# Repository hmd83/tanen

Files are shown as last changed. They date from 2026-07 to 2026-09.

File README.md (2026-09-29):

# TanenBase — Smart Hive Monitoring





A LoRaWAN beehive monitor that runs for years on three AAA primary lithium cells.

It weighs the hive, reads its temperature — and, with optional Bluetooth sensors,
temperature and humidity inside the hive — and reports over LoRaWAN to The Things
Network — then sleeps at about **4 µA**. Configuration and calibration happen
over Bluetooth from a web page, so there is no mobile app to install and nothing
to plug in once the lid is closed.

| | |
|---|---|
| **MCU** | Seeed Studio XIAO nRF54LM20A (Standard, non-Sense) |
| **Radio** | Wio-SX1262 LoRa kit — LoRaWAN Class A, OTAA, EU868 |
| **Sensors** | NAU7802 24-bit load-cell ADC · DS18B20 temperature · nPM1300 battery gauge · optional: up to 3 SwitchBot Outdoor Meter BLE temperature/humidity sensors (Extended Mode) |
| **RTOS / SDK** | Zephyr 4.4 via nRF Connect SDK v3.4.0 |
| **Sleep current** | ~4 µA (System OFF + GRTC wake) |
| **Battery life** | ~4.6 years on 3× AAA Li/FeS₂ (1200 mAh) at 15 min / 2 h reporting — ~10 y at 60 min / 4 h. With Extended Mode BLE sensors each uplink costs 139 mC instead of 63 mC: ~3.3 y / ~7 y |
| **Uplink** | 8 bytes — weight (999 kg range), temperature, battery, flags · +5 bytes per BLE sensor heard (max 23) |

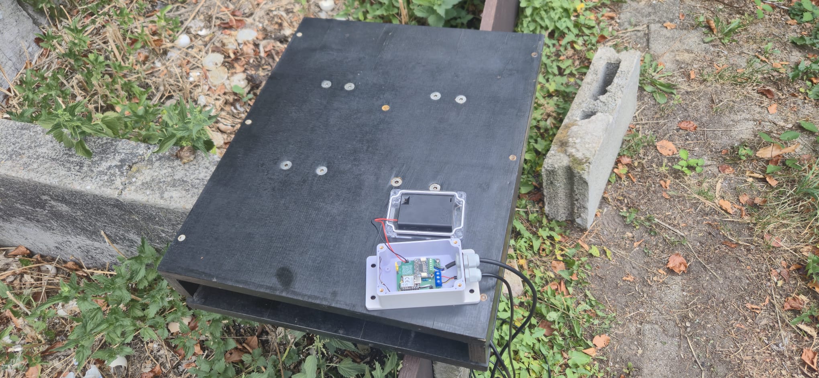
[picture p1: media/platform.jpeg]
The scale platform in the field


*A node in the field: the hive stands on the platform, the IP-rated enclosure
bolted to it holds the electronics and the battery pack, and the temperature probe
runs inside the hive.*

📺 **[Build workshop walkthrough (YouTube)](https://www.youtube.com/watch?v=t2ags30G7-o)** ·
🎬 **[Bench test clip](media/test.mp4)** (download — GitHub does not play repo-hosted video inline)

---

## In the field: apiary in Bühl (Baden)

A TanenBase runs under a hive in Bühl, Baden. It reports over LoRaWAN to a
gateway on Windeck Castle, about 4 km away, and sends one reading an hour.

| | |
|---|---|
| **Radio link** | ≈ 4 km to the gateway (3.6 km line of sight) |
| **Reporting** | once an hour |
| **Gateway** | Kerlink iStation, Windeck Castle, 378 m above sea level |
| **Live data** | 📈 **[beelogger dashboard — Bühl apiary](https://community.beelogger.de/tanen/beelogger1/beelogger_show.php)** (weight and temperature, updated hourly) |

<p>
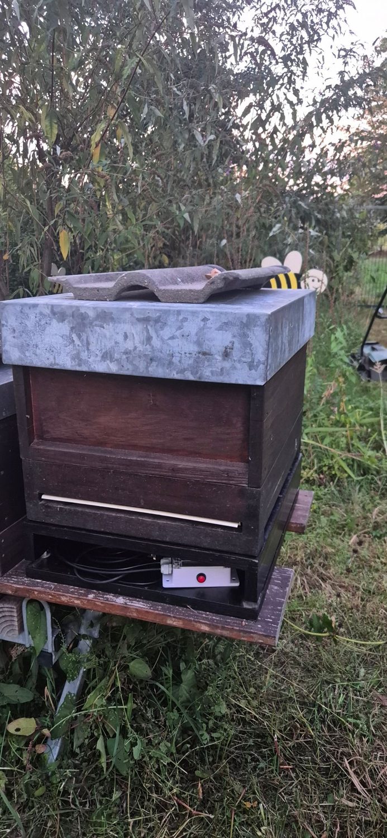
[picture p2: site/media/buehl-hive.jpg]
Beehive on the weighing platform with the station enclosure and its red button underneath
  
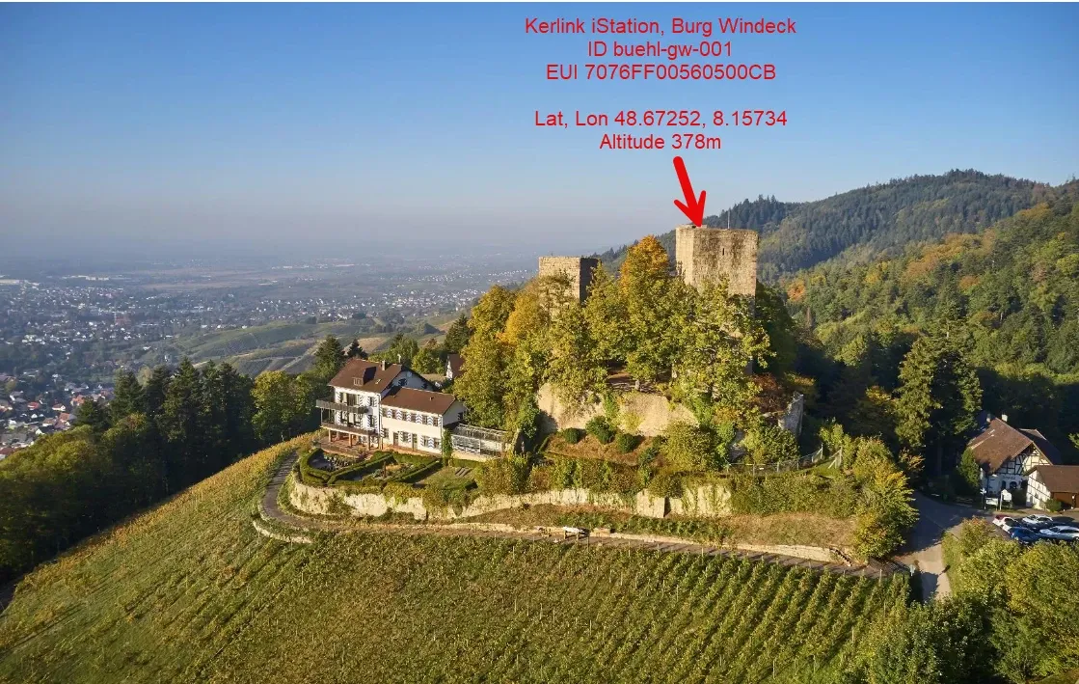
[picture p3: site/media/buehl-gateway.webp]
Windeck Castle above vineyards, arrow pointing at the tower carrying the gateway
  
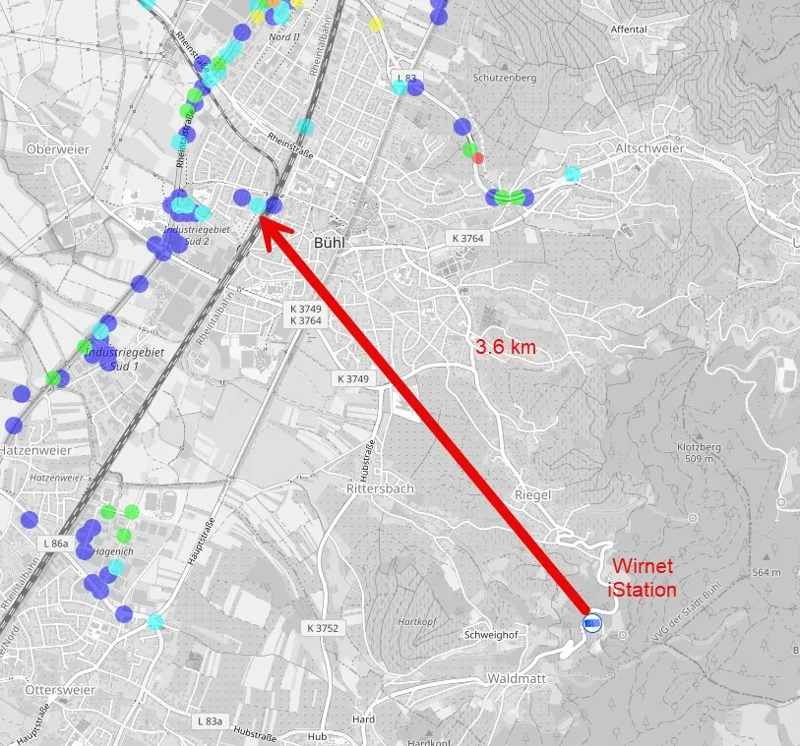
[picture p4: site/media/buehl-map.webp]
Map of Bühl with a red 3.6 km line from the gateway to the apiary
  
</p>

*Left to right: the hive on its platform, the enclosure with the red setup button
underneath; the gateway tower on Windeck Castle; the 3.6 km path from the
gateway to the apiary.*

---

## How it works

The firmware is a **single-pass state machine**, not a loop. Every wake is a cold
boot from System OFF: it checks why it woke, does one pass, and powers off again.

```
       wake reason
            │
    ┌───────▼────────┐  button / reset
    │     SETUP      │  BLE config service, sensors live, 180 s window
    └───────┬────────┘
            │
    ┌───────▼────────┐  timer
    │  MEASUREMENT   │  weight + temp + battery, anomaly check
    └───────┬────────┘
            │ delta exceeded, or heartbeat due?
    ┌───────▼────────┐  yes
    │  TRANSMISSION  │  BLE sensor scan (Extended Mode), SX1262 up, join if needed, uplink
    └───────┬────────┘
            │
    ┌───────▼────────┐
    │     SLEEP      │  System OFF, GRTC timed wake
    └────────────────┘
```

The radio is only powered when there is something to send. Between heartbeats
the node measures, compares against the last transmitted values, and goes back
to sleep without ever touching the SX1262 — which is where most of the battery
life comes from.

Full design notes: [`docs/ARCHITECTURE.md`](docs/ARCHITECTURE.md).

### Temperature compensation

A hive scale's real enemy is not resolution, it is thermal drift. Uncompensated,
the reference cell reports a **350 g peak-to-peak swing on a constant 22 kg
load** over a 17.5 K daily cycle — 16 g of phantom weight per kelvin, enough to
bury a real nectar flow.

The firmware corrects it with two parameters: one gain constant, plus a
first-order lag filter on the probe temperature that models the probe sitting a
few minutes behind the aluminium cell body. Residual scatter drops **6.5×, to
σ = 15.7 g**. The filtered temperature is carried in ZMS across System OFF, and
the tare stores the temperature it ran at as the correction's reference point.

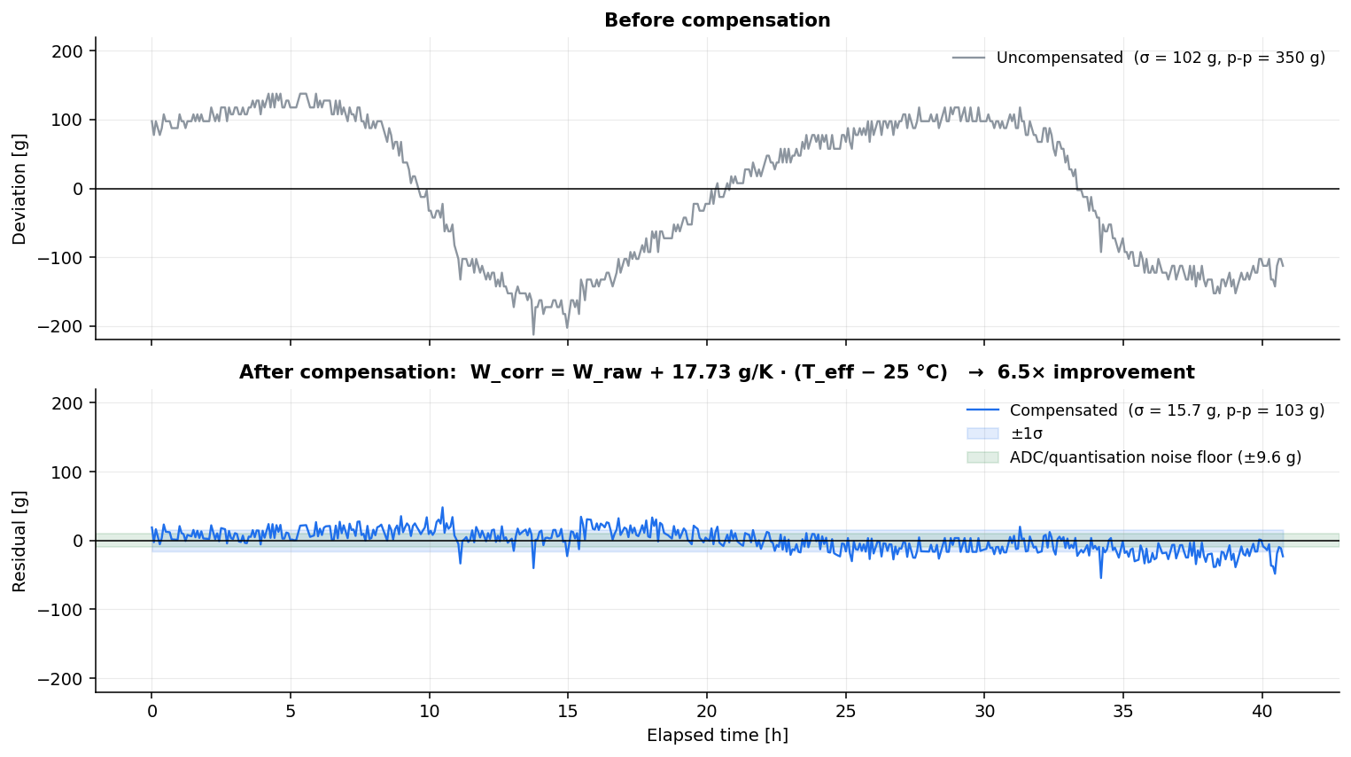
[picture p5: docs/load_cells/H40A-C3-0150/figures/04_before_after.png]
Before and after compensation


*Same 22 kg load, 40.7 h, one daily temperature cycle. σ 102.2 g → 15.7 g,
peak-to-peak 350 g → 103 g.*

**Validated in the field**, not just on the bench: six days outdoors with a
22.2 kg dead weight and the correction live left **+1.10 g/K** of temperature
sensitivity where the uncompensated cell had −16.6, and σ of 11.6 g against
63.1 g — measured on the *same samples*, by reconstructing the filter offline
and inverting the correction.

Six days in the field

*Days 4–6 are rain, not drift: +220 g arrived in two hours while the filtered
temperature moved 0.4 K, and 506 g of water was still in the wooden platform and
the concrete block at the end. Once the drying trend is modelled, the residual
thermal term across those days is +0.56 and −1.48 g/K — the correction holds
underneath the water.*

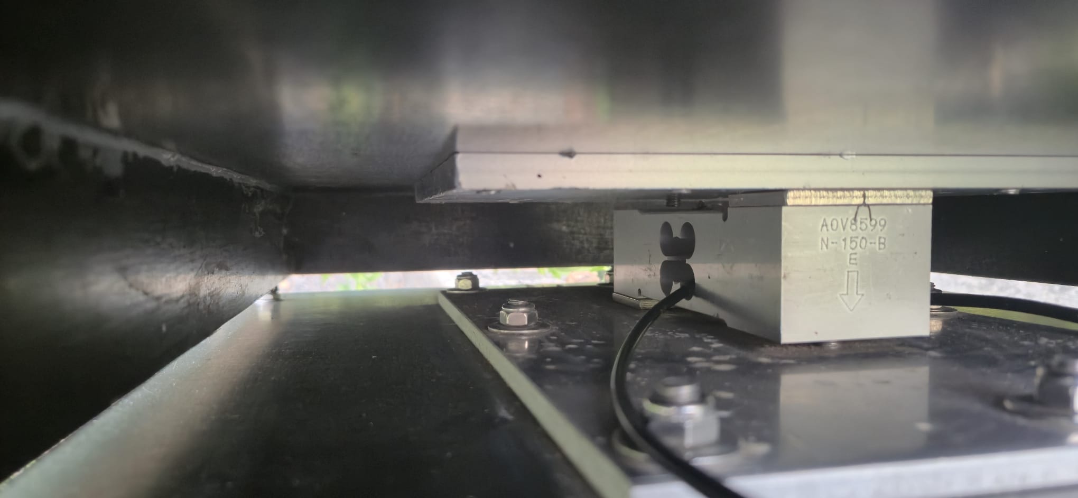
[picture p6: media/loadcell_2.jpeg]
Load cell and its mount


*The cell the shipped coefficient was fitted on — a Bosche H40A-C3-0150 single-point
cell bolted between two steel spreader plates. Worth staring at: the report
concludes the drift is **not** coming from the cell but from this mount, which
is 8× outside the OIML R60 envelope the cell is certified to.*

`k` is a property of the **cell plus its mount**, not of the cell alone —
re-characterise after any mechanical change. Which cell is fitted is therefore a
**runtime setting**, not a build flag: the setup page offers a generic cell (no
correction), the measured H40A-C3-0150, four named-but-uncharacterised cells
(Steinberg SBS-PF-150, Zemic L6E, TAL220, Flintec PC/SB — they run uncorrected
but the unit records which is fitted), or your own measured gain and lag, and
the correction picks its constants up from there.
Profile table and how to characterise a cell:
[`docs/load_cells/`](docs/load_cells/). Method, data, hold-out validation and
the (unflattering) hardware conclusions for the reference cell:
[`docs/load_cells/H40A-C3-0150/`](docs/load_cells/H40A-C3-0150/).

### Extended Mode — a look inside the hive

The scale tells you *that* a colony gained or lost weight. It cannot tell you
whether the colony is raising brood, holding its winter cluster, or sitting in
damp air. **Extended Mode** adds up to three off-the-shelf **SwitchBot Outdoor
Meter** Bluetooth sensors — at most two inside the hive and one outside — and
sends their temperature and humidity in the same uplink as the weight. No cable
through the hive wall and no extra gateway: the node's own nRF54LM20A radio
listens for them.

<p align="center">
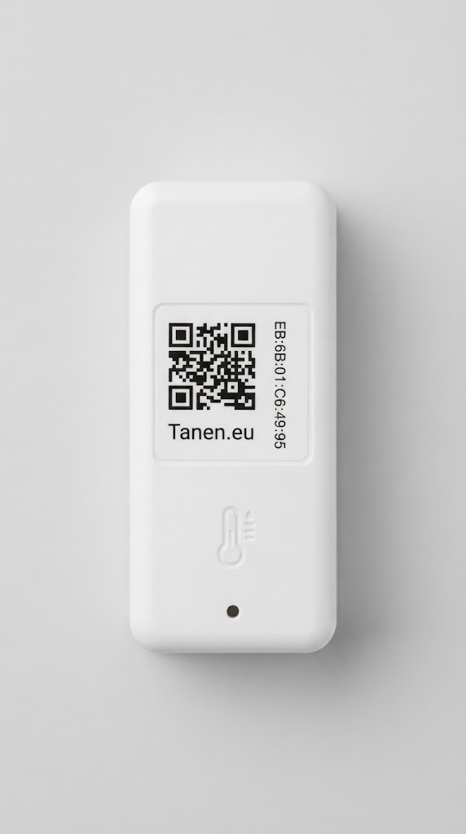
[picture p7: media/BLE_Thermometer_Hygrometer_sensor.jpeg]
SwitchBot sensor with a Tanen label showing a QR code, its Bluetooth address and Tanen.eu
  
  &nbsp;&nbsp;
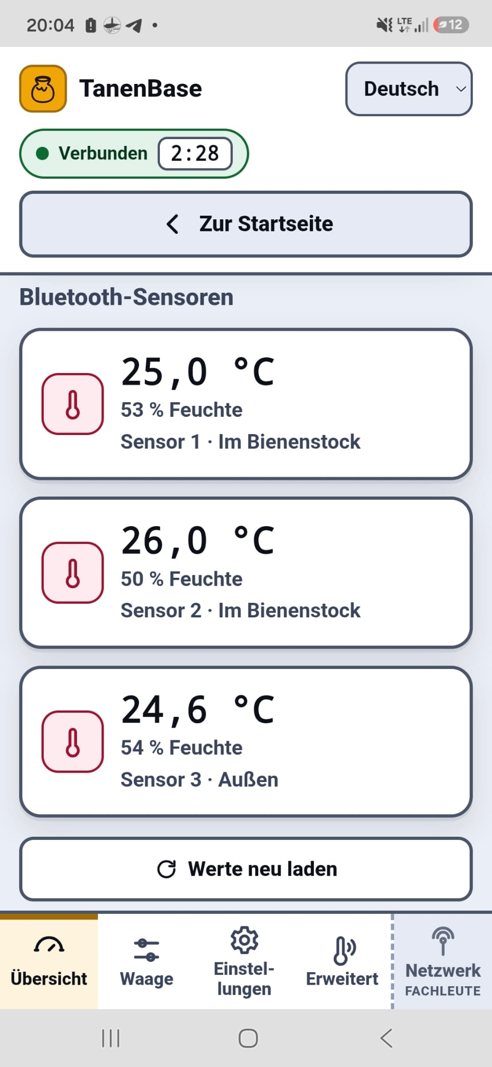
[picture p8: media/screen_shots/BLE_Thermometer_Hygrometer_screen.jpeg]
Setup page on a phone showing three Bluetooth sensors: two inside the hive, one outside
  
</p>

*Left: a sensor with its Tanen label — the Bluetooth address as text and as a QR
code. Right: sensors live on the setup page, two in the hive and one outside.*

- **Set up from the phone.** In the web page's *Erweitert* tab, scan the label's
  QR code (or type the address), choose *inside the hive* or *outside*, save.
  Readings appear within seconds, on that tab and on the overview.
- **Straight into BEEP and beelogger.** The outside sensor becomes `t` / `TempOut`
  (the DS18B20 moves to BEEP's `t_0`); the in-hive sensors map to `t_i`/`h_i`,
  `TempIn`/`FeuchteIn` and `TempIn2`/`FeuchteIn2`. Nothing to change on either
  platform.
- **Only when it counts.** The node scans for the sensors only on wakes that
  transmit and stops as soon as every sensor has been heard. Each sensor adds
  5 bytes to the uplink; one that is not heard costs no airtime and sets a flag
  instead.
- **What it costs.** A transmit wake with the scan measures **139 mC** instead of
  63 mC, so the pack lasts about **3.3 years** instead of 4.6 at 15 min / 2 h
  ([`docs/POWER_BUDGET.md`](docs/POWER_BUDGET.md)).

Wire format and GATT details:
[`docs/ARCHITECTURE.md`](docs/ARCHITECTURE.md#extended-mode-blocks).

---

## Repository layout

| Path | What it is |
|---|---|
| [`src/`](src/) | Firmware — `core/` (FSM, power, watchdog), `drivers/`, `features/`, `config/` |
| [`boards/`](boards/) | Application devicetree overlay for the target board |
| [`third_party/`](third_party/) | Vendored Seeed XIAO nRF54LM20A board definition (Apache-2.0) |
| [`Tanen_Base_pcb/`](Tanen_Base_pcb/) | KiCad carrier board — schematic, layout, gerbers |
| [`web/`](web/) | Web Bluetooth configuration page + standalone downlink encoder (no build step) |
| [`ttndecoder/`](ttndecoder/) | TTN payload formatters — one unified BEEP + beelogger decoder, plus the older per-platform ones |
| [`test_apps/measure_loop/`](test_apps/measure_loop/) | Standalone sensor bring-up app |
| [`docs/`](docs/) | Architecture, power budget, sprint log, TRD, open questions, German user manual (`BENUTZERHANDBUCH.md` + built HTML) |
| [`docs/load_cells/`](docs/load_cells/) | Load-cell characterisation — data, analysis, host replay of the compensation |
| [`media/`](media/) | Build photos and a bench-test clip |

---

## Building

**Requires** nRF Connect SDK **v3.4.0** and its bundled toolchain. The board
definition is out-of-tree and vendored, so no `west update` of extra manifests is
needed.

```powershell
git clone https://github.com/hmd83/tanen.git
cd tanen

# LoRaWAN credentials — never commit the real one
Copy-Item prj_credentials.conf.example prj_credentials.conf
#   then edit it and set your AppKey

.\build.ps1 debug        # logs on uart20 -> on-board CMSIS-DAP VCOM @115200
.\build.ps1 prod         # LOG off, size-optimized
.\flash_update.ps1       # flash, preserving stored config + calibration
```

`build.ps1` finds the SDK automatically (newest `vX.Y.Z` under `C:\ncs`). Override
with `$env:NCS_ROOT`, `$env:NCS_VERSION`, or `$env:NCS_TOOLCHAIN` if your install
lives elsewhere. On a mode change it forces `--pristine` for you, because
switching in place trips a stale-CMakeCache Kconfig failure.

Raw `west` equivalent, if you prefer:

```sh
west build -b xiao_nrf54lm20a/nrf54lm20a/cpuapp --no-sysbuild -- \
    -DBOARD_ROOT=$PWD/third_party/seeed-xiao-nrf54lm20a \
    -DOVERLAY_CONFIG="prj_credentials.conf;prj_production.conf"
```

**Gotchas worth knowing before your first build** — see
[`docs/PLAN.md`](docs/PLAN.md) Sprint 15 for the full list:

- Keep the build directory path **short** on Windows (MAX_PATH kills ninja).
- Do **not** add `-S cdc-acm-console`. It repoints the console at the nRF's own
  USBHS CDC, which never enumerates on this board — you get silence.
- pyocd cannot program the nRF54LM20A: its erase works, then its flash algorithm
  hard-faults and leaves the chip blank. Use OpenOCD (what `flash_*.ps1` do) or
  `west flash`.

---

## Provisioning a node

1. Flash, then press the user button to enter **SETUP**. The node advertises as
   `TanenBase` for 180 seconds.
2. Open [`web/index.html`](web/index.html) in Chrome or Edge (Web Bluetooth;
   Safari and Firefox do not support it) and connect.
3. Write the DevEUI, JoinEUI, and AppKey from your TTN device registration.
4. Tare the empty scale, then calibrate with a known reference weight. The tare
   also records the temperature it ran at — that becomes the reference point of
   the thermal correction, so tare at a temperature the hive actually sees.
5. Set the measurement and transmit intervals, and the anomaly thresholds.
6. Press **Done**. The node joins TTN and enters its normal cycle.

Everything above is also settable later by LoRaWAN downlink (FPort 10–13) and
persists in ZMS across reboots and firmware updates.
[`web/encoder.html`](web/encoder.html) builds those downlinks — pick the
parameter, type the value in human units, and copy the fPort plus hex/base64 for
the TTN console, or the whole `down/push` body for the TTN API. It is a separate
page with no Bluetooth at all, so it needs neither the node nor a pairing.

**Each physical unit needs its own DevEUI.** Leave `CONFIG_TANENBASE_DEV_EUI`
empty to derive a unique one from the SoC's factory hardware ID.

### The Things Network

Register the device as **LoRaWAN MAC v1.0.3**, OTAA, EU868, then install
[`ttndecoder/tanen-decoder.js`](ttndecoder/tanen-decoder.js) as the uplink
payload formatter (Payload formatters → Uplink → Custom Javascript formatter).

One formatter serves both supported platforms: it parses the frame once (8 bytes,
plus 5 per Bluetooth sensor in Extended Mode) and emits both key sets into the
same `decoded_payload`.

| Reading | BEEP key | beelogger key | Unit |
|---|---|---|---|
| Weight | `weight_kg` | `Gewicht` | kg |
| Temperature | `t` | `TempOut` | °C |
| Battery | `bv` | `VBatt` | V |
| Outside temp / humidity (BLE) | `t` / `h` | `TempOut` / `FeuchteOut` | °C / %RH |
| Inside #1 temp / humidity (BLE) | `t_i` / `h_i` | `TempIn` / `FeuchteIn` | °C / %RH |
| Inside #2 temp / humidity (BLE) | `t_1` / — | `TempIn2` / `FeuchteIn2` | °C / %RH |

**Extended Mode** adds up to three SwitchBot Outdoor Meters (at most two inside
the hive, one outside), set up in the web page's *Erweitert* tab by typing the
sensor's MAC or scanning a QR label. The node scans for them only on wakes that
transmit. An outside sensor takes over `t` / `TempOut` and the DS18B20 moves to
BEEP's `t_0`; without one, `t` / `TempOut` stay the DS18B20. Wire format in
[`docs/ARCHITECTURE.md`](docs/ARCHITECTURE.md#extended-mode-blocks).

Each platform stores the keys it knows and ignores the rest, so no per-platform
formatter juggling is needed. A failed sensor decodes to `null` on both sides,
never to a sentinel number. `flags`, `anomaly_weight`, `anomaly_temp` and
`heartbeat` ride along for TTN live-data debugging and are ignored by both
servers. The older single-platform formatters
([`beepdecoder.js`](ttndecoder/beepdecoder.js),
[`tanen-beelogger-decoder.js`](ttndecoder/tanen-beelogger-decoder.js)) are kept
for reference.

**BEEP** ([beep.nl](https://beep.nl)) — the webhook base URL **must** carry the
device key explicitly:

```
https://api.beep.nl/api/lora_sensors?key=<DevEUI>
```

Without it BEEP decodes your payload perfectly and then silently drops it,
because it falls back to a TTN Stack **V2** field (`payload_fields.hardware_serial`)
that V3 webhooks do not send. This one cost real debugging time — see
[`docs/PLAN.md`](docs/PLAN.md) Sprint 14.

**beelogger** ([beelogger.de](https://beelogger.de)) — the community server
takes the `Gewicht` / `TempOut` / `VBatt` names its own payload formatter uses,
which is exactly what the decoder emits. Webhook base URL:

```
https://community.beelogger.de/<username>/{/devID}/beelogger_log.php?Passwort=<password>&LORA=1
```

- `<username>` — your community-server account
- `{/devID}` — filled in by TTN per uplink, so name the TTN devices
  `beelogger1`, `beelogger2`, … to match the stations registered on the server
- `<password>` — the same one for every station, which is what lets a **single
  webhook serve the whole TTN application** instead of one per node
- `LORA=1` — tells the server the record arrives via LoRaWAN

Both platforms are confirmed receiving from the unified decoder.

---

## Hardware

The carrier board is a passive breakout: XIAO socket, Wio-SX1262 socket, screw
terminals for the load cell and the DS18B20, battery input, and the bulk
capacitor. KiCad sources and fabricated gerbers are in
[`Tanen_Base_pcb/`](Tanen_Base_pcb/).

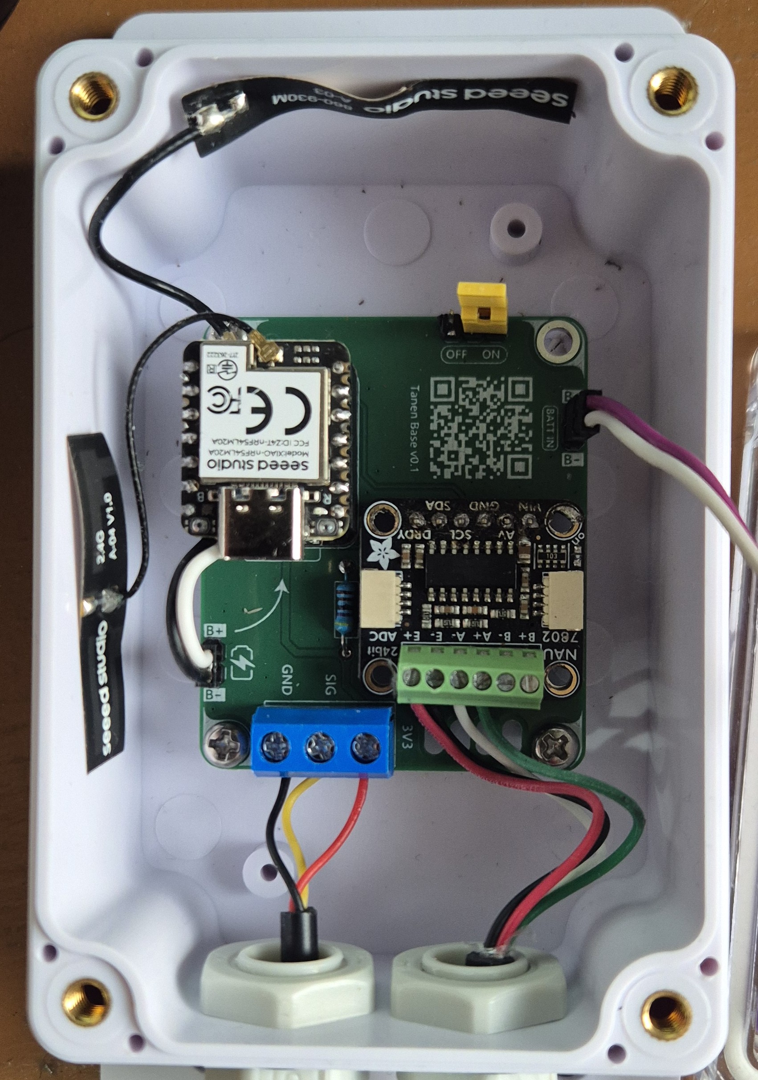
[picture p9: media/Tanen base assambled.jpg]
Assembled node


*Assembled in an IP-rated enclosure — XIAO nRF54LM20A top-left, NAU7802
load-cell amplifier on the right, external 868 MHz antenna, and cable glands for
the load cell and temperature probe.*

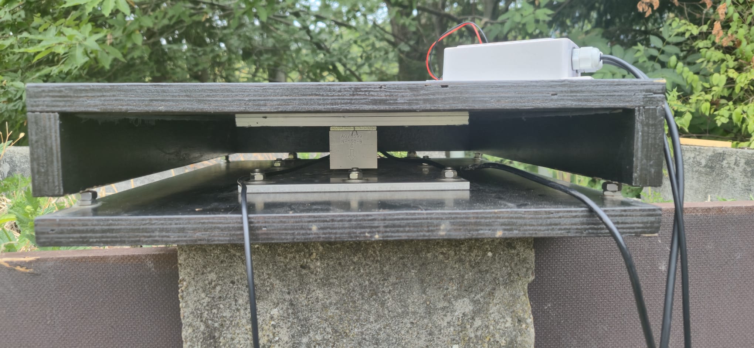
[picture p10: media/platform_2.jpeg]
Platform seen from the side


*The weighing platform end-on: a single-point cell carries the whole top frame
from the centre, so the hive can sit anywhere on it without changing the
reading. Enclosure sits on the top deck, cable runs down to the cell.*

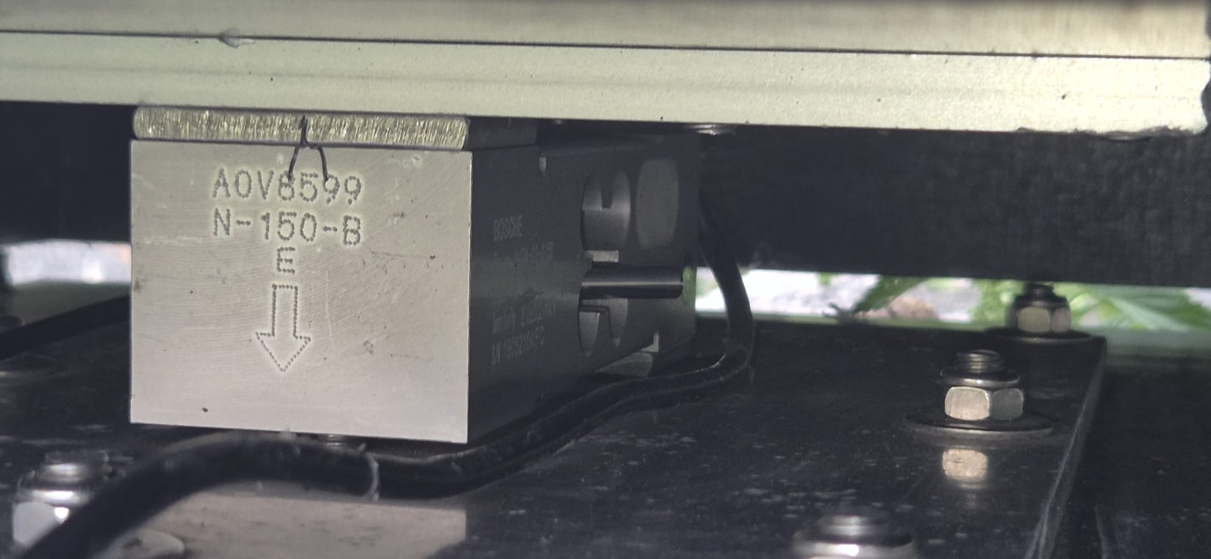
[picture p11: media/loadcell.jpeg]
Load cell mounted under the platform


*Underside — the cell between the top plate and the base, load arrow pointing
down. E<sub>max</sub> = 150 kg, which is oversized for a hive: a 100 kg cell
would give ~1.5× better signal-to-noise at the same absolute drift.*

**Optional Extended Mode sensors:** up to three SwitchBot Outdoor Meters (model
WoIOSensorTH), each on its own battery. Nothing to wire — print a label with the
sensor's Bluetooth address as plain text and as a QR code (for example
`EB:6B:01:C6:49:95`) and stick it on; the setup page reads either.

> The KiCad project files are still named **XIAO_nRF54L15 V1**, while the board
> itself is silkscreened *Tanen Base v0.1*. That is deliberate: all XIAO modules
> share one 21 × 17.5 mm footprint and pinout, so the nRF54L15 and nRF54LM20A are
> drop-in replacements on this carrier — only the GPIO number behind each header
> pin changes, and that is handled in the devicetree overlay.
> [`Tanen_Base_pcb/README.md`](Tanen_Base_pcb/README.md) has the full pin-by-pin
> mapping.

**Battery:** 3× BEVIGOR AAA 1.5 V lithium (Li/FeS₂, 1200 mAh) in series —
4.5 V nominal, **5.2 V measured fresh at room temperature** — **primary /
non-rechargeable**. The firmware
deliberately deletes `charging-enable` from the nPM1300 charger node; with it
armed, applying USB power would push charge current into non-rechargeable cells.
Do not re-enable it unless you have also changed the chemistry.

⚠️ **The pack sits above the nPM1300's recommended VBAT maximum for
essentially its whole life.** The window is 2.3–4.45 V recommended, 5.5 V
absolute. At µA drain Li/FeS₂ holds a ~1.79 V/cell plateau that is nearly
independent of depth of discharge and **rises with temperature**, so the pack
only drops back inside the recommended range as the cells die. Worst case is a
warm hive with cells at the top of the 1.79–1.83 V fresh spread: **5.49 V against
a 5.5 V absolute maximum.** This is a deliberate, documented deviation — see
[`docs/POWER_BUDGET.md`](docs/POWER_BUDGET.md) §5.2 for the chemistry data,
mitigations, the ER14505 AA Li-SOCl₂ cell this replaced, and what the swap bought
(no passivation, −40 °C rating, large pulse margin) and cost (9.3 y → 4.6 y).

Measure cells before assembly and reject any above ~1.80 V; keep the enclosure
out of direct sun.

---

## Status

Running in the field — see [the Bühl apiary](#in-the-field-apiary-in-bühl-baden). The core loop — measure, delta-detect, uplink, sleep — is
verified end to end on hardware, including ingestion by both BEEP and the
beelogger community server from the same uplink. Extended Mode is verified on
hardware too (2026-09-13): three sensors live in the setup page, their blocks in
the uplink, and the transmit wake measured on the PPK2.

Not yet done: MCUboot/OTA is wired up (`sysbuild.conf`, `pm_static.yml`) but
**unverified on this module**, and no production signing key is provisioned.
Open design questions are tracked in
[`docs/OPEN_QUESTIONS.md`](docs/OPEN_QUESTIONS.md).

---

## Contributing

See [CONTRIBUTING.md](CONTRIBUTING.md). Bug reports and hardware notes from
anyone running this on real hives are especially welcome.

---

## Credits

**Hussein Daj** — project owner, product design, hardware design (carrier PCB,
sensor selection, power architecture), firmware direction, and all hardware
bring-up, PPK2 power measurement, and field validation.

**[Claude Code](https://claude.com/claude-code)** (Anthropic) — firmware
co-development. Worked alongside the author on the state machine, drivers,
BLE GATT service, power-management path, watchdog and fault-tolerance layer, the
nRF54L15 → nRF54LM20A port, the load-cell temperature-drift analysis and the
compensation formula it produced, and this documentation. Every change was
reviewed and hardware-verified by the author before it landed.

**[Google Gemini](https://gemini.google.com)** — product design input:
requirements shaping, use-case analysis, and design-decision review during the
concept and specification phase.

### Third-party work this builds on

- [Zephyr RTOS](https://zephyrproject.org) and the
  [nRF Connect SDK](https://developer.nordicsemi.com) — Apache-2.0
- [Seeed Studio](https://github.com/Seeed-Studio/platform-seeedboards) — XIAO
  nRF54LM20A Zephyr board definition, vendored in
  [`third_party/`](third_party/) — Apache-2.0
- [loramac-node](https://github.com/Lora-net/LoRaMac-node) — LoRaWAN MAC
- [BEEP](https://beep.nl) — open beehive monitoring platform and data API
- [beelogger](https://beelogger.de) — open hive-scale project and community
  server; its field names are mirrored by the uplink decoder

---

## License

Apache-2.0 — see [LICENSE](LICENSE) and [NOTICE](NOTICE). This covers the
firmware, the hardware design files, and the documentation.

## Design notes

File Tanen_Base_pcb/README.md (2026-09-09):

# TanenBase carrier PCB

KiCad 7+ project for the TanenBase carrier board — the passive breakout that
holds the XIAO module, the Wio-SX1262 LoRa kit, the load-cell terminal block,
the DS18B20 terminal block, and the battery connections.

| File | Contents |
|---|---|
| `XIAO_nRF54L15 V1.kicad_sch` | Schematic |
| `XIAO_nRF54L15 V1.kicad_pcb` | Board layout |
| `XIAO_nRF54L15_V1_Gerber/` | Gerbers + drill files (as fabricated) |
| `XIAO_nRF54L15_V1_Gerber.zip` | Same, zipped for the fab house |
| `simulation_image_top.png` / `_bottom.png` | 3D renders |

---

## Why is this named "nRF54L15" when the firmware targets the nRF54LM20A?

**Because the board does not care, and renaming it would invalidate a PCB that
has already been fabricated and verified.**

The Seeed Studio XIAO family is a fixed mechanical and electrical standard: all
XIAO modules share the same **21 × 17.5 mm** outline, the same two 7-pin 2.54 mm
headers, and the same pin *roles* in the same physical positions:

```
        ┌──────────────┐
   5V ──┤              ├── D0
  GND ──┤              ├── D1
  3V3 ──┤     XIAO     ├── D2
  D10 ──┤   21×17.5mm  ├── D3
   D9 ──┤              ├── D4
   D8 ──┤              ├── D5
   D7 ──┤              ├── D6
        └──────────────┘
```

The **XIAO nRF54L15** and the **XIAO nRF54LM20A** are drop-in mechanical
replacements for each other on this carrier. The footprint, the outline, the
castellated pads, the header pitch, and the power pin positions are identical.
Only the GPIO number sitting behind each header pin differs, and that is a
firmware concern, resolved entirely in the devicetree overlay
[`boards/xiao_nrf54lm20a_nrf54lm20a_cpuapp.overlay`](../boards/xiao_nrf54lm20a_nrf54lm20a_cpuapp.overlay).

So the KiCad project *filename* is historical — it records the module that was in
the socket when the board was laid out. The board itself is silkscreened
**"Tanen Base v0.1"**, not with any module name. The gerbers in this directory
are the ones that were actually fabricated; renaming the project would mean
regenerating them for zero electrical benefit.

### Header role mapping across both modules

Firmware keeps the header **roles** fixed, so the carrier's netlist is valid for
either module:

| XIAO Pin | Carrier net | nRF54L15 GPIO | nRF54LM20A GPIO |
|---|---|---|---|
| D0 | DS18B20 data (1-Wire) — mandatory K1 cut, see below | P1.04 | P1.00 |
| D1 | SX1262 DIO1 | P1.05 | P1.31 |
| D2 | SX1262 RST + external TanenButton | P1.06 | P1.30 |
| D3 | SX1262 BUSY | P1.07 | P1.29 |
| D4 | SX1262 NSS | P1.10 | P1.03 |
| D5 | LORA_RF_SW1 (Wio-SX1262 ant. switch) | P1.11 | P1.07 |
| D6 | NAU7802 SCL | P2.08 | P1.08 |
| D7 | NAU7802 SDA | P2.07 | P1.09 |
| D8 | SPI SCK | P2.01 | P1.04 |
| D9 | SPI MISO | P2.04 | P1.05 |
| D10 | SPI MOSI | P2.02 | P1.06 |

### Mandatory rework: cut the Wio-SX1262 K1 button off D0

The Wio-SX1262 for XIAO ships a user button **K1 (TS-1188E)** and a **10 kΩ
pull-up R2 to +3V3** on **D0** — the net this carrier uses for the DS18B20
1-Wire data line.

**This is not optional and not a corner case: with K1/R2 fitted, 1-Wire does not
read at all.** Observed on hardware. R2 lands in parallel with the carrier
1-Wire pull-up (~3.2 kΩ effective) on top of the switch stub loading; the exact
failure mechanism was not chased down because the cut fixes it outright.

**The cut:** the single trace from the K1/R2 node to the D0 castellated pad on
the Wio board. One cut lifts *both* K1 and R2 off D0 and leaves the D0
pass-through (XIAO → carrier → DS18B20 terminal) intact. Verify by continuity:
XIAO D0 still reaches the DS18B20 terminal, K1 node now isolated from D0.
**Done on the units built so far** — repeat it on every new Wio-SX1262 before
assembly, or temperature reads will fail on that unit.

**Optional afterwards:** the cut leaves K1 + R2 as a self-contained
button-with-pull-up, currently isolated and unused. Wiring that node to **P0.09**
on the XIAO — in parallel with the module own user button — makes K1 a second
TanenButton with **no firmware change**: P0.09 is already the armed System OFF
wake source (`gpio_disconnect_all()` in [`src/core/power.c`](../src/core/power.c))
and R2 reinforces the internal pull-up. P0.09 is not on any header, so that wire
has to land on the XIAO on-board switch pad.

### External button: D2 (P1.30) — shares the SX1262 NRESET net

> **Field-verified 2026-09-09** — bare switch to GND on D2, wake from System OFF
> into SETUP, no issues observed.

The second TanenButton lands on **D2 = P1.30**, the same net as the SX1262
**NRESET**. D2 is on a 7-pin header, so **carrier v0.1 already routes it** — no
flying wire, and v0.2 needs no new net. (It was on D19 = P0.00, a bottom pad,
until 2026-09-07; **D19 is now free**.)

Wiring: a plain momentary switch from D2 to GND. Nothing else — no pull-up, no
cap. The SoC's internal pull-up (R_PU = 12 / 14 / 16 kΩ min/typ/max) holds the
line high while the pin is sense-armed in System OFF, and that is also what
keeps the SX1262 out of reset.

**Why sharing a reset line is acceptable here.** SETUP is a once-a-year
calibration action and the station is asleep 99.8 % of the time (185 s awake per
day at T_meas = 900 s / T_tx = 14400 s, from `docs/POWER_BUDGET.md` §1):

- **Asleep (99.8 %)** — press pulls NRESET low: the SoC wakes *and* the SX1262
  resets. The radio reset is free, because every wake is a full SoC reset and
  the sx126x driver drives NRESET low at device init anyway.
- **Awake (0.2 %)** — the pin is a driver-owned output, so the press is not
  latched and is simply lost. Shorting a standard-drive pad to GND is harmless:
  I_OH,SD is 1 / 3 / 4 mA against a 15 mA recommended all-GPIO budget. The SETUP
  LED is the user's feedback — no LED, press again.
- **Switch fails closed** — NRESET held low: wake loop draining the cell *and* a
  radio stuck in reset. Missing uplinks make it visible server-side within one
  heartbeat interval.

Add **100 nF to GND** at the switch only if the button wire leaves the
enclosure. On D19 a coupled glitch cost a spurious boot; on D2 it also resets
the radio, possibly mid-TX. 100 nF against the ~14 kΩ pull-up is ~1.4 ms —
harmless next to the driver's 20 ms reset pulse.

Port note: any wake-capable port works. The nRF54LM20A datasheet *Port
capabilities* table lists P0, P1 and P3 as wakeup sources with pin sense/detect
and GPIOTE; **P2 has none of the three** and cannot wake the system at all.
Avoid D22/D23 (P0.03/P0.04 carry GRTC PWM / CLKOUT32K).

Firmware already supports it: `button_arm_sense()` in
[`src/core/power.c`](../src/core/power.c) arms P0.09 and P1.30 identically, and
either press wakes into SETUP.

### Differences that *are* worth knowing

These do not affect the carrier board, but they change firmware behaviour:

- **Battery sensing.** The nRF54L15 module has no PMIC — the L15 firmware read
  VBAT through a divider on an ADC pin. The **nRF54LM20A carries an on-board
  Nordic nPM1300**, and the firmware reads its factory-trimmed VBAT ADC instead.
  Nothing on the carrier changed; the divider was on the module side.
- **Antenna switch.** The L15 build had to sequence an RF switch on P2.03/P2.05.
  On the LM20A those pins belong to the on-board NOR flash. The Wio-SX1262 kit
  brings its own switch control out to header pin **D5 = P1.07 (LORA_RF_SW1)**;
  the firmware never drives it, because the radio is configured
  `dio2-tx-enable` and the SX1262 switches the path from DIO2. D5 is therefore
  **committed to an RF control net and is not a spare GPIO** — do not put a
  button, pull-up, or anything else on it.
- **On-board NOR flash.** The LM20A has a py25q64 on P2.00–P2.05. Firmware must
  put it into deep power-down before System OFF or it costs ~14 µA. Again,
  module-side only.

---

## Fabrication notes

- 2-layer board, standard 1.6 mm FR4, HASL or ENIG both fine.
- No components on the bottom layer other than the silkscreen.
- The 470 µF low-ESR bulk capacitor on the battery rail is **mandatory**, not
  optional — the LoRa TX burst peaks around 92 mA and the chosen ER14505 AA
  Li-SOCl₂ cell is rated 100 mA continuous. See
  [`docs/POWER_BUDGET.md`](../docs/POWER_BUDGET.md) §6.
- The battery input is wired straight to the XIAO **BAT** pin, i.e. the nPM1300
  VBAT input: **2.3 V min, 4.45 V max recommended, 5.5 V absolute**. Anything
  connected there must stay inside that window at fresh open-circuit *and* at
  end of life. See `docs/POWER_BUDGET.md` §8.

> **Safety:** the firmware deletes `charging-enable` from the nPM1300 charger
> node on purpose. This design runs a **primary, non-rechargeable** Li-SOCl₂
> cell. Do not fit a rechargeable cell and do not re-enable charging without
> changing both together.

---

## License

The hardware design files in this directory are released under the same
[Apache-2.0](../LICENSE) license as the rest of the project.

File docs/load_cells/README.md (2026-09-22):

# Load cells

TanenBase is not tied to one load cell. Which cell is under the hive is a
**runtime setting**, picked on the setup page (Scale → Load cell) and stored in
ZMS, so one firmware image serves every build of the frame.

The setting selects the two constants of the temperature correction
([`../../src/features/measurement/tempcomp.c`](../../src/features/measurement/tempcomp.c)):
a gain `k_c` in mg/K and a thermal lag `τ` in seconds. It does **not** touch the
zero offset or the scale factor — those come from the tare and calibrate steps
and are per unit regardless of the profile.

## Profiles

| id | Profile | `k_c` | `τ` | Status |
|---:|---|---:|---:|---|
| 0 | Generic / unknown | 0 mg/K | 1500 s | No correction. The weight follows the daily temperature — ≈350 g p-p on the reference frame. |
| 1 | Bosche **H40A-C3-0150** | 17734 mg/K | 1500 s | **Measured**, 40 h sweep + 144 h field validation → [`H40A-C3-0150/`](H40A-C3-0150/) |
| 2 | Steinberg **SBS-PF-150** | 0 mg/K | 1500 s | **Not characterised** — field run planned. |
| 3 | Custom | from the stored record | from the stored record | Your own measured gain and lag, entered on the setup page. |
| 4 | **Zemic L6E / L6E3** | 0 mg/K | 1500 s | **Not characterised.** |
| 5 | **TAL220 / TAL220B** | 0 mg/K | 1500 s | **Not characterised.** |
| 6 | **Flintec PC / SB** | 0 mg/K | 1500 s | **Not characterised.** |

One entry per model, not per capacity: `k_c` is an absolute mg/K dominated by
the mount, so a 150 kg and a 200 kg version of the same cell in the same frame
land close enough that the variant is not worth a row.

A named-but-uncharacterised profile behaves **exactly** like generic — gain 0,
no correction. The label still earns its place: the unit records which cell is
bolted under the hive, and a later firmware can fill the constants in without
the beekeeper touching anything, because `config_get_lc()` resolves non-custom
profiles from this table on **every read** rather than from the stored copy.

The ids are the GATT contract (`LC_PROFILE_*` in
[`../../src/config/config.h`](../../src/config/config.h)) — **append, never
reorder.** That is why `LC_PROFILE_CUSTOM` sits at 3, in the middle: it was
there before the named cells were added. The setup page lists it last anyway;
the dropdown order and the id order are independent.
`CONFIG_TANENBASE_LC_DEFAULT_PROFILE` picks what a freshly flashed unit runs
until the setup page stores something.

## Why an uncharacterised cell ships with gain 0

`k_c` is a property of the **cell plus its mount**, not of the cell model. The
H40A's datasheet temperature effect on zero (±0.014 %FS/10 K → 2.1 g/K) is
**8× smaller** than the 17.7 g/K the assembled frame actually shows: most of the
drift is the mount, not the element.

So a plausible-looking number copied from a datasheet — or from a different
cell of the same class — is not a conservative default. If it has the wrong
sign or magnitude the correction *adds* error, silently, and it looks like the
cell is bad. Uncorrected is the honest starting point; anything else has to be
measured.

## Characterising a cell from a production week

The reference sweep was a bench run with a separate logger. You do not need one:
a station already reports raw weight and probe temperature, which is the whole
input to the fit. This is the route planned for the SBS-PF-150.

1. **Put the cell on a profile with gain 0** — its own named profile, or
   generic. This matters: the fit needs the **uncorrected** weight. A run
   logged with a correction already active has to be inverted first
   ([`H40A-C3-0150/analysis/field_validation.py`](H40A-C3-0150/analysis/field_validation.py)
   does that, but it is avoidable work).
2. **Put a dead weight on it and leave it alone.** 20–25 kg of something that
   does not evaporate, gain moisture or get walked on. No colony: a hive's real
   mass change is exactly the signal you are trying to separate the drift from.
   Outdoors, in the frame it will actually live in — the mount is most of what
   you are measuring.
3. **Shorten the uplink interval for the week.** At the 4 h heartbeat default a
   week gives ~42 points, and the daily cycle is what carries the information.
   Set *Senden alle* to 15–30 minutes on the setup page (*Einstellungen*) for
   the duration; 300–650 samples is the range the reference fit worked in.
   Put it back afterwards — that cadence costs battery (see
   [`../POWER_BUDGET.md`](../POWER_BUDGET.md)).
4. **Collect a full week including one clear hot day and one cold night.** The
   fit is driven by the temperature *span*: the reference run got 17.5 K.
   Rain is not fatal but it is a confounder — wood and concrete absorb
   hundreds of grams and give it back over days (H40A report §9).
5. **Export the uplinks.** Any sink works (TTN Storage Integration, BEEP, your
   own MQTT log). The decoder in [`../../ttndecoder/`](../../ttndecoder/) gives
   `weight_kg` / `Gewicht` in kg and `t` / `TempOut` in °C. Reshape to the
   semicolon CSV the analysis script expects:

   ```
   time;T_C;W_raw_kg
   2026-08-10T00:03:17Z;23.0;22.11
   ```

6. **Fit it.** Point
   [`H40A-C3-0150/analysis/tempcomp_analysis.py`](H40A-C3-0150/analysis/tempcomp_analysis.py)
   at the CSV. It reports `k`, sweeps `τ`, and prints the residual σ with and
   without the correction. Uneven sampling is fine — the filter uses the real
   `Δt` between rows — but a long gap re-seeds nothing, so check for holes.
7. **Sanity-check before shipping it.** `k_c = -k`. If σ does not improve by a
   clear multiple, or the sign differs from the reference cell's, something
   else moved during the week — do not enter that number. Hold-out validation
   (§3 of the H40A report) is the cheap way to tell a fit from a coincidence.
8. **Enter it as “own measured values”** (g/K and minutes), re-tare, and watch
   the dead weight for a few more days before trusting it.

## Adding a profile

1. **Measure.** Constant known load, 40 h minimum, one full daily temperature
   cycle, logging raw weight + probe temperature — on the bench, or from a
   production week as above. Method, pitfalls and the pass criteria are in
   [`H40A-C3-0150/README.md`](H40A-C3-0150/README.md) §9.
2. **Fit.** `python H40A-C3-0150/analysis/tempcomp_analysis.py` against your CSV
   gives `k`, `τ` and the residual σ. Sanity-check it on a hold-out window (§3)
   — a fit that only works on its own data is not a profile.
3. **Replay it on the firmware arithmetic** before believing it:
   `gcc -O2 -std=c99 -o host_test H40A-C3-0150/firmware/host_test.c H40A-C3-0150/firmware/tanen_tempcomp.c -lm`.
   The integer implementation has to land on the Python model's numbers.
4. **Enter it as “own measured values”** on the setup page (gain in g/K, lag in
   minutes) and let it run on a dead weight for a few days before trusting it.
5. Only then add it to `lc_profiles[]` in
   [`../../src/config/config.c`](../../src/config/config.c), with a directory
   here holding the data and the report.

One caveat that saves a re-measurement: `τ` describes the lag between the
temperature probe and the cell body, so it belongs to the **frame and the probe
placement**, not to the cell. Every characterised profile so far carries the
same 1500 s, and the optimum is broad — 15–40 min all land within 1 g. It is
`k_c` that needs the work.

## Changing the profile does not invalidate the tare

The correction is `k_c · (T_eff − T_ref)`, which is zero at `T_ref` for **any**
gain. `T_ref` is the temperature captured at the last tare, so switching
profiles leaves the zero where it was — no re-tare needed, only a re-tare after
mechanical changes.

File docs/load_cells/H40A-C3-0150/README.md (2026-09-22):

# Temperature Drift Characterisation — Bosche H40A-C3-0150

**Project:** TANEN BASE · open-source hive monitoring
**Device under test:** Bosche `H40A-C3-0150` single-point aluminium load cell (OIML R60 class C3, E<sub>max</sub> = 150 kg)
**Measurement period:** 2026-08-10 00:03 UTC → 2026-08-11 16:48 UTC (40.7 h)
**Samples:** 572 @ 4.27 min
**Load:** ~22.0 kg, static
**Raw data:** [`data/Loadcell_B.csv`](data/Loadcell_B.csv)
**Reproduce:** `python analysis/tempcomp_analysis.py`
**Field validation:** 2026-08-16 → 08-21, 144 h on a dead weight — **passed**, see §9

---

## TL;DR

Uncompensated, the cell reports a **350 g peak-to-peak swing on a constant 22 kg load** over a 17.5 K daily temperature cycle. That is 16 g of phantom weight per kelvin.

A two-parameter correction — one gain constant plus a first-order thermal lag filter — reduces the error to **σ = 15.7 g**, a 6.5× improvement, landing within ~1.6× of the digitisation noise floor.

```
W_corr = W_raw + 17.73 g/K · (T_eff − 25 °C)
T_eff[n] = T_eff[n−1] + α · (T[n] − T_eff[n−1]),   τ = 25 min
```

This runs on-device: [`src/features/measurement/tempcomp.c`](../../../src/features/measurement/tempcomp.c), `CONFIG_TANENBASE_TEMPCOMP=y` by default — see §6. Six days in the field on a dead reference weight then confirmed it: **+1.10 g/K residual, σ 11.6 g** (§9).

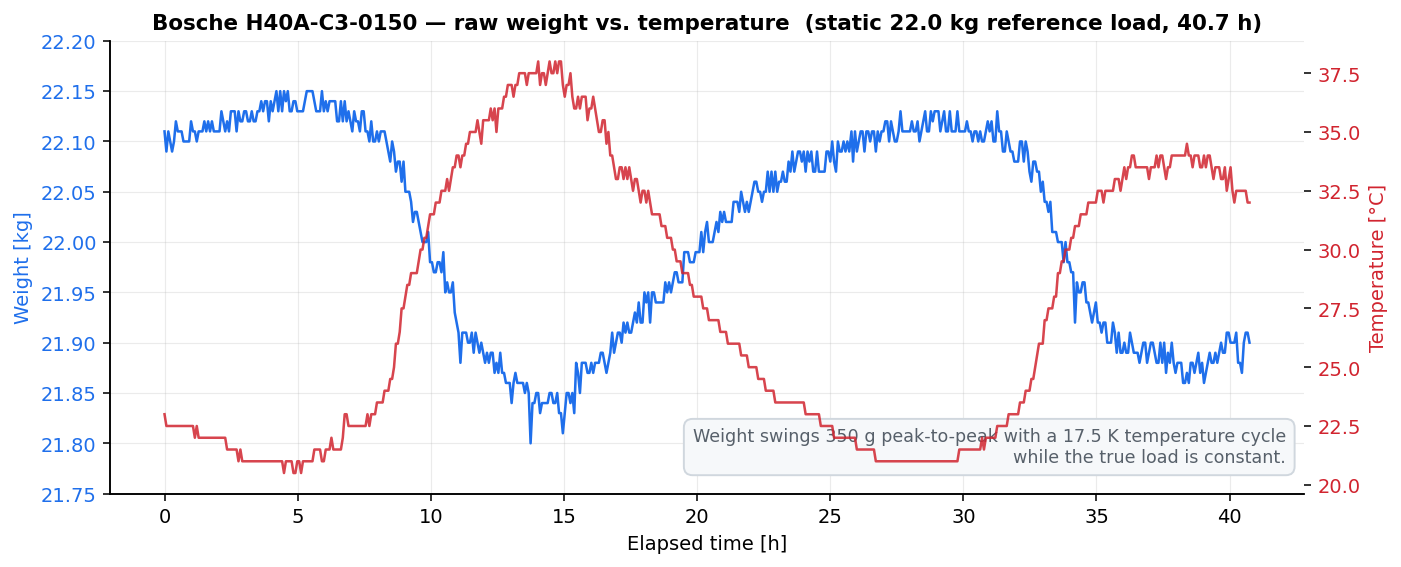
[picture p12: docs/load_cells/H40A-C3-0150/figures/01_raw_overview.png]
Raw overview


---

## 1. Results

| Metric | Uncompensated | Compensated | Improvement |
|---|---:|---:|---:|
| Std deviation σ | 102.2 g | **15.7 g** | 6.5× |
| Peak-to-peak | 350 g | **103 g** | 3.4× |
| P95 absolute error | 168 g | **29.9 g** | 5.6× |
| Relative to 150 kg FS | 0.233 % | **0.010 %** | — |

**Fitted model coefficients**

| Parameter | Value | Note |
|---|---|---|
| `k` (temperature coefficient) | **−17.734 g/K** | 95 % CI ± 0.226 g/K |
| `τ` (thermal time constant) | **25 min** | optimised, see Fig. 3 |
| `T_ref` | 25 °C | arbitrary; choose your tare temperature |
| `r²` | 0.9765 | T<sub>eff</sub> vs. W |
| Noise floor | 9.6 g | sample-to-sample, includes 10 g quantisation |

Before and after

---

## 2. The apparent hysteresis is transport lag, not mechanical hysteresis

Plotting weight directly against the instantaneous sensor temperature opens a visible loop (~26 g gap between rising and falling branches). This is not creep and not spring-element hysteresis — it is the temperature sensor and the cell body being at different temperatures during a ramp.

Passing the temperature through a single-pole low-pass filter with τ = 25 min collapses the loop to **1.2 g** and lifts r² from 0.964 to 0.977. No hysteresis term is needed in the model.

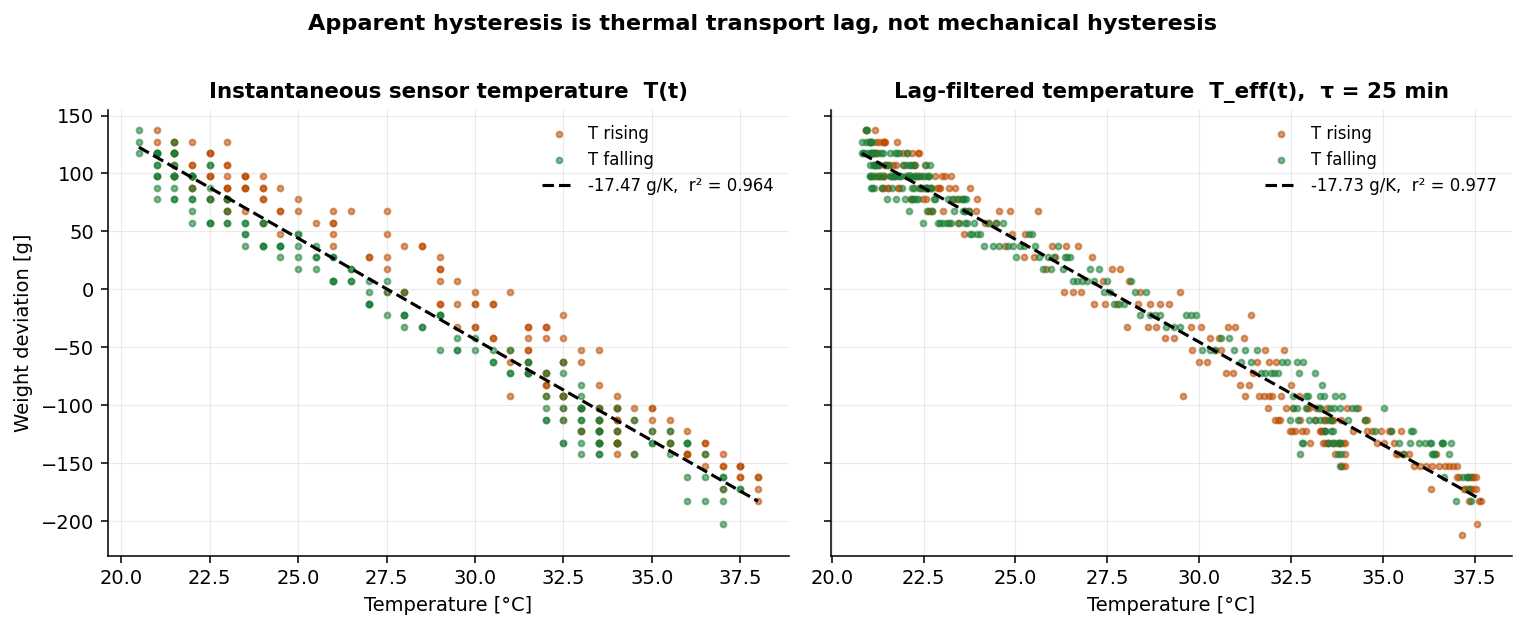
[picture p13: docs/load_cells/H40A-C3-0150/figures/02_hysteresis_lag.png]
Hysteresis


The 25 min constant was found by sweeping τ and minimising the residual. The minimum is broad and shallow — anything from 15 to 40 min performs within 1 g, so the value does not need to be tuned per unit.

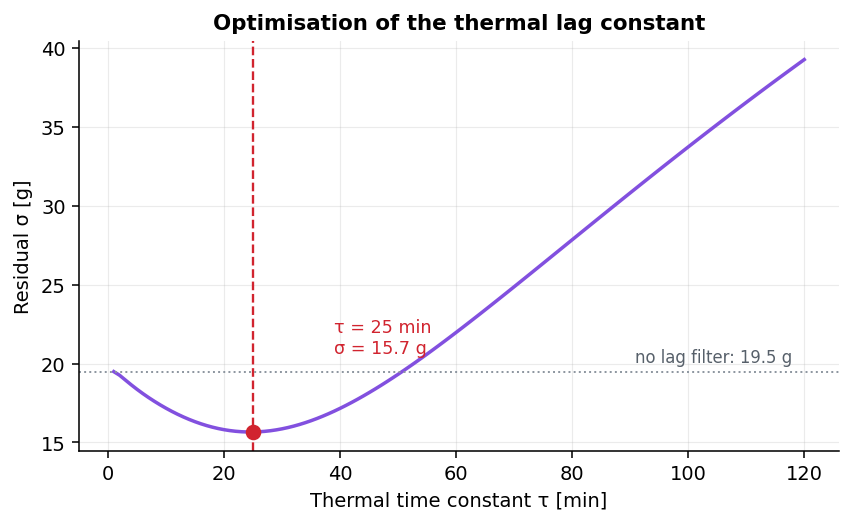
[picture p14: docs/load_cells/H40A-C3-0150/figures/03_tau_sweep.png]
Tau sweep


---

## 3. Hold-out validation

The coefficient was fitted on the first 20 h only and applied blind to the remaining 20.7 h.

- `k` fitted on training window: **−17.777 g/K** vs. −17.734 g/K on the full set → the coefficient is stable, not overfitted.
- Hold-out scatter: **σ = 11.9 g**
- Hold-out bias: **−21.5 g**, growing linearly

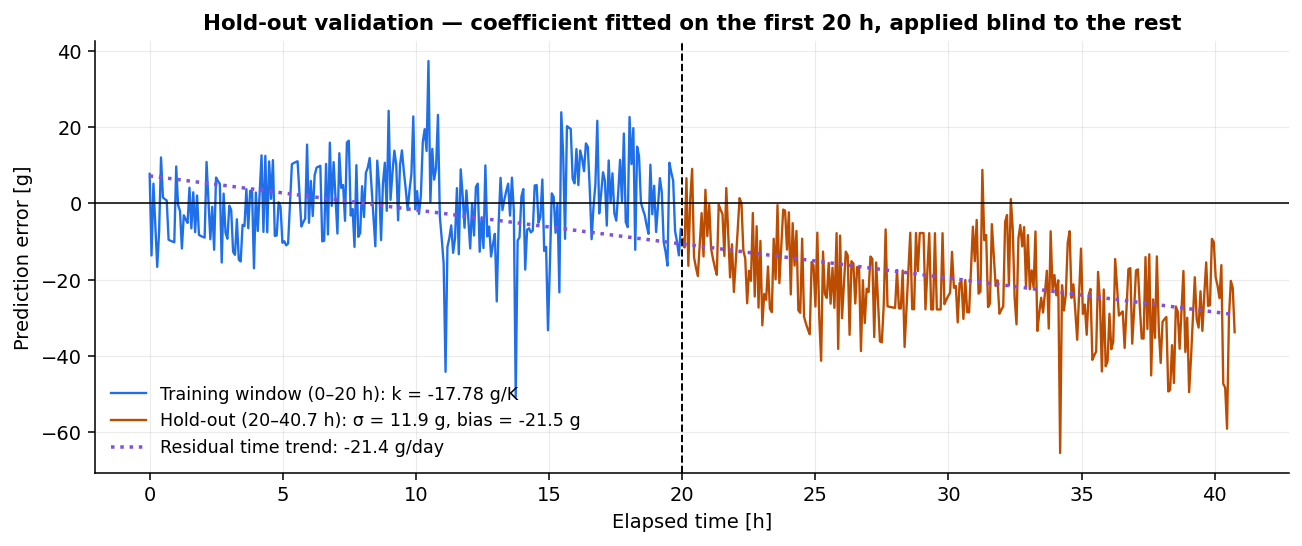
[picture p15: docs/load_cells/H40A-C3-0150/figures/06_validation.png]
Validation


The residual bias is a **−22.6 g/day linear trend** that survives temperature compensation. This is the single most important open item in this report — see §5.

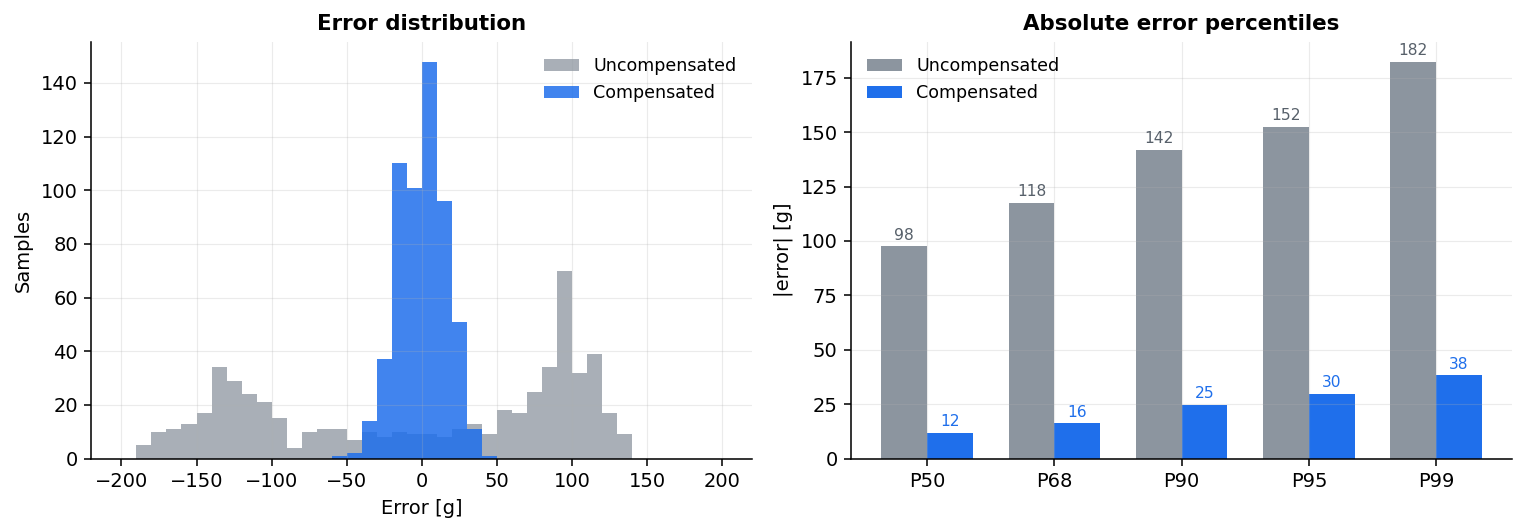
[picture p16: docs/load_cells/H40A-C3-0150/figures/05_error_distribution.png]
Error distribution


---

## 4. The drift does not come from the load cell

This is the finding that matters for the hardware design, and it contradicts the intuitive reading.

**Check against the OIML R60 class C3 envelope.** For E<sub>max</sub> = 150 kg at n<sub>LC</sub> = 4000 (Y = 10 000), v<sub>min</sub> = 15 g. The R60 limit for temperature effect on minimum dead-load output is 0.7 · v<sub>min</sub> per 5 K ≈ **2.1 g/K**. The measured 17.7 g/K is **8.4× outside** that envelope. A cell shipping with a C3 test certificate does not miss its own spec by 8×.

**Check against span drift.** At 22 kg the load is 14.7 % of full scale. A typical C3 sensitivity TC of 0.010 %/10 K of applied load would produce **0.22 g/K** — two orders of magnitude short of what was measured.

**Check the ADC.** Referred to the bridge input at C<sub>n</sub> = 2.0 mV/V and 5 V excitation, the cell delivers 66.7 nV/g. 17.73 g/K therefore corresponds to **≈ 1.18 µV/K at the ADC input**. HX711 and NAU7802 both specify offset drift on the order of 5–10 nV/K. The measured drift is **~200× the converter's own offset TC**, and a ratiometric bridge configuration cancels reference drift entirely.

**Conclusion:** neither the spring element, nor the bridge compensation, nor the converter can account for 17.7 g/K. The drift originates **outside the sensing chain**. In order of likelihood:

1. **Mechanical parasitic load path.** Differential thermal expansion between the aluminium spring element (α ≈ 23 µm/m·K) and a steel frame or hive stand injects a side load into the cell. This is by far the most common cause on hive scales and scales exactly like what was measured.
2. **Real mass change correlated with temperature** — evaporation, or forager traffic if the load is a live colony rather than a dead reference weight.
3. Moisture ingress into the potting, or thermal EMF at cable junctions and terminal blocks.

---

## 5. Open items — read before trusting these numbers

**This report characterises a system, not a load cell.** Do not quote −17.73 g/K as an H40A property. It is the temperature response of *this* cell in *this* mount with *this* frame, and it will change if you change the mounting.

| # | Issue | Impact | Action |
|---|---|---|---|
| 1 | Is the 22 kg load a dead reference weight or a live hive? | Determines whether the −22.6 g/day trend is sensor drift or real mass loss. Not resolvable from this dataset. | Repeat with a certified dead weight. |
| 2 | Only 40.7 h, one temperature cycle (20.5–38.0 °C) | Model is unvalidated below 20 °C. A hive scale sees −10 °C. | Extend to a full seasonal range or use a climate chamber. |
| 3 | Weight resolution is 10 g (1 LSB) | Residual σ of 15.7 g is only 1.6 LSB. Cannot resolve model error below the noise floor. | Log raw 24-bit ADC counts, not rounded kilograms. |
| 4 | Temperature resolution 0.5 K, sensor not on the cell body | The 25 min lag is direct evidence of poor thermal coupling. Costs ~2 g of residual. | Bond an NTC or DS18B20 to the aluminium body of the cell. |
| 5 | Single load point (22 kg only) | Cannot separate zero drift (load-independent) from span drift (load-proportional). The correction may not hold at 60 kg. | Repeat at 0 kg, 20 kg, 50 kg, 100 kg. |
| 6 | Single unit, n = 1 | No unit-to-unit spread. The firmware ships this `k` as the **default**, fitted on one cell in one mount. | Characterise at least 3 cells before treating it as a constant. Per-unit override: `CONFIG_TANENBASE_TEMPCOMP_GAIN_MG_PER_K`, or `0` to disable. |

---

## 6. Correction equation

### Deployed form

```
T_eff[n] = T_eff[n−1] + α · (T[n] − T_eff[n−1])
α        = 1 − exp(−Δt / τ),      τ = 25 min

W_corr[n] = W_raw[n] + k_c · (T_eff[n] − T_ref)

k_c   = +0.017734 kg/K   (= −k, the compensation gain)
T_ref = tare temperature [°C]
```

Initialise `T_eff[0] = T[0]` so the filter does not ramp from zero on cold boot.

### Do NOT put the time-drift term in firmware

The fit is materially better with a −22.6 g/day term (σ drops 15.7 → 11.3 g). **Leave it out.** On a hive scale, day-over-day mass change *is the measurement*. Subtracting a fitted daily slope would erase a real nectar flow of exactly that magnitude. Track the trend as a diagnostic; never as a correction.

### Firmware

Shipped implementation: [`src/features/measurement/tempcomp.c`](../../../src/features/measurement/tempcomp.c), enabled by `CONFIG_TANENBASE_TEMPCOMP` and applied in `measure.c` between the scale-factor conversion and the 999 kg clamp. Integer-only, no floating point, no dynamic allocation.

The two constants are **not** compiled in: they come from the load-cell profile the user picks on the setup page, and the numbers below are what profile `1` (`LC_PROFILE_H40A`) carries. One image therefore serves a generic cell, this one, and a re-characterised frame — see [`../README.md`](../README.md).

Three things the node has to get right that a desk implementation does not:

- **`T_eff` has to outlive the sleep.** RAM is wiped on every System OFF, so the filter state is persisted in ZMS and reloaded on each wake. Without that it would re-seed every cycle and the 25 min lag term would never do anything.
- **Δt is per call.** The first sample of a wake assumes the node slept for the configured measurement interval — there is no wall clock across System OFF — while later samples in the same wake (the 2 s BLE live view) use measured uptime. A wake that is *not* the measurement timer (button, reset, brownout) has an unknown gap, so the filter drops the stored `T_eff` and re-seeds instead of applying a correction from a stale one.
- **`T_ref` is the tare temperature — specifically `T_eff` at the tare.** The zero offset and `T_ref` are two halves of one zero and are captured in the same command; anchoring `T_ref` to the instantaneous probe reading instead would bake the probe-to-body lag straight into the zero. Until the first tare, `CONFIG_TANENBASE_TEMPCOMP_T_REF_MDEG` (25 °C) stands in — on a cell tared at 30 °C that stale default is a standing **+89 g**, which is what a "tare doesn't zero" symptom looks like.

| Kconfig | Default | |
|---|---|---|
| `CONFIG_TANENBASE_TEMPCOMP` | `y` | compile the correction in |
| `CONFIG_TANENBASE_LC_DEFAULT_PROFILE` | `1` | profile a unit runs until the setup page stores one — `1` is this cell |
| `CONFIG_TANENBASE_TEMPCOMP_GAIN_MG_PER_K` | `17734` | k<sub>c</sub> of the **custom** profile, per cell **and mount** — `0` keeps the filter running but applies no correction |
| `CONFIG_TANENBASE_TEMPCOMP_TAU_S` | `1500` | τ of the custom profile, 25 min |
| `CONFIG_TANENBASE_TEMPCOMP_T_REF_MDEG` | `25000` | fallback T<sub>ref</sub> before the first tare (all profiles) |

If the temperature probe fails, the weight is reported **uncorrected** rather than corrected against a stale `T_eff` — and the uplink still carries the temp-invalid sentinel, so the two are distinguishable downstream.

[`firmware/`](firmware/) keeps the same arithmetic standalone so the dataset can be replayed on a host. It lands on the same numbers as the Python model:

```console
$ gcc -O2 -std=c99 -o host_test firmware/host_test.c firmware/tanen_tempcomp.c -lm
$ ./host_test data/Loadcell_B.csv
n=572
raw : mean=22.0124 kg sigma=102.2 g p2p=350 g
comp: mean=22.0554 kg sigma=15.7 g p2p=103 g
```

---

## 7. Recommended hardware changes

1. **Fix the mount before tuning the software.** Software compensation of a mechanical fault is a workaround with a limited validity window. Mount the cell on a kinematic or slotted mount so the frame cannot transfer thermal expansion into it. Steel bolts through an aluminium body are a classic offender.
2. **Bond the temperature sensor to the cell.** A DS18B20 in thermal paste against the aluminium body eliminates the 25 min lag and the residual it costs.
3. **Log raw ADC counts.** Rounding to 10 g throws away roughly 4 bits before the compensation ever runs.
4. **150 kg is oversized.** A Dadant or Langstroth hive rarely exceeds 90 kg gross. A 100 kg cell would give a 1.5× better signal-to-noise at the same absolute drift.

---

## 8. Files

```
docs/load_cells/H40A-C3-0150/
├── README.md
├── data/
│   ├── Loadcell_B.csv                  bench run, raw (time;T_C;W_raw_kg)
│   ├── Loadcell_B_compensated.csv      bench run + T_eff + W_corr + residual
│   └── Loadcell_B_test2.csv            field validation, as reported by the node
├── analysis/
│   ├── tempcomp_analysis.py            bench pipeline, regenerates figures 1-6
│   ├── field_validation.py             field pipeline, stdlib only
│   └── make_field_figure.py            renders figure 7 as SVG
├── firmware/
│   ├── tanen_tempcomp.c                standalone copy of the shipped maths
│   ├── tanen_tempcomp.h
│   └── host_test.c                     replays the CSV through the firmware
└── figures/
    ├── 01_raw_overview.png
    ├── 02_hysteresis_lag.png
    ├── 03_tau_sweep.png
    ├── 04_before_after.png
    ├── 05_error_distribution.png
    ├── 06_validation.png
    └── 07_field_validation.svg
```

---

## 9. Field validation — PASSED

**Run:** 2026-08-16 → 08-21, 144 h, 1649 samples at 5.2 min. 22.2 kg dead weight (a concrete block) on the assembled platform, outdoors, correction active. Raw data: [`data/Loadcell_B_test2.csv`](data/Loadcell_B_test2.csv).

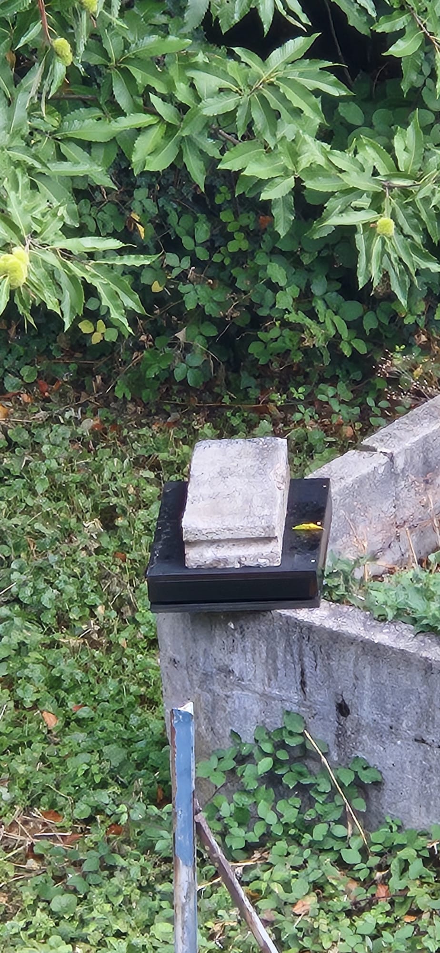
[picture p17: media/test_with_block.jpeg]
Test setup


*The setup. A dead weight rather than a colony is what makes the run decisive — with a live hive, real mass change and thermal drift are not separable (§5 item 1). The porous block and the wooden platform are also why days 4–6 gained half a kilo of rain.*

Because every measurement was transmitted, `T_eff` is reproducible offline and the **uncompensated series can be recovered by inverting the correction** — so both curves below come from the same physical samples, not from two different runs.

Field validation

### Result — dry window, 08-16 00:01 → 08-18 16:54 (64.9 h, 19.5–34.0 °C)

| Metric | Uncompensated (reconstructed) | Compensated | |
|---|---:|---:|---|
| Weight vs T<sub>eff</sub> slope | −16.64 g/K | **+1.10 g/K** | pass, criterion was ±3 |
| σ | 63.1 g | **11.6 g** | 5.5× |
| Peak-to-peak | 270 g | **100 g** | 2.7× |
| r² vs T<sub>eff</sub> | 0.971 | **0.126** | temperature no longer explains the signal |

σ = 11.6 g beats the 15.7 g predicted on the bench, and 1 sample in 746 was an outlier (−45 g), so the cluster filter in `weight.c` is doing its job.

### The steps after 08-18 are rain, not drift

Four events, each a rapid sustained gain that no thermal mechanism can produce. The last column is the coefficient the correction would need for the jump to be thermal, against the −17.7 g/K model:

| Event | ΔW | ΔT<sub>eff</sub> | implied |
|---|---:|---:|---:|
| 08-18 16:12 → 20:03 | +160 g | −5.21 K | −30.7 g/K |
| 08-20 04:54 → 10:50 | +310 g | −2.96 K | −104.8 g/K |
| 08-21 09:33 → 11:39 | +220 g | −0.38 K | **−582 g/K** |
| 08-21 15:46 → 19:15 | +100 g | −1.21 K | −83.0 g/K |

The third one settles it: 220 g arriving in two hours while the filtered temperature moved 0.4 K. That is mass, not drift — rain into a porous concrete block on a wooden platform. Peak +581 g over the dry baseline, +506 g still retained at the end of the series.

**The correction keeps working underneath the water.** Fitting `weight ~ drying_trend + T_eff` across the two rain-free dry-downs separates the two effects:

| Window | Drying | Thermal, compensated | Thermal, raw |
|---|---:|---:|---:|
| 08-19 00:04 → 08-20 04:28 (19.0–33.5 °C) | −4.7 g/h | **−1.48 g/K** | −19.21 g/K |
| 08-20 13:02 → 08-21 09:28 (15.5–21.0 °C) | −7.8 g/h | **+0.56 g/K** | −17.18 g/K |

So the compensation holds across the whole run, including down to **15.5 °C** — below the 20 °C floor §5 item 2 flagged as unvalidated.

### Do not re-fit the gain on this

This run measures k = −16.64 g/K where the bench fit gave −17.73, i.e. the shipped gain over-corrects by 6.6%. **Leave it.** The two dry-down windows disagree in *sign* about the residual (−1.48 and +0.56 g/K), so the true value sits inside roughly ±1.5 g/K of what is shipped and re-fitting on one more unit would be chasing noise. Everything is comfortably inside the ±3 g/K bar either way.

### Still open

- **Below 13 °C is untested.** The run bottomed out at 13 °C, and only the 15.5 °C dry-down was clean. A hive scale sees −10 °C; §5 item 2 stands until a winter window.
- **Water mass is real mass.** Nothing in firmware can or should remove it — a wet hive genuinely is heavier. But +500 g of rain looks exactly like a nectar flow to a delta-threshold alarm, which is worth knowing before tuning `anomaly_weight_threshold`.

### Method — the test cannot be run naively

The uplink carries the *corrected* weight only. `T_eff` is driven by every measurement (5 min), while uplinks fire on delta or the 4 h heartbeat — so the temperature history needed to reconstruct the correction offline never leaves the node, and raw weight is unrecoverable from the received series.

**Configure around it:** for the test window set `ms_interval == tx_interval` (the run above used 5.2 min, over BLE or downlink FPort 10/11). Every measurement is then transmitted, the filter can be re-run offline over the uplinked temperature series, and `W_raw = W_corr − k_c · (T_eff − T_ref)` recovers the raw reading. No firmware change, and it reverts to normal cadence afterwards.

Two things that break the reconstruction, so avoid both during the window: re-taring (moves `T_ref`), and any non-timer wake (button/reset re-seeds the filter — a gap in the series).

### Method — run parameters

| | |
|---|---|
| Load | **Dead reference weight**, not a colony — §5 item 1. On a live hive, real mass change and thermal drift are not separable, and the test proves nothing either way. |
| Duration | ≥ 3 full day/night cycles. The fit itself came from 1.7; the validation run got 2.7 dry plus 3.3 wet. |
| Cadence | `ms_interval = tx_interval`, ≤ 15 min |
| Record | Uplinked weight + temperature, plus ambient if available |

### Pass criteria, and what the run returned

| # | Criterion | Result | |
|---|---|---|---|
| 1 | Compensated slope inside ±3 g/K (raw ≈ −17.7) | +1.10 g/K | ✅ |
| 2 | σ materially below raw on the same data; >3× is good outdoors | 5.5× (63.1 → 11.6 g) | ✅ |
| 3 | No sign flip or growth at the cold end | holds to 15.5 °C; below 13 °C untested | ⚠️ partial |

A fail would have been informative, not fatal: `CONFIG_TANENBASE_TEMPCOMP_GAIN_MG_PER_K` takes a re-fitted value, or `0` to ship the correction inert.

**Reproduce:** `python analysis/field_validation.py data/Loadcell_B_test2.csv`

---

## Licence

Data and analysis released under CC BY 4.0. Code under MIT, consistent with the rest of TANEN.

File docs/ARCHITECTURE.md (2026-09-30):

# TanenBase Architecture

Smart beehive monitoring system on XIAO nRF54LM20A (Standard, non-Sense) + Wio-SX1262, built with nRF Connect SDK v3.4.0 (Zephyr RTOS). Board def is out-of-tree in `third_party/seeed-xiao-nrf54lm20a` (passed via `-DBOARD_ROOT`).

---

## Hardware Platform

| Component | Part | Interface |
|---|---|---|
| MCU | Seeed Studio XIAO nRF54LM20A (Standard, non-Sense) | — |
| Radio | Wio-SX1262 | SPI (spi23) |
| Load Cell ADC | NAU7802 | software I2C (GPIO bit-bang) |
| Temperature | DS18B20 | 1-Wire |
| Battery / PMIC | Nordic nPM1300 (on-board) | software I2C |

---

## Pin Map

XIAO header roles are kept 1:1 with the original nRF54L15 build, so the same
carrier PCB fits both modules — only the underlying GPIO numbers differ. See
[`Tanen_Base_pcb/README.md`](../Tanen_Base_pcb/README.md).

| XIAO Pin | nRF54LM20A GPIO | Function |
|---|---|---|
| D0 | P1.00 | DS18B20 data (1-Wire). **Wio-SX1262 rework required:** its K1 button + 10K pull-up ship on D0 and stop 1-Wire working entirely — trace must be cut, see Tanen_Base_pcb/README.md |
| D1 | P1.31 | SX1262 DIO1 |
| D2 | P1.30 | SX1262 RST **+ external TanenButton** (bare switch to GND). Armed as a System OFF wake source in `power.c`; the internal pull-up holds NRESET high while asleep, so the radio keeps sleeping |
| D3 | P1.29 | SX1262 BUSY |
| D4 | P1.03 | SX1262 NSS (SPI CS) |
| D5 | P1.07 | **LORA_RF_SW1** — Wio-SX1262 antenna-switch control. NOT a spare GPIO: driven RF control line, do not repurpose (a pull-up here parks the switch and bills the System OFF budget) |
| D6/TX | P1.08 | SW I2C SCL (NAU7802) |
| D7/RX | P1.09 | SW I2C SDA (NAU7802) |
| D8/SCK | P1.04 | SPI SCK (spi23) |
| D9/MISO | P1.05 | SPI MISO (spi23) |
| D10/MOSI | P1.06 | SPI MOSI (spi23) |
| D19 | P0.00 | *(free)* — held the external TanenButton until 2026-09-07, when it moved to D2. Bottom pad, never routed on carrier v0.1 |
| — | P0.09 | On-board TanenButton (wake from System OFF) |
| — | P1.22–P1.24 | RGB LEDs (active HIGH) |
| — | P1.17 / P1.18 | nPM1300 PMIC I2C — SCL / SDA |
| — | P2.00–P2.05 | on-board py25q64 NOR (spi00) — **never drive** |

**Board-DTS correction:** the vendored board `.dtsi` declares `pmic_i2c` on
P1.15/P1.16. The real wiring is SDA P1.18 / SCL P1.17 (matching Seeed's own
`zephyr-battery` example); the app overlay re-points it. `power_en` (P1.12) is
not connected on this module and is disabled in the overlay.

---

## Layer Diagram

```
┌─────────────────────────────────────────────────────────┐
│                        main.c                           │
│                (entry point, delegates to FSM)          │
└───────────────────────┬─────────────────────────────────┘
                        │
┌───────────────────────▼─────────────────────────────────┐
│                    core/fsm.c                           │
│         (4-state FSM, drives all transitions)           │
│                                                         │
│   ┌──────────┐  ┌──────────────┐  ┌─────────────────┐  │
│   │ power.c  │  │  config.c    │  │   (fsm state)   │  │
│   │ (sleep,  │  │  (NVS load/  │  │  SETUP →        │  │
│   │  wakeup) │  │   save)      │  │  MEASUREMENT →  │  │
│   └──────────┘  └──────────────┘  │  TRANSMISSION → │  │
│                                   │  ACTIVE_SLEEP   │  │
│                                   └─────────────────┘  │
└───────────────────────┬─────────────────────────────────┘
                        │
┌───────────────────────▼─────────────────────────────────┐
│                      features/                          │
│  ┌─────────────┐  ┌─────────────┐  ┌─────────────────┐ │
│  │ measurement │  │transmission │  │   ble_config    │ │
│  │ measure.c/h │  │transmit.c/h │  │  ble_svc.c/h   │ │
│  └──────┬──────┘  └──────┬──────┘  └────────┬────────┘ │
│         │                │                   │          │
│  ┌──────▼──────────────────────────────────────────┐   │
│  │                  anomaly/anomaly.c/h             │   │
│  │            (weight delta threshold checks)       │   │
│  └──────────────────────────────────────────────────┘   │
└───────────────────────┬─────────────────────────────────┘
                        │
┌───────────────────────▼─────────────────────────────────┐
│                      drivers/                           │
│  ┌──────────┐  ┌──────────┐  ┌──────────┐  ┌────────┐  │
│  │ weight.c │  │  temp.c  │  │  lora.c  │  │battery │  │
│  │ NAU7802  │  │ DS18B20  │  │ SX1262/  │  │  ADC   │  │
│  │ wrapper  │  │ wrapper  │  │ LoRaWAN  │  │        │  │
│  └────┬─────┘  └────┬─────┘  └────┬─────┘  └───┬────┘  │
└───────┼─────────────┼─────────────┼─────────────┼───────┘
        │             │             │             │
┌───────▼─────────────▼─────────────▼─────────────▼───────┐
│                       Hardware                          │
│     NAU7802 (I2C)   DS18B20 (1-Wire)   SX1262 (SPI)     │
│                    nPM1300 PMIC (I2C)                   │
└─────────────────────────────────────────────────────────┘
```

---

## Project Structure

```
TanenBase/
├── src/
│   ├── main.c                  # Entry point — arms watchdog, delegates to FSM
│   ├── core/
│   │   ├── fsm.c/h             # 4-state FSM engine
│   │   ├── power.c/h           # System OFF, GRTC wake, peripheral shutdown
│   │   └── watchdog.c/h        # task_wdt (60s) + WDT31 hw fallback
│   ├── config/
│   │   └── config.c/h          # ZMS load/save, defaults — sole ZMS owner
│   ├── drivers/
│   │   ├── weight.c/h          # NAU7802 over software I2C
│   │   ├── temp.c/h            # DS18B20 (sensor API, 1-Wire)
│   │   ├── lora.c/h            # SX1262 / LoRaWAN wrapper
│   │   └── battery.c/h         # Battery voltage via nPM1300 VBAT ADC
│   └── features/
│       ├── measurement/measure.c/h   # Weight + temp + battery orchestration
│       ├── measurement/tempcomp.c/h  # Load-cell thermal drift correction
│       ├── transmission/transmit.c/h # Payload build (big-endian) + uplink
│       ├── ble_config/ble_svc.c/h    # BLE GATT service (Web Bluetooth config)
│       └── anomaly/anomaly.c/h       # Weight/temp delta anomaly detection
├── boards/                     # App devicetree overlay for the target board
├── third_party/                # Vendored Seeed XIAO nRF54LM20A board def
├── test_apps/measure_loop/     # Standalone sensor bring-up app
├── web/                        # Web Bluetooth config page + downlink encoder
├── ttndecoder/                 # TTN payload formatters (unified BEEP + beelogger)
├── Tanen_Base_pcb/             # KiCad carrier board (schematic, PCB, gerbers)
├── scripts/                    # Toolchain discovery helper
└── *.conf, Kconfig, CMakeLists.txt, pm_static.yml, sysbuild.conf
```

---

## FSM States

Single-pass design — `fsm_run()` checks wake reason, executes one pass, ends in System OFF.

```
  power_get_wake_reason()
         │
    ┌────▼────┐ Button/Reset
    │  SETUP  │──────────────────────────────┐
    │ BLE+sensors ON, blocks up to timeout   │
    └────┬────┘                              │
         │ Done / timeout                    │
         ▼                                   │
  ┌──────────────┐ Timer wake ───────────────┘
  │ MEASUREMENT  │
  │ measure_init + measure_run               │
  │ meas_count++ → ZMS                       │
  │ anomaly_check()                          │
  └──────┬───────┘                           │
         │                                   │
    should_tx?                               │
    ┌────┴────┐                              │
    │ YES     │ NO ──────────────────────┐   │
    ▼         │                          │   │
  ┌──────────────┐                       │   │
  │ TRANSMISSION │                       │   │
  │ lora_init (only when needed)         │   │
  │ transmit_run(data, ext, flags)       │   │
  │ update last_tx_weight/temp           │   │
  │ lora_session_save + lora_sleep       │   │
  └──────┬───────┘                       │   │
         │                               │   │
         └───────────────┬───────────────┘   │
                         ▼
                   ┌───────────┐
                   │   SLEEP   │
                   │ power_off(ms_interval)  │
                   │ System OFF + GRTC wake  │
                   └───────────┘
```

| State | BLE | LoRa | Sensors | Next |
|---|-----|---|---|---|
| SETUP | ON | OFF | ON (live) | MEASUREMENT |
| MEASUREMENT | OFF | OFF | ON | TRANSMISSION or SLEEP |
| TRANSMISSION | OFF | ON | OFF | SLEEP |
| SLEEP | OFF | OFF | OFF | MEASUREMENT (timer) or SETUP (button/reset) |

**Delta reporting:** measure every `ms_interval`, TX only on weight/temp delta exceeding threshold or heartbeat (`tx_interval / ms_interval` cycles). LoRa radio only powered on when TX needed — saves ~1mA on measure-only wakes. With Extended Mode on, a TX wake first runs one BLE scan for the SwitchBot sensors (`ext_scan_once()`: bt_enable → active scan → bt_disable, ≤`CONFIG_TANENBASE_EXT_SCAN_TIMEOUT_MS`, ends as soon as every enabled sensor has sent T/H + battery) and only then calls `lora_init()`, so the scan can't straddle a join/RX window. Measure-only wakes never start BT, and BLE readings don't feed the anomaly check.

---

## Key Design Decisions

### LoRaWAN
- Class A, OTAA, EU868, TTN
- Join ladder DR3→DR0 + SF12 backoff, ADR, confirmed probes, link-health ladder, MAC answers kept across System OFF — all scenarios in [LORAWAN.md](LORAWAN.md)
- Big-endian payload encoding
- Downlink handled in TRANSMISSION state — FPort selects config field, one field per downlink:
  - **10** tx_interval (uint32 BE sec) · **11** ms_interval (uint32 BE sec, ≥60)
  - **12** anomaly_weight_threshold (uint16 BE) · **13** anomaly_temp_threshold (uint16 BE)

### BLE
- Just-Works pairing only, max 1 connection
- Custom GATT service: 16 characteristics (creds, calibration, timing, thresholds, commands, live sensors, Extended Mode config + live BLE sensors, load-cell profile)
- UUID base: `544E4253-xxxx-4269-8000-544E42415345`
- Web Bluetooth API consumed by `web/index.html` — no mobile app required. `web/encoder.html` is a sibling page that builds FPort 10–13 downlinks offline (no Bluetooth, no node)
- Active only in SETUP state (button/reset wake)
- No RF-switch handling needed on LM20A — the module drives its own antenna path (the L15 build had to sequence `rfsw_pwr`/`rfsw_ctl` on P2.03/P2.05; on LM20A those pins belong to the on-board NOR flash)
- Live sensor notify: 2s interval, deferred to CCC subscribe (no reads until client subscribes)
- Extended Mode (`features/ext_sensors/`): **ExtConfig** `0x000E` (R/W, 26 B = `ext_config_t`, ZMS id 20 — version, master switch, 3 × {MAC MSB-first, role, enable}) and **ExtLive** `0x000F` (notify, 18 B = 3 × {status, temp_cc, hum, batt %, rssi}, same 2 s timer, cached values only — never a sensor read). The role limits (≤2 in-hive, ≤1 outside, unique non-zero MACs) are enforced in firmware too: a violating write gets ATT `0x13`. The 26-byte write needs an ATT MTU above 23 — `BT_SMP`'s default ACL RX size of 69 gives 65, and Web Bluetooth hosts negotiate up. During SETUP a continuous active scan (window = interval = 60 ms) runs next to the web-app link — **never give it a shorter window**: the SDC raises a window < interval scanner that misses full windows to 2nd scheduling priority, above the peripheral link (3rd); window == interval runs at 4th priority and is interleaved around the link (enforced by a `BUILD_ASSERT` in `ext_sensors.c`). The scan runs independent of the master switch, so a sensor shows values before it is switched on; the device scans for the **saved** MACs only
- Load-cell profile: **LcProfile** `0x0010` (R/W, 10 B = `lc_config_t`, ZMS id 21 — version, profile id, gain mg/K, τ s). Picks which cell the temperature correction runs with (generic, H40A-C3-0150, SBS-PF-150, Zemic L6E, TAL220, Flintec PC/SB, or own measured values), so one image serves every frame. Only the H40A is characterised; the other named cells carry gain 0 and behave like generic until measured, but the unit records which one is fitted and a later firmware fills the constants in — non-custom profiles are resolved from the table on every read, not from the stored copy. A **read returns the effective constants**, resolved from the profile table, which is why the web page needs no copy of it; a write honours gain/τ only for `LC_PROFILE_CUSTOM` and is range-checked (ATT `0x13` otherwise). The write calls `tempcomp_reload()` so the 2 s live view already shows the new correction. The tare survives a profile change — the correction is zero at `T_ref` for any gain. Profile ids are the wire contract: append, never reorder (`docs/load_cells/README.md`)
- LoRa test runs on dedicated thread (lorawan_send deadlocks system work queue)
- Shutdown: stop adv → disconnect → 500ms wait → 100ms settle → bt_disable → RF switch off
- `ble_config_run()` blocks caller until CMD_DONE or timeout

### Power Management
- **Sleep target:** ≤20µA — achieved **~4µA** via System OFF + GRTC wake
- **Active target:** <15mC per measurement cycle — achieved 12mC
- SX1262 put into warm-start sleep before System OFF; CS (P1.03) and RST (P1.30) held HIGH (a floating CS glitches the radio back into ~1.5mA standby)
- On-board py25q64 NOR driven into **deep power-down** before sleep — skipping this alone costs ~14µA
- nPM1300 auto-ADC (`IBAT_EN` + `TASK_AUTO`) cleared before sleep — the PMIC sits on VBAT and keeps converting straight through the SoC's System OFF
- Battery voltage read on demand from the nPM1300's factory-trimmed VBAT ADC — no divider, no external enable GPIO
- All peripherals shut down before `sys_poweroff()`

- Battery pack: **3× BEVIGOR AAA 1.5 V Li/FeS₂ in series**, 1200 mAh, 4.5 V nominal, 5.2 V measured fresh (21 °C) — primary, non-rechargeable. ~4.6 y at 15 min / 2 h (~3.3 y with Extended Mode BLE sensors — the scan raises a TX wake from 63 to 139 mC). At µA drain the chemistry holds ~1.79 V/cell, so the pack runs **above the nPM1300's 4.45 V recommended VBAT maximum for essentially its whole life** and a worst-case fresh pack reaches 5.49 V against the 5.5 V absolute maximum: accepted deviation, [POWER_BUDGET.md](POWER_BUDGET.md) §5.2

See [POWER_BUDGET.md](POWER_BUDGET.md) for the full PPK2 baseline, daily-charge
formula, and battery ETA tables.

**Active power optimizations:**
- Boot delay (5s) skipped on timer/button wakes — only on hard reset (flash safety)
- Wake reason cached in `power.c` (hwinfo latch consumed on first read)
- NAU7802 PUR polling (vs blind 600ms sleep) — ~300ms faster power-up
- NAU7802 CR bit polling (PU_CTRL bit 5) — reads ADC only when conversion ready, no blind sleeps
- DS18B20 at 9-bit resolution (94ms vs 750ms at 12-bit; the 5°C anomaly threshold leaves plenty of margin)
- LoRaWAN DR3/SF9 (vs default DR0/SF12) — ~8x shorter TX airtime
- 5 discard samples after NAU7802 power-up for gain-128 PGA chopper settling

**Power budget (PPK2 measured @ 3.6V, production build, 2026-07-25):**

| Phase | Duration | Charge | Avg Current | Peak |
|---|---|---|---|---|
| Sleep (System OFF) | continuous | 0.27 mC/min | 4.5 µA | — |
| Measurement | 1.5 s | 12 mC | 8.0 mA | 57.6 mA |
| TX (SF9, unconfirmed) | 6.8 s | 63 mC | 9.3 mA | 91.7 mA |
| TX + Extended Mode (BLE scan + uplink, 2026-09-13) | 11.1 s | 139 mC | 12.5 mA | 77.8 mA |

**Platform limitations (nRF54L series + Zephyr 4.4):**
- No PM idle — the SoC lacks `HAS_PM` and `cpu-power-states` DTS. `CONFIG_PM=y` is not even settable; do not re-add it
- CPU cannot gate HFCLK during `k_sleep()` windows — active current stays high for the whole measurement
- SX1262 TCXO warmup spike (~80mA/50ms) unavoidable on every cold boot from System OFF
- No DRDY pin — NAU7802 conversion synchronization via CR bit over SW I2C only

### Fault Tolerance & Watchdog

- **Watchdog:** `task_wdt` software channel, 60s timeout (TRD 13.1/AC-10), backed by hardware `wdt31` fallback (catches kernel/timer death itself). Armed first in `main()`, fed at every FSM state boundary. Long waits (SETUP's 180s BLE window, LoRa-test thread join, debug/fallback sleeps) are sliced ≤30s with feeds in between — an unsliced `k_sleep()` would trip the WDT.
- **Fatal errors:** `CONFIG_RESET_ON_FATAL_ERROR=y` routes HardFault/BusFault/oops through NCS's `nrf/lib/fatal_error` handler — logs then cold-reboots instead of parking the CPU. `CONFIG_HW_STACK_PROTECTION=y` traps stack overflow via Cortex-M33 PSPLIM before it corrupts a neighboring thread's stack. `power_get_wake_reason()` decodes and logs `RESET_WATCHDOG` / `RESET_CPU_LOCKUP` / `RESET_SOFTWARE` on boot for field diagnostics.
- **I2C bus recovery:** every NAU7802 transfer gets one `i2c_recover_bus()` (9 SCL clocks + STOP) + retry on error — recovers a bus wedged by a brownout/ESD glitch mid-transaction without a full reset. `weight.c` CR-bit polling uses `k_msleep(2)`, not `k_busy_wait`, so the CPU can idle during the ~100ms/sample conversion train.
- **TX retry (tx_pending):** a failed uplink (join failure, radio init error) sets `tx_pending` in ZMS so the *next* wake retries immediately instead of waiting a full `tx_interval` in silence. Cleared on successful TX.
- **DevNonce hard-fail:** `lora_init()` aborts the join if the DevNonce can't be persisted to ZMS — burning nonce 0 repeatedly gets every join replay-rejected by TTN, draining the battery in a retry storm. Join is skipped and retried via `tx_pending` next wake.
- **Downlink cross-validation:** both `tx_interval` and `ms_interval` downlinks (FPort 10/11) and the BLE `MsInterval`/`TxInterval` writes enforce `T_TX ≥ T_MEAS` (TRD 7.1) against the *other* live value, not just a static floor.
- **BLE concurrency:** `active_conn` is mutex-guarded (`conn_acquire()` ref-snapshot pattern) — previously racy across BT RX / sysWQ / main thread (use-after-free / double-unref risk on shutdown). `pending_cmd` uses an atomic CAS gate so a second BLE command can't silently overwrite one still in flight. Sensor I/O triggered over BLE (live readings, tare, calibrate) runs on a dedicated **preemptible** work queue (`sensor_wq`, `K_PRIO_PREEMPT(10)`), never the cooperative sysWQ: gpio-I2C bit-banging busy-spins (`i2c_bitbang.c` `i2c_delay()` is a spin loop), and with the NAU7802 absent every SCL edge spins out the 100 ms clock-stretch timeout — ~3.5 s per `measure_run()`, re-queued every 2 s. On the sysWQ that starved the BT RX thread and `main`: the web app dropped after ~5 s and the watchdog reset the node 60 s later, which then skipped SETUP on the reset wake (2026-09-13, bare board without load cell). A live read is skipped while the previous one is still pending and while `lora_test_running` (the test thread measures itself); the queue is drained before SETUP returns so it can't race the MEASUREMENT cycle. AppKey/DevEUI/JoinEUI GATT writes are **plain** read/write (TRD 12.1's "encrypted pairing required" was tried and reverted 2026-07-07 — Web Bluetooth has no `pair()` API and can't reliably complete an OS-triggered SMP pairing mid-write; it hung the link until supervision timeout (disconnect reason 8) and left `bt_le_adv_start` failing with `-ENOMEM` afterward). See OPEN_QUESTIONS.md item 10.
- **Sensor validity:** `measurement_data_t.valid` bitmask (`MEAS_VALID_WEIGHT/TEMP/BATTERY`) — a failed sensor is never sent as a real `0` (which would falsely trigger a confirmed weight-anomaly uplink). Invalid fields are sent as sentinels (weight `0xFFFFFF`, battery `0xFFFF`, temp `0x7FFF`) in the payload and excluded from anomaly delta checks and the last-tx baseline.

### ZMS Storage (RRAM)
- All config persisted via ZMS (Zephyr Memory Storage) on nRF54L RRAM
- `config.c` owns all ZMS access — write-through cache pattern
- No other module reads flash directly

| ZMS ID | Field | Type | Default |
|---|---|---|---|
| 3 | dev_eui | 8B | Kconfig |
| 4 | join_eui | 8B | Kconfig |
| 5 | app_key | 16B | Kconfig |
| 6 | zero_offset | int32 | 0 |
| 7 | scale_factor | int32 | 1000 |
| 8 | tx_interval | uint32 | 14400 (4h) |
| 9 | ms_interval | uint32 | 300 (5min) |
| 10 | weight_threshold | uint16 | 2000g |
| 11 | temp_threshold | uint16 | 500 (5.00°C) |
| 12 | last_tx_weight | uint16 | 0 |
| 13 | last_tx_temp | int16 | 0 |
| 14 | measurement_count | uint32 | 0 |
| 15 | ocal1 | int32 | — (NAU7802 offset cal) |
| 16 | link_state | struct | uplink_count=0, forced_dr=-1 |
| 17 | tx_pending | uint8 | 0 |
| 18 | tempcomp_state | struct | t_eff_mdeg=0, primed=0 |
| 19 | tare_temp | int32 | 25000 (m°C) |

### Calibration
- Zero offset: tare reading captured via BLE command in SETUP state
- Scale factor: known reference weight set via BLE, computed and stored
- Both applied in `measure.c`: `grams = (raw - zero_offset) * 1000 / scale_factor`

### Temperature compensation
- `tempcomp.c` — `W_corr = W_raw + k_c · (T_eff − T_ref)`, with `T_eff` a
  one-pole lag filter (τ = 25 min) on the DS18B20 reading. Fixed-point Q16,
  no float. Measured effect on the reference cell: σ 102.2 g → 15.7 g
- Applied in `measure.c` after the scale-factor conversion, before the 999 kg
  clamp. Skipped (weight reported raw) when the temp read fails
- `T_eff` is persisted in ZMS because System OFF wipes RAM — a filter that
  re-seeds every cycle has no memory to lag with. `fsm.c` saves it once per
  cycle, not per `measure_run()`, so the 2 s BLE live view can't hammer ZMS
- Δt: configured `ms_interval` for the first sample of a wake (no wall clock
  across System OFF), measured uptime for later ones. A non-timer wake means
  the gap is unknown → drop `T_eff` and re-seed
- `T_ref` = `T_eff` at the BLE tare (ZMS 19), written through `tempcomp_tare()`
  so the in-RAM copy updates too — the live view would otherwise keep applying
  the pre-tare reference for the rest of the setup window. Tare returns status
  `4` if the offset stored but `T_ref` did not
- `k_c` is a property of the cell **and its mount** — see
  [`docs/load_cells/H40A-C3-0150/`](load_cells/H40A-C3-0150/)

### Logging
- `LOG_*` macros exclusively (no `printk`)
- `CONFIG_LOG=n` in `prj_production.conf` — zero logging overhead in production
- `debug.conf` enables `CONFIG_LOG=y` + `CONFIG_LOG_DEFAULT_LEVEL=4`

---

## Interface Contracts

### Drivers

All driver functions follow this contract:

```c
/* Init: returns 0 on success, negative errno on failure */
int weight_init(void);
int temp_init(void);
int lora_init(void);
int battery_init(void);

/* Read: takes output pointer, returns 0 or negative errno */
int weight_read(struct sensor_value *val);
int temp_read(struct sensor_value *val);
int battery_read_mv(int32_t *mv);
```

### Features

- Features communicate via **events/callbacks** — never direct function calls between feature modules
- FSM passes a context struct to each feature; features report results via return codes
- `measure.c` calls drivers, packages results, returns to FSM
- `transmit.c` receives measurement data from FSM context, builds payload, returns TX result
- `anomaly.c` is called post-measurement with latest weight; fires callback if threshold exceeded

### FSM

```c
/* Single entry point from main.c */
void fsm_run(void);

/* State transition driven by return codes */
typedef enum {
    FSM_STATE_SETUP,
    FSM_STATE_MEASUREMENT,
    FSM_STATE_TRANSMISSION,
    FSM_STATE_ACTIVE_SLEEP,
} fsm_state_t;
```

---

## Kconfig Flags

Defined in [`Kconfig`](../Kconfig). Feature toggles:

| Flag | Default | Purpose |
|---|---|---|
| `CONFIG_TANENBASE_BLE_CONFIG` | `y` | BLE GATT configuration service (SETUP state) |
| `CONFIG_TANENBASE_ANOMALY` | `y` | Delta/anomaly detection module |
| `CONFIG_TANENBASE_EXT_SENSORS` | `y` | Extended Mode: SwitchBot BLE T/H sensors (selects `BT_OBSERVER`) |
| `CONFIG_TANENBASE_EXT_SCAN_TIMEOUT_MS` | 8000 | Upper bound of the BLE scan on a TX wake |

Runtime defaults (all also settable at runtime over BLE or LoRaWAN downlink,
and persisted in ZMS — Kconfig only seeds first boot):

| Flag | Default | Purpose |
|---|---|---|
| `CONFIG_TANENBASE_DEV_EUI` | `""` | Fixed DevEUI; empty = derive per-device from SoC hardware ID |
| `CONFIG_TANENBASE_JOIN_EUI` | all-zero | LoRaWAN JoinEUI |
| `CONFIG_TANENBASE_APP_KEY` | all-zero | LoRaWAN AppKey — **set in `prj_credentials.conf`, never commit** |
| `CONFIG_TANENBASE_DEFAULT_TX_INTERVAL` | 14400 (4h) | Heartbeat uplink interval |
| `CONFIG_TANENBASE_DEFAULT_MS_INTERVAL` | 300 (5min) | Measurement interval (min 60s) |
| `CONFIG_TANENBASE_DEFAULT_WEIGHT_THRESHOLD` | 2000 g | Weight anomaly threshold |
| `CONFIG_TANENBASE_DEFAULT_TEMP_THRESHOLD` | 500 (5.00°C) | Temperature anomaly threshold |
| `CONFIG_TANENBASE_TEMPCOMP` | `y` | Load-cell thermal drift correction |
| `CONFIG_TANENBASE_TEMPCOMP_GAIN_MG_PER_K` | 17734 | k_c — per cell **and mount**; 0 = no correction |
| `CONFIG_TANENBASE_TEMPCOMP_TAU_S` | 1500 (25min) | Thermal lag time constant |
| `CONFIG_TANENBASE_TEMPCOMP_T_REF_MDEG` | 25000 (25°C) | Fallback T_ref before the first tare |
| `CONFIG_TANENBASE_SETUP_TIMEOUT` | 180 s | SETUP-state / BLE advertising window |
| `CONFIG_TANENBASE_DEBUG_LOOP_INTERVAL` | 180 s | Cycle delay when System OFF is skipped (`ms_interval=0`) |

---

## LoRaWAN Payload Format

Big-endian encoding. All fields fixed-width for deterministic decoder on TTN.

| Byte(s) | Field | Type | Unit |
|---|---|---|---|
| 0–2 | Weight | uint24 | grams, 0-999000 (999 kg design ceiling) |
| 3–4 | Temperature | int16 | 0.01 °C, signed both ways |
| 5–6 | Battery | uint16 | mV |
| 7 | Flags | uint8 | anomaly bits |

Total: 8 bytes per uplink (widened from 7 bytes on 2026-07-07 — uint16 grams topped out at 65.535 kg). Failed-sensor sentinels: weight `0xFFFFFF`, battery `0xFFFF`, temp `0x7FFF` — TTN decoder must map these to null, not a literal value. The weight sentinel sits far above the 999 kg clamp so a maxed-out real reading can't be mistaken for a dead sensor.

### Extended Mode blocks

With Extended Mode on, one 5-byte block follows byte 7 for each enabled SwitchBot sensor **heard** in this wake's scan, in slot order — frames are 8, 13, 18 or 23 bytes (EU868 DR0 allows 51). The base 8 bytes are unchanged, so decoders that only read bytes 0–7 keep working.

| Byte | Field | Type | Unit |
|---|---|---|---|
| 0 | Descriptor | uint8 | bits 7–4 type (`1` = SwitchBot T/H) · bit 2 role (`1` = outside) · bits 1–0 slot |
| 1–2 | Temperature | int16 | 0.01 °C (sensor resolution 0.1 °C) |
| 3 | Humidity | uint8 | %RH |
| 4 | Battery | uint8 | %, `0xFF` = not received |

An enabled sensor that was not heard costs no airtime: its block is left out and flags **bit 3** (`ext_missing`) is set. The decoder derives the block count from the length alone (`(len − 8) / 5`); a length that is not 8 + 5n decodes the base frame and warns.

### Server-Side Decoding

`ttndecoder/tanen-decoder.js` is the formatter to install in TTN (Payload formatters → Uplink). It parses the frame once and emits both supported platforms' key sets into one `decoded_payload`, so a single formatter feeds both integrations:

| Reading | BEEP key | beelogger key | Unit |
|---|---|---|---|
| Weight | `weight_kg` | `Gewicht` | kg |
| Temperature | `t` | `TempOut` | °C |
| Battery | `bv` | `VBatt` | V |
| Outside temperature / humidity (BLE, role outside) | `t` / `h` | `TempOut` / `FeuchteOut` | °C / %RH |
| 1-Wire probe, when an outside BLE sensor is present | `t_0` | — | °C |
| Inside #1 temperature / humidity (lower slot) | `t_i` / `h_i` | `TempIn` / `FeuchteIn` | °C / %RH |
| Inside #2 temperature / humidity | `t_1` / — | `TempIn2` / `FeuchteIn2` | °C / %RH |

An outside BLE sensor takes over `t`/`TempOut`; without one, those stay the 1-Wire probe, exactly as before. BEEP has no second inside-humidity key, so inside #2's humidity reaches beelogger only.

Each server persists the keys it recognises and ignores the others; `flags`, `anomaly_weight`, `anomaly_temp`, `heartbeat`, `ext_missing`, `ext_count`, `t_1wire`, `h_i2` and the BLE battery levels `bat_out`/`bat_in1`/`bat_in2` (%) are diagnostics visible in TTN live data only. The BEEP keys keep the original decoder's quantisation (10 g / 10 mV), the beelogger keys carry full payload precision — same reading, different rounding, by design. The per-platform predecessors (`beepdecoder.js` = `custumdecoder.js`, `tanen-beelogger-decoder.js`) remain in the folder for reference and are no longer the ones to deploy.

Integration wiring differs per platform. BEEP needs `?key=<DevEUI>` on the webhook base URL (see the note below). beelogger's community server takes `https://community.beelogger.de/<username>/{/devID}/beelogger_log.php?Passwort=<password>&LORA=1` — `{/devID}` is substituted by TTN per uplink, so TTN device IDs are named `beelogger1`, `beelogger2`, … to match the registered stations, and because the password is shared across stations one webhook covers the whole application. Both paths are confirmed receiving from the same uplink.

**BEEP ingestion note (2026-07-07):** widening this payload initially appeared to break BEEP (`api.beep.nl/api/lora_sensors`) — decoded correctly in TTN console, but data never showed up in BEEP. That was a false lead. Root cause: BEEP's key-routing falls back to `payload_fields.hardware_serial` (a TTN **Stack V2** field) when no explicit `key` is given; this project's webhook uses TTN **V3**, which puts the device identifier at `end_device_ids.dev_eui` instead — so BEEP couldn't match the measurement to a registered device, regardless of payload width. Fixed by adding `?key=<DevEUI>` to the BEEP webhook URL in TTN Console (Integrations → Webhooks) — an external config change, not a firmware/decoder change. Reference: `ttndecoder/Beep-Sensor-data-API-v0.5.pdf`.

---

## Extension Points

### Adding a New Sensor
1. Add `drivers/<sensor>.c/h` implementing `<sensor>_init()` / `<sensor>_read()`
2. Add the source to `target_sources()` in `CMakeLists.txt`
3. Add acquisition call in `features/measurement/measure.c`, plus a `MEAS_VALID_<SENSOR>` bit
4. Extend payload format and the TTN decoder (`ttndecoder/tanen-decoder.js`) as needed — add the field under both platforms' key sets

### Adding a New Radio Protocol
1. Add `drivers/<proto>.c/h` wrapping the Zephyr radio API
2. Add `features/transmission/<proto>_transmit.c/h` for payload + uplink logic
3. Guard with a Kconfig flag; FSM selects transmission feature at compile time

### Adding a New Anomaly Algorithm
1. Implement in `features/anomaly/anomaly.c` behind a new internal function
2. Expose via the same `anomaly_check(weight_g)` interface already used by FSM
3. Select algorithm via Kconfig or runtime config setting

---

## Build Configurations

| File | Use |
|---|-----|
| `prj.conf` | Base — all features on, serial off, watchdog on |
| `debug.conf` | Overlay — LOG on (level 4), console on uart20 |
| `prj_production.conf` | Overlay — LOG off, size optimization |
| `prj_credentials.conf` | **Gitignored** — real LoRaWAN AppKey. Copy from `prj_credentials.conf.example` |
| `sysbuild.conf` | OTA — enables MCUboot via sysbuild (unverified on LM20A, see below) |
| `pm_static.yml` | Pins `zms_storage` @ 0x1D1000/36KB — required with sysbuild so MCUboot's partition layout doesn't relocate ZMS and wipe DevNonce/session/credentials |
| `boards/xiao_nrf54lm20a_nrf54lm20a_cpuapp.overlay` | Devicetree — SX1262, sw-I2C, 1-Wire, PMIC pin fix, sleep-current config |

Normal use is the wrapper scripts, which locate the SDK, set `BOARD_ROOT`, and
force `--pristine` on a mode change:

```powershell
.\build.ps1 debug           # console + logs on uart20 -> CMSIS-DAP VCOM @115200
.\build.ps1 prod            # LOG off, size-optimized
.\build.ps1 prod --pristine
.\build_test.ps1            # standalone sensor bring-up app (test_apps/measure_loop)
```

Equivalent raw `west` invocation (`$BR` = `-DBOARD_ROOT=<repo>/third_party/seeed-xiao-nrf54lm20a`):

```sh
west build -b xiao_nrf54lm20a/nrf54lm20a/cpuapp --no-sysbuild -- $BR \
    -DOVERLAY_CONFIG="prj_credentials.conf;prj_production.conf"
```

Do **not** add `-S cdc-acm-console`: it repoints `zephyr,console` at the nRF's
own USBHS CDC (VID 0x2fe3), which never enumerates on this board — the console
goes silent. The `--sysbuild`/MCUboot path is **unverified on LM20A**; on the
earlier L15 port it failed in MCUboot's `flash_map_extended.c`. Replace the dev
signing key (`SB_CONFIG_BOOT_SIGNATURE_KEY_FILE`) before any real OTA deployment.

Flash scripts:
```powershell
# Firmware update only (preserves ZMS config/calibration in RRAM)
.\flash_update.ps1

# Factory reset (CTRL-AP mass erase — wipes ZMS config/calibration AND the
# DevNonce counter; reset join nonces in the TTN console afterwards)
.\flash_rest.ps1
```

---

## Dependency Rules

- `main.c` depends on `core/fsm` only
- `core/fsm` depends on `core/power`, `core/config`, and all features
- Features depend on drivers only (no cross-feature imports), except `ble_config` which calls `measure_run()` for live sensor reads and `lora_*` for LoRa test
- Drivers depend on Zephyr APIs only (sensor API, SPI, I2C, ADC, GPIO)
- `anomaly` depends on no driver directly — receives pre-read values from FSM context
- No module outside `core/config` touches ZMS

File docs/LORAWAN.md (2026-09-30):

# LoRaWAN Behaviour

How a TanenBase node joins, sends, adapts its data rate, notices a lost link
and recovers, and why each rule exists. Everything here lives in
[`src/drivers/lora.c`](../src/drivers/lora.c) unless noted.

Class A, OTAA, EU868, The Things Network (TTN), LoRaMac-node via Zephyr's
`lorawan` API.

---

## 1. The constraint everything follows from

The node spends almost all its time in **System OFF**, which wipes RAM. Every
wake is a cold boot. Anything LoRaWAN needs to remember must be in flash (ZMS),
and anything that lives only in RAM is lost when the node sleeps.

What is persisted, and where:

| ZMS id | Record | Written | Purpose |
|---|---|---|---|
| 1 | DevNonce | before every join goes on air | replay protection; a reused nonce is rejected by TTN |
| 2 | Session (`LoRaMacNvmData_t`, 1120 B) | after every transmitting wake | keys, frame counters, DR, ADR state, channel table |
| 16 | Link state (`link_state_t`) | every uplink / join attempt | probe counter, no-ACK count, pinned DR, join failures, join backoff |
| 17 | TX pending | end of transmitting wake | retry a failed uplink on the next wake |
| 22 | Pending MAC answers | only when the MAC has answers queued | see §5 |

The radio is only started on wakes that transmit. Measure-only wakes never
touch it.

---

## 2. A normal transmitting wake

1. FSM decides to transmit (heartbeat, anomaly, or a pending retry) and calls
   `lora_init()`.
2. `lora_init()` starts the MAC once per boot, then **restores the session**
   from ZMS. No session → OTAA join (§3).
3. `apply_link_policy()` sets NbTrans = 1 and either ADR on (healthy) or ADR
   off with a pinned DR (degraded, §7).
4. Pending MAC answers from the previous wake are re-queued (§5).
5. `lora_send()` sends the frame on port 1: unconfirmed, or confirmed if it is
   a probe (§6) or a weight anomaly.
6. RX1/RX2 windows: any downlink is processed (MAC commands, config ports).
7. FSM calls `lora_session_save()`: session + pending MAC answers to ZMS.
8. System OFF.

`lora_init()` is idempotent within a boot. SETUP's BLE LoRa test and the
FSM's transmit can both run in one boot; the second call returns immediately
and reuses the live session. It must not restart the MAC or re-register the
downlink callback, because appending the callback node a second time makes the
callback list point to itself and the next downlink loops until the watchdog
resets the node.

---

## 3. Joining (OTAA)

Triggered when there is no stored session: first boot, after BLE
*Clear Session*, after a rejoin decision (§8), or after a firmware update that
changed the session size.

| Attempt | DR | SF | JoinRequest airtime |
|---|---|---|---|
| 1st | DR3 | SF9 | ~0.2 s |
| 2nd | DR2 | SF10 | ~0.4 s |
| 3rd | DR1 | SF11 | ~0.8 s |
| 4th and later | DR0 | SF12 | ~1.5 s |

- One attempt per wake. A failed join sets TX pending, so the next wake
  (every `ms_interval`, 5 min by default) tries again one DR lower.
- **SF12 join backoff.** Once attempts are at DR0 and still failing, the node
  waits **1 h, 2 h, 4 h, then every 8 h** between attempts instead of trying
  every wake. It counts wakes, not time (`join_wait` in the link state), and no
  DevNonce is used while waiting. Without the backoff, a node out of range
  would send an SF12 JoinRequest every 5 min: ~430 s/day of airtime against
  TTN's 30 s fair use.
- **DevNonce is written to flash before the JoinRequest goes on air.** If ZMS
  is unavailable the join is aborted: resending nonce 0 forever would get
  every join replay-rejected and drain the battery.
- On success: failure counters reset, the node starts **at the DR the join
  succeeded on**, with ADR on. A join that only got through at SF12 must not
  send its first data frame at SF9, which would be lost.
- The join-accept carries TTN's channel list (CFList): 867.1, 867.3, 867.5,
  867.7, 867.9 MHz, on top of the three default channels 868.1/.3/.5.

---

## 4. ADR: the network tunes the data rate

With ADR on, TTN watches the SNR of recent uplinks and sends a **LinkADRReq**
(DR, TX power, channel mask) piggybacked on a downlink. The node applies it
and answers with a **LinkADRAns** in the next uplink.

Typical first minutes of a node close to the gateway:

| Uplink | SF | Downlink |
|---|---|---|
| join wake | SF9 | LinkADRReq DR5, TX power 1 |
| next | SF7 | LinkADRReq DR5, TX power 2 (TTN lowering power step by step) |
| … | SF7 | a few more, then **no downlink at all** |

Once converged, uplinks go out without any downlink after them. A downlink after
every uplink means something is wrong (§12).

The node only accepts a LinkADRReq if **every** channel in its mask is known.
TTN asks for channels 0–7, so the channel table from the join-accept must
survive sleep. It is part of the session blob (see the build note in §11).

---

## 5. MAC answers across sleep

LoRaMac keeps queued MAC answers (LinkADRAns, DevStatusAns, RXParamSetupAns,
…) in a RAM-only list, **not** in its NVM context. They go out in the *next*
uplink, which is after System OFF, so without help every answer is lost. TTN
then never sees the answer and repeats the command after every uplink.

The firmware saves that list with the session (ZMS id 22) and re-queues it on
restore, so the next uplink carries it in FOpts:

```
Persisting pending MAC answers:  03 07        (end of wake N)
Re-queued 1 MAC answer(s) for this uplink     (wake N+1)
```

Only end-device answers with a known size are re-queued. Requests
(LinkCheckReq, DeviceTimeReq) are dropped, since their answers need MAC state
that does not survive the reset either. The record is cleared on a fresh join
and when a rejoin is scheduled.

---

## 6. Probes: noticing a dead link

Unconfirmed uplinks are fire-and-forget, so without a downlink the node
cannot tell whether anything arrived. Every **4th uplink** is therefore sent
**confirmed** (a *probe*); the network's ACK proves the link works in both
directions.

| | Healthy | Degraded |
|---|---|---|
| Probe cadence | every 4th uplink | every 4th uplink |
| Downlinks/day at 1 h heartbeat | ~6 | ~6 |

TTN's fair use allows 10 downlinks/day. A shared community gateway also cannot
serve a downlink on every wake; probing every cycle guaranteed missing ACKs and
kept nodes stuck.

A weight-anomaly frame is always confirmed and counts as a probe.

A probe without an ACK is **not** a transmit failure: the frame went on air,
only the downlink is missing. It returns success to the FSM (no retry) and only
feeds the link-health ladder.

---

## 7. Link-health ladder

```mermaid
stateDiagram-v2
    Healthy: Healthy - ADR on
    Degraded: Degraded - ADR off, DR pinned
    Floor: Floor - DR0 / SF12
    Rejoin: Rejoin - session cleared

    Healthy --> Degraded: probe no-ACK, DR - 1
    Degraded --> Degraded: probe no-ACK, DR - 1
    Degraded --> Floor: DR reaches 0
    Floor --> Floor: probe no-ACK
    Floor --> Rejoin: 8th consecutive no-ACK
    Degraded --> Healthy: probe ACK
    Floor --> Healthy: probe ACK
    Rejoin --> Healthy: OTAA join (section 3)
```

- **Step down:** each no-ACK probe lowers the DR by one (more range, longer
  airtime), starting from the DR the node is actually on. ADR is switched off
  so the pinned DR sticks (`forced_dr` in the link state).
- **Floor:** at DR0 the node stays put. A missing ACK means the *downlink*
  failed; on a marginal link the uplinks often still arrive, so the session is
  not thrown away early.
- **Rejoin:** after **8 consecutive no-ACK probes** (step-downs included) the
  session is cleared and the next transmitting wake joins again (§3).
- **Recover:** any ACKed probe clears the failure count, removes the pin and
  switches ADR back on **at the current DR**. TTN then raises the DR as far as
  the measured SNR allows. The node does not jump back up on its own, which
  would risk bouncing straight back into a dead DR.

Why ADR alone is not enough: LoRaMac's own ADR back-off (ADR_ACK_LIMIT 64 +
ADR_ACK_DELAY 32) needs 128 uplinks before the first step down. That is more
than 5 days at a 1 h heartbeat.

---

## 8. Scenarios

Timings assume a **1 h heartbeat** and no anomalies. At a 4 h heartbeat
multiply by 4.

### 8.1 Installed near a gateway
Join at SF9 → ADR moves it to SF7 within the first one or two uplinks and
lowers TX power. From then on: one 62 ms uplink per hour, a confirmed probe
every 4 h, no other downlinks.

### 8.2 Far from the gateway, but reachable
The join may only succeed at SF10–SF12 (§3). The node starts at that DR with
ADR on; TTN moves it only as far up as the SNR allows. Nothing else happens.

### 8.3 Node moved away (or an obstacle appears)
| Time | Event |
|---|---|
| 0 | Uplinks at the old SF stop arriving; data is lost from here |
| ≤ 4 h | Next probe gets no ACK → degraded, one SF higher |
| +4 h each | Next probe: ACK → recovered at this SF; no ACK → one more step |
| ≤ 20 h | At SF12 in the worst case (from SF7) |

As soon as the node is on a DR that reaches the gateway, its normal uplinks
arrive again. The next probe confirms it and turns ADR back on. Data loss is
limited to the hours spent at DRs that do not reach.

### 8.4 Uplinks arrive, ACKs don't
Shared or busy gateway, or a strongly asymmetric link. The ladder walks down to
SF12 and stays there. Uplinks keep arriving the whole time. Only after 8
missed ACKs in a row (~32 h) is a rejoin scheduled. Any ACK in between
restores normal operation.

### 8.5 Out of range entirely
Ladder to SF12 (≤ 20 h), then missed probes at the floor until 8 in a row →
rejoin (≤ 32 h after the move). Joins then step DR3 → DR0 one per wake, then back off 1 h,
2 h, 4 h, 8 h, 8 h … Uplinks are not sent while unjoined; the FSM keeps
TX pending, so the first wake after a successful join transmits immediately.

### 8.6 Node brought back into range
Whatever state it is in, the next probe ACK (degraded/floor) or the next join
attempt (rejoin/backoff) succeeds and the node returns to §8.1 or §8.2. An
installer can skip the wait with the BLE LoRa test (§9).

### 8.7 Session lost on the network side
E.g. device re-registered in TTN, or TTN forgot the session. TTN silently drops
the uplinks, probes get no ACK, and the node behaves as in §8.5 until the
rejoin (~32 h). To shorten this, trigger *Clear Session* over BLE.

### 8.8 Sitting at SF12 on a short heartbeat
An SF12 frame is ~1.5 s on air (1.65 s with Extended Mode blocks). At a 1 h
heartbeat that is ~36 s/day, over TTN's 30 s fair use. So when the node is at
DR0 **and** `tx_interval` is below 2 h, every other routine uplink is skipped
(`SF12 fair use: routine uplink skipped`), which brings it to ~18 s/day. Probes,
weight-anomaly frames and the BLE test always go. A skipped uplink is not
retried and does not move the anomaly baseline (`last_tx_*`). Temperature
anomalies are unconfirmed, so every other one can be skipped at SF12.

### 8.9 Transmit fails before reaching the air
Radio error, MAC busy, duty-cycle limit. `lora_send()` returns the error, the
FSM sets TX pending, and the next wake transmits regardless of the heartbeat.

### 8.10 Firmware update
A new image whose session struct has a different size logs
`Session size mismatch` and joins again once. A link-state record of a
different size is reset to healthy defaults. Frame counters and keys are then fresh; nothing else to do.

### 8.11 Configuration by downlink
Any downlink on these ports changes one setting, persisted immediately:

| FPort | Setting | Payload |
|---|---|---|
| 10 | `tx_interval` (heartbeat) | uint32 BE seconds, must be ≥ `ms_interval` |
| 11 | `ms_interval` (measure period) | uint32 BE seconds, ≥ 60, ≤ `tx_interval` |
| 12 | weight anomaly threshold | uint16 BE |
| 13 | temperature anomaly threshold | uint16 BE |

`web/encoder.html` builds these payloads. Downlinks are only received after an
uplink (Class A), so a queued command takes effect at the next transmitting
wake.

---

## 9. Installer actions over BLE (SETUP mode)

| Action | Effect |
|---|---|
| **LoRa test** | Joins if needed and sends one frame in a dedicated thread. Marks the wake *manual*: the SF12 join backoff and the fair-use skip are bypassed, because the installer is standing next to the node. |
| **Clear Session** | Deletes the stored session. The next transmit joins from scratch (DR3). |

---

## 10. Tunables

In [`lora.c`](../src/drivers/lora.c):

| Constant | Value | Meaning |
|---|---|---|
| `HEALTHY_DR` | DR3 (SF9) | first join attempt |
| `PROBE_EVERY_N_UPLINKS` | 4 | healthy probe cadence (must be even) |
| `PROBE_EVERY_N_DEGRADED` | 4 | degraded probe cadence (must be even) |
| `LINK_FAIL_REJOIN` | 8 | consecutive no-ACK probes before a rejoin |
| `DR0_MIN_TX_INTERVAL_S` | 7200 | below this heartbeat, skip every other SF12 uplink |
| `JOIN_BACKOFF_BASE_S` | 3600 | first SF12 join backoff |
| `JOIN_BACKOFF_MAX_SHIFT` | 3 | backoff doubles up to 8 h |

Other settings: NbTrans = 1 (a confirmed frame is sent once, never repeated
by the MAC); `CONFIG_LORAWAN_SYSTEM_MAX_RX_ERROR=100` in `prj.conf`.

Airtime reference (EU868, 125 kHz, CR 4/5):

| SF | 8-byte uplink | per day at 1 h |
|---|---|---|
| SF7 | 62 ms | 1.5 s |
| SF9 | ~0.2 s | ~5 s |
| SF12 | ~1.5 s | ~36 s (fair use: 30 s) |

---

## 11. Build requirement: app and LoRaMac must agree on the session layout

The session blob is `sizeof(LoRaMacNvmData_t)` **as `lora.c` sees it**. That
struct changes size with the `REGION_*` and `SOFT_SE` defines. The LoRaMac
library is compiled with them; `lora.c` must be too. `CMakeLists.txt` adds them
to the app, and `lora.c` fails to compile if they are missing.

Before this was fixed (2026-09-30) the app saw 728 B instead of 1120 B. Every
save dropped the end of the struct, which holds the channel table. After a
wake the node knew only 3 channels, NACKed the channel mask of every
LinkADRReq, and TTN's ADR could never move it. Nodes sat at SF8–SF12 next to
a gateway.

If you touch LoRaMac internals from app code, compare the `-D` flags of
`src/drivers/lora.c` and `mac/LoRaMac.c` in `build/compile_commands.json`.

---

## 12. Troubleshooting

### Device log

| Line | Meaning |
|---|---|
| `Session restored, DevAddr: …` | normal wake with a stored session |
| `No saved session, joining via OTAA` | join (§3) |
| `Session size mismatch` | image changed the session layout; one rejoin follows |
| `Link policy: fresh join DR3 (SF9) + ADR` | joined; ADR takes over |
| `Link policy: DEGRADED DR1 (SF11) sparse-probe` | pinned by the ladder (§7) |
| `Probe uplink (8 B) ACKed` / `no-ACK` | probe result |
| `Degraded: ADR off, DR2 (SF10) (2 no-ACK)` | ladder stepped down |
| `DR floor: probe no-ACK (6/8)` | at SF12, counting towards a rejoin |
| `Link recovered → ADR` | probe ACKed, ADR back on |
| `No downlink for 8 probes … OTAA rejoin next boot` | rejoin scheduled |
| `SF12 join failed — backing off 3600 s (12 wakes)` | join backoff started |
| `Join backoff: next SF12 try in N wake(s)` | waiting, no radio use |
| `SF12 fair use: routine uplink skipped` | §8.8 |
| `Persisting pending MAC answers:` / `Re-queued …` | §5 |
| `Datarate changed: DR_5` on the first uplink of a wake | cosmetic: Zephyr resets its RAM copy of the DR at boot |

Enable `LOG_DBG` in `lora.c` to also get the channel table
(`ch[joined|restored|save] mask=0x00ff f/100k=8681 8683 8685 8671 …`).

### TTN console

| Symptom | Meaning |
|---|---|
| Uplinks on 867.x MHz as well as 868.x | channel table intact |
| Uplinks **only** on 868.1/868.3/868.5 | channel table lost (§11) |
| Uplink `f_opts` `03 07` | LinkADRAns: all accepted |
| Uplink `f_opts` `03 06`, event `link_adr.answer.reject` | channel mask NACKed (§11) |
| A LinkADRReq downlink after **every** uplink | answers lost (§5) or rejected (§11) |
| `ns.mac.command.unanswered` | the node never answered; answers lost across sleep |
| `adr` missing on uplinks | node is degraded (ADR off) |
| SF stays high while RSSI is strong | ADR blocked; check the two rows above |

Decoding `f_opts` of a LinkADRReq, e.g. `03 52 ff00 01`: `03` = LinkADRReq,
`5` = DR5, `2` = TX power index 2, `ff00` = channels 0–7, `01` = NbTrans 1.

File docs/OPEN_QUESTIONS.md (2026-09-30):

# TanenBase — Open Questions

## Resolved (Default Assumptions)

| # | Question | Default Assumption |
|---|---|---|
| 1 | LoRaWAN payload format details (port, field sizes) | Per TRD Section 6: big-endian, port 1, fields: weight(4B), temp(2B), battery(2B), flags(1B) |
| 2 | T_TX default interval | 15 minutes (configurable via BLE/NVS) |
| 3 | T_MEAS default interval | 14 minutes (must be < T_TX, enforced by firmware) |
| 4 | Anomaly weight delta threshold | 500g default (configurable via BLE/NVS) |
| 5 | BLE advertising name | "TanenBase" |
| 6 | BLE advertising timeout in Setup mode | 5 minutes, then enter sleep |
| 7 | NAU7802 gain setting | 128x (default for load cell) |
| 8 | NAU7802 sample rate | 10 SPS (lowest power) |
| 9 | DS18B20 resolution | 12-bit (default) |
| 10 | Max LoRaWAN join retries before sleep | One attempt per wake, DR3→DR0, then SF12 backoff 1/2/4/8 h — see [LORAWAN.md](LORAWAN.md) §3 |
| 11 | Watchdog timeout | 120 seconds (production only) |
| 12 | NVS partition size | 4KB |

## Unresolved

| # | Question | Impact | Proposed Default |
|---|---|---|---|
| 1 | How does user enter Setup mode? Button press on P0.00? Long press duration? | FSM entry logic | 3-second long press on TanenButton (P0.00) enters Setup |
| 2 | Should downlink commands be supported? (remote config change via TTN) | Transmission feature scope | Implemented — FPort: 10=tx_interval, 11=ms_interval, 12=weight_th, 13=temp_th |
| 3 | LoRaWAN confirmed vs unconfirmed uplinks? | Transmission reliability vs airtime | Unconfirmed by default, configurable |
| 4 | Multiple DS18B20 sensors on same 1-Wire bus? | Devicetree + measurement feature | Single sensor for MVP, extensible |
| 5 | OTA firmware update mechanism? | Long-term maintenance | Out of scope for MVP |
| 6 | Web app (index.html) — who builds it? Scope? | Sprint 10 | Basic config page: set intervals, calibrate, view readings, set LoRaWAN keys |
| 7 | ~~TTN payload decoder — update for failed-sensor sentinels → null?~~ — **RESOLVED (2026-07-07):** done as part of Sprint 14's payload widening. `ttndecoder/beepdecoder.js` + `custumdecoder.js` now map `0xFFFFFF`/`0xFFFF`/`0x7FFF` to `null`. | Server-side decoder correctness | — |
| 8 | Adopt MCUboot/sysbuild builds now, or defer to a hardware rev? | One-time reprovision needed for any already-flashed units (ZMS location pin) | Adopt now — `pm_static.yml` protects existing storage_partition address |
| 9 | Production MCUboot signing key — where does it live / who holds it? | `SB_CONFIG_BOOT_SIGNATURE_KEY_FILE` currently unset (dev default) | Generate + store outside repo, same policy as `prj_credentials.conf` |
| 10 | ~~Web Bluetooth pairing UX for encrypted cred writes~~ — **RESOLVED (2026-07-07): reverted.** `BT_GATT_PERM_WRITE_ENCRYPT` on AppKey/DevEUI/JoinEUI broke real provisioning — Web Bluetooth has no `pair()` API, the OS-triggered SMP pairing hung mid-write, link died on supervision timeout (disconnect reason 8), `bt_le_adv_start` then failed `-ENOMEM`. Now plain R/W. | Credential confidentiality relies on physical proximity (BLE range) only, not link encryption | If encryption is required later: a companion native/mobile app that can call `pair()`, or app-layer encryption of the AppKey payload before the GATT write |
| 11 | ~~BEEP not receiving uplinks after payload widened to 8 bytes~~ — **RESOLVED (2026-07-07):** not a payload issue. BEEP's `/api/lora_sensors` resolves the target device via `payload_fields.hardware_serial` (TTN Stack V2) when no explicit `key` is supplied; this app's webhook is Stack V3, which puts the identifier at `end_device_ids.dev_eui` instead, so BEEP silently failed to route the (correctly-decoded) measurement to any device. Fixed by setting the TTN webhook base URL to `https://api.beep.nl/api/lora_sensors?key=<DevEUI>`. See Sprint 14 in PLAN.md and `ttndecoder/Beep-Sensor-data-API-v0.5.pdf`. | External webhook config only — no firmware/decoder involvement | Document the `?key=<DevEUI>` webhook URL requirement wherever TTN integration setup is documented, so a future BEEP webhook (re)creation doesn't regress this |

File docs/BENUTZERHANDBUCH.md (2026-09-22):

# TanenBase Stockwaage — Benutzerhandbuch

**Für Imkerinnen und Imker. Ohne Technikkenntnisse.**

Dieses Handbuch führt Sie durch Aufbau, Montage, Einrichtung und Kalibrierung
Ihrer TanenBase Stockwaage. Sie brauchen dafür kein Elektronikwissen und keine
App.

---

## Inhalt

1. [Vorbereitung & Hardware-Überblick](#1-vorbereitung--hardware-überblick)
2. [Montage am Bienenstock](#2-montage-am-bienenstock)
3. [Erstinbetriebnahme & Web-Interface](#3-erstinbetriebnahme--web-interface)
4. [Kalibrierung der Waage](#4-kalibrierung-der-waage)
5. [Fehlerbehebung & Pflege](#5-fehlerbehebung--pflege)
6. [Anbindung an eine Auswerteplattform (optional)](#6-anbindung-an-eine-auswerteplattform-optional)

---

## 1. Vorbereitung & Hardware-Überblick

### Was die Waage für Sie tut

Die TanenBase steht unter Ihrem Bienenstock und macht drei Dinge:

- Sie **wiegt** den Stock — auf wenige Gramm genau.
- Sie **misst die Temperatur**.
- Sie **funkt** die Werte in regelmäßigen Abständen zu Ihnen — ohne Kabel und
  ohne Mobilfunkvertrag.

So sehen Sie von zu Hause aus, ob der Nektar fließt, ob geschwärmt wurde oder ob
ein Volk plötzlich leichter wird — ohne den Stock zu öffnen.

Zwischen den Messungen schläft die Station fast vollständig. Ein Satz Batterien
hält deshalb **rund viereinhalb Jahre** — bei einer Messung alle 15 Minuten und
einer Meldung alle zwei Stunden. Wer seltener messen und melden lässt, kommt auf
deutlich mehr: bei stündlicher Messung und Meldung alle vier Stunden sind es
rechnerisch etwa zehn Jahre. Mit Bluetooth-Sensoren (Abschnitt 3.7) sucht die
Station bei jedem Senden kurz nach ihnen; dann sind es rund drei Jahre
beziehungsweise rund sieben Jahre.

> **Wichtig:** Die Station braucht **keinen Netzstrom** und **kein WLAN**. Nur
> die eingelegten Batterien und Funkempfang am Standort.

### Die Teile im Überblick

| Teil | Wozu |
|---|---|
| **Wägezelle** (z. B. Bosche H40A-C3-0150) | Der eigentliche Gewichtssensor. Sitzt mittig unter der Waage. Andere Zellen bis 150 kg gehen auch — Sie stellen sie auf der Bedienseite ein (Kapitel 4.3). |
| **Waagengestell** | Zwei Platten (oben/unten), zwischen denen die Wägezelle sitzt. Selbst gebaut oder fertig gekauft. |
| **Elektronik-Gehäuse** | Wetterfeste Box mit durchsichtigem Deckel. Darin steckt die Technik. |
| **Roter Knopf** | Seitlich am Gehäuse. Damit starten Sie die Einrichtung. |
| **Aufkleber mit QR-Code** | Auf der Box. Enthält die Gerätenummer (**DevEUI**) Ihrer Station. |
| **Zwei Kabelverschraubungen** | Unten an der Box. Hier gehen die Kabel wasserdicht heraus. |
| **Temperaturfühler** | Wasserdichter Fühler am Kabel. Kommt an die Wägezelle (siehe Kapitel 2.4). |
| **Batterien** — 3 × AAA Lithium (1,5 V, 1200 mAh, z. B. BEVIGOR) | Versorgen alles. In Reihe ergeben sie **frisch rund 5,2 Volt**. **Nicht aufladbar!** |
| **Antenne** | Liegt im Gehäuse. Nicht knicken, nicht mit Metall abdecken. |

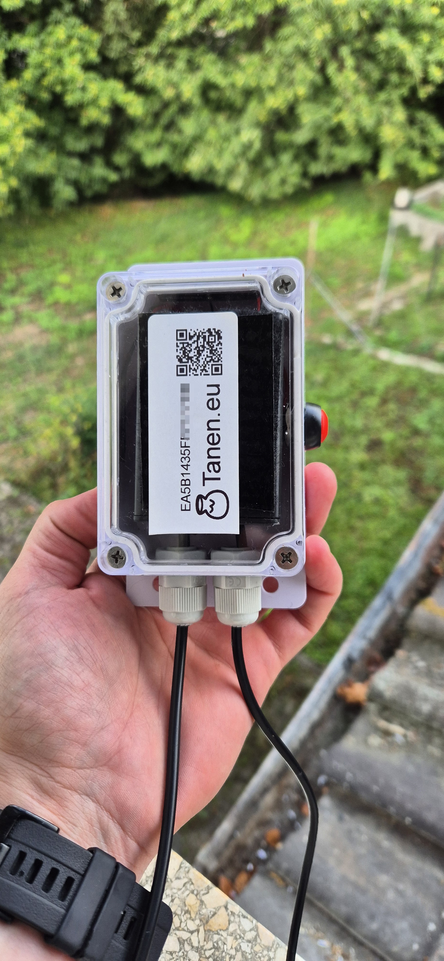
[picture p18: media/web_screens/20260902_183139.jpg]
Die Station geschlossen, in der Hand


> **[Bild 1: Die geschlossene Station]** — Gut zu sehen: der **rote Knopf**
> rechts am Gehäuse, der Aufkleber mit **QR-Code und Gerätenummer**
> („EA5B1435F…") und die **zwei Kabelverschraubungen** unten, aus denen die
> beiden schwarzen Kabel kommen.

Die Station geöffnet

> **[Bild 2: Blick in die geöffnete Station]** — Nur für den Notfall wichtig.
> Sie sehen die Platine, den kleinen Schiebeschalter **„OFF / ON"** oben rechts,
> die **blaue Klemme** für den Temperaturfühler und die **grüne Klemme** für die
> Wägezelle. Im Normalbetrieb bleibt der Deckel zu.

Die Wägezelle von unten

> **[Bild 3: Die Wägezelle aus der Nähe]** — Auf dem hellen Aluminiumblock steht
> die Nummer **N-150-B** und darunter ein **Pfeil nach unten (⇓)**. Dieser Pfeil
> muss beim Einbau nach unten zeigen. Merken Sie sich das — es ist der häufigste
> Montagefehler.

Die fertige Plattform

> **[Bild 4: Die fertige Waage im Feld]** — Schwarz lackierte Holzplattform, das
> Elektronik-Gehäuse ist an der Kante festgeschraubt, die Kabel laufen nach unten.

### Was Sie zusätzlich brauchen

**Werkzeug**

- Schraubendreher (Kreuzschlitz) und Schraubenschlüssel
- **Wasserwaage** — unbedingt nötig
- Kabelbinder
- Optional: Aluminium-Klebeband und etwas Wärmeleitpaste für den Temperaturfühler

**Zum Kalibrieren**

- Ein **Gewicht, das Sie genau kennen** — z. B. ein voller 10-Liter-Wasserkanister
  (10 Liter Wasser = 10,0 kg) oder ein abgewogener Betonstein.
- Je schwerer, desto genauer. **10 bis 25 kg** sind ideal.

**Zum Einrichten**

- Ein **Android-Handy** oder ein **Laptop** (Windows / Mac / Linux)
- Darauf der Browser **Chrome** oder **Edge**

> ⚠️ **iPhone und iPad funktionieren nicht.** Safari und Firefox ebenfalls nicht.
> Diese Browser können die Bluetooth-Verbindung zur Station technisch nicht
> aufbauen. Leihen Sie sich für die Einrichtung ein Android-Gerät oder nehmen Sie
> einen Laptop mit.

### Sicherheitshinweise

- Es sind **Lithium-Primärzellen. Niemals laden.** Nicht öffnen, nicht ins Feuer
  werfen, nicht kurzschließen.
- **Immer alle drei Zellen gemeinsam wechseln** und nie alte mit neuen mischen.
- Schließen Sie **kein USB-Kabel** an, solange die Batterien eingelegt sind.
- Stellen Sie das Gehäuse **nicht in die pralle Sonne**. Im Schatten unter der
  Plattform bleibt die Elektronik kühler und die Batteriespannung niedriger.
- **Nicht auf die Plattform steigen.** Das nimmt Ihnen die Wägezelle übel.
- Die Waage ist wetterfest, aber **kein Tauchgerät**. Nicht mit dem
  Hochdruckreiniger abspritzen.

---

## 2. Montage am Bienenstock

### 2.1 Das Prinzip in einem Satz

In der **Mitte** zwischen zwei Platten sitzt **eine einzige Wägezelle**, die die
komplette obere Platte trägt. Deshalb ist es egal, wo genau auf der Plattform der
Stock steht — das Gewicht stimmt trotzdem.

Diese Bauart heißt **Single-Point-Zelle**. Sie ist der Grund, warum die Waage so
einfach zu bauen ist.

Die Waage von der Seite

> **[Bild 5: Der Aufbau von der Seite]** — Sehr gut zu erkennen: unten die
> Bodenplatte, oben der Rahmen, und **genau dazwischen in der Mitte** die
> silberne Wägezelle mit ihren beiden Verteilerplatten. Die obere Platte
> **schwebt** — sie berührt nur die Wägezelle, sonst nichts.

### 2.2 Das Gestell bauen

Sie können jedes Gestell verwenden, das stabil ist. Eine sehr gute, bebilderte
Bauanleitung finden Sie hier:

👉 **[HoneyPi — Aufbau des Waagengestells](https://honey-pi.de/teil-4-aufbau-des-waagengestells/)**

Ob Sie Holz, Alu-Profil oder Stahl verwenden, ist Ihnen überlassen. **Wichtig ist
allein, dass die Wägezelle richtig eingebaut ist.** Halten Sie sich dabei an die
folgenden fünf Regeln.

### 2.3 Die fünf Regeln für die Wägezelle

**Regel 1 — Der Pfeil zeigt nach unten**

Auf der Wägezelle ist ein Pfeil (⇓) eingraviert (siehe Bild 3). Er zeigt in die
Richtung, aus der die Last kommt — also **nach unten zum Boden**. Falsch herum
eingebaut misst die Waage negativ oder gar nicht.

**Regel 2 — Fest verschraubt zwischen zwei steifen Platten**

- Die **untere Hälfte** der Zelle wird auf die Bodenplatte geschraubt.
- Die **obere Hälfte** trägt die obere Platte.
- Verwenden Sie auf beiden Seiten **alle Schraubenlöcher** und ziehen Sie die
  Schrauben **fest** an.
- Legen Sie zwischen Zelle und Holz jeweils eine **Metall-Verteilerplatte**
  (siehe Bild 5). Direkt auf Holz geschraubt arbeitet die Zelle mit dem Holz mit,
  und die Werte wandern.

**Regel 3 — Die obere Platte muss frei schweben**

Das ist die wichtigste Regel überhaupt.

- Rundherum muss ein **Spalt von mindestens 5–10 mm** bleiben.
- Nichts darf die obere Platte berühren: kein Stein, kein Grashalm, kein Kabel,
  keine Nachbarbeute, kein Spanngurt zum Boden.
- Prüfen Sie das nach dem Aufbau von Hand: obere Platte leicht anheben und
  loslassen — sie muss frei federn.

> 💡 **Merksatz:** Was die obere Platte berührt, wird nicht mitgewogen. Ein
> einziger Grashalm kann Ihnen ein halbes Kilo Honigertrag verstecken.

**Regel 4 — Kabel nach unten, mit Schlaufe**

Das Kabel der Wägezelle läuft nach unten weg (siehe Bild 5). Legen Sie kurz vor
dem Gehäuse eine **Tropfschlaufe** — eine Hängeschlaufe nach unten —, damit
Wasser am Kabel abtropft und nicht in die Verschraubung läuft. Befestigen Sie das
Kabel mit Kabelbindern, aber **niemals stramm gespannt**. Zug am Kabel verfälscht
die Messung.

**Regel 5 — Nicht überlasten**

Die Zelle verträgt 150 kg. Ein Stock wiegt selten mehr als 60 kg. Trotzdem:
**nicht draufsteigen, nicht als Hebel benutzen, nichts draufwerfen.** Ein
einziger harter Stoß kann die Zelle dauerhaft verbiegen.

### 2.4 Der Temperaturfühler — direkt an die Wägezelle

Das ist der Trick, der Ihre Waage genau macht.

**Warum?** Metall dehnt sich bei Wärme aus. Die Wägezelle zeigt bei Sonne deshalb
ein anderes Gewicht an als nachts — obwohl sich am Stock nichts geändert hat. Die
Station rechnet diesen Fehler automatisch heraus. Dafür muss sie aber wissen,
**wie warm die Wägezelle gerade ist**. Nicht die Luft. Nicht der Stock. **Die
Zelle.**

**So machen Sie es richtig:**

1. Legen Sie den Temperaturfühler **direkt an den Aluminiumkörper** der Wägezelle
   an — flach anliegend, nicht in der Luft baumelnd.
2. Befestigen Sie ihn mit **zwei Kabelbindern** oder einem Streifen
   **Aluminium-Klebeband**. Ein Klecks Wärmeleitpaste dazwischen ist ideal, aber
   nicht zwingend.
3. Der Fühler muss **im Schatten** liegen — also unter der Plattform. Nie in der
   direkten Sonne.
4. Legen Sie auch hier eine **Tropfschlaufe** ins Kabel.

> **[Foto einfügen: Temperaturfühler mit Kabelbindern an der Wägezelle
> befestigt, Nahaufnahme von unten]**

Die Wägezelle im eingebauten Zustand

> **[Bild 6: Einbaulage der Wägezelle]** — So sieht der fertige Einbau von unten
> aus. Der Temperaturfühler gehört an diesen Aluminiumblock.

> ℹ️ **Hinweis:** Wenn Sie stattdessen die **Temperatur im Stock** messen wollen,
> stecken Sie den Fühler in den Stock. Dann verlieren Sie aber die automatische
> Korrektur, und Ihr Gewicht schwankt über den Tag um mehrere hundert Gramm.
> **Unsere klare Empfehlung: Fühler an die Wägezelle.**

### 2.5 Das Elektronik-Gehäuse befestigen

1. Schrauben Sie das Gehäuse **auf die obere Platte** oder an den Rahmen — so wie
   in Bild 4.
2. Die **Kabelverschraubungen müssen nach unten zeigen**. Nie nach oben, sonst
   läuft Regenwasser hinein.
3. Ziehen Sie beide **Verschraubungen handfest** nach, bis die Kabel nicht mehr
   rutschen.
4. Stellen Sie das Gehäuse möglichst in den **Schatten** — unter dem Blechdach,
   an der Nordseite oder mit einem kleinen Brett darüber.
5. Ziehen Sie alle **vier Deckelschrauben** gleichmäßig an. Die Dichtung muss
   rundum anliegen.
6. **Kein Metall über der Antenne.** Kein Blechdach direkt darüber, kein
   Metallgitter. Das schluckt den Funk.

> **[Foto einfügen: Elektronik-Gehäuse an der Plattform verschraubt,
> Kabelverschraubungen nach unten, Tropfschlaufen sichtbar]**
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

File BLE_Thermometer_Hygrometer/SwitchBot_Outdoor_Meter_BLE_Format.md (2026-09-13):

# SwitchBot Outdoor Meter (WoIOSensorTH) BLE Format

This document explains how to decode the Bluetooth Low Energy (BLE) advertisement packets sent by the SwitchBot Outdoor Thermometer/Hygrometer. You can use this logic to implement a scanner on the nRF52 using the nRF Connect SDK or nRF5 SDK.

## Overview

The SwitchBot Outdoor Meter broadcasts two important AD (Advertisement Data) structures:
1. **Manufacturer Specific Data (`0xFF`)**: Contains the Temperature and Humidity.
2. **Service Data - 16-bit UUID (`0x16`)**: Contains the Battery level.

---

## 1. Manufacturer Specific Data (Temperature & Humidity)

When you receive a BLE advertisement packet, look for the AD type `0xFF` (Manufacturer Specific Data). The total length of the payload for the Outdoor Meter is typically 14 bytes.

**Example Payload (14 bytes):**
`69 09 eb 6b 04 06 0b 6b 3c 02 08 99 2c 00`
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

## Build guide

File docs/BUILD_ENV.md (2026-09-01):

# 🛠️ Build Environment — Tanen Project

**Date:** 2026-08-03
**Purpose:** Document the development environment setup for TanenBase on the Hermes server

## Project

**TanenBase** — low-power LoRaWAN beehive monitor:
- **MCU:** Seeed Studio XIAO nRF54LM20A
- **Radio:** Wio-SX1262 LoRa (LoRaWAN Class A, OTAA, EU868)
- **Sensors:** NAU7802 (load-cell) · DS18B20 (temp) · nPM1300 (battery)
- **SDK:** Zephyr 4.4 via nRF Connect SDK v3.4.0
- **Sleep:** ~4 µA — **~9 years** on a single AA cell

## Repository Layout

| Path | Description |
|---|---|
| `src/` | Firmware — core/ (FSM, power, watchdog) + drivers/ + features/ |
| `boards/` | Application devicetree overlay |
| `third_party/` | Seeed XIAO nRF54LM20A board definition |
| `Tanen_Base_pcb/` | KiCad carrier board (schematic, layout, gerbers) |
| `web/` | Web Bluetooth config page (`index.html`) + downlink encoder (`encoder.html`) |
| `ttndecoder/` | TTN payload formatters |
| `test_apps/measure_loop/` | Standalone sensor bring-up |

## Server Environment (2026-08-03)

### Installed ✅
- `west 1.5.0` + all Python requirements (pyelftools, PyYAML, pykwalify, jsonschema, canopen, packaging, patool, psutil, pylink-square, pyserial, requests, semver)
- `ninja` + `cmake` (system)
- Python 3.13 (via venv `/opt/data/pylibs`)
- .NET 10 SDK (`/opt/data/dotnet`) — for AgOpenWeb
- **nRF Connect SDK v3.4.0** full in `/opt/data/ncs` (5.7GB — Zephyr 4.4 + nrf + nrfxlib + modules)
- **Zephyr SDK 1.0.1** in `/opt/data/zephyr-sdk-1.0.1` (829MB) — toolchain `arm-zephyr-eabi` (gcc 14.3.0) under `gnu/`

### ✅ Build verified (2026-08-03)
```bash
west build -b xiao_nrf54lm20a/nrf54lm20a/cpuapp -d build_test . \
  --no-sysbuild -- -DBOARD_ROOT=/opt/data/projects/tanen/third_party/seeed-xiao-nrf54lm20a
```
**Result:** SUCCESS — FLASH 11.95% / RAM 10.45% — `build_test/zephyr/zephyr.{elf,hex,bin}`

### Errors encountered & fixes
| Error | Fix |
|---|---|
| `No board named 'xiao_nrf54lm20a'` | Add `-DBOARD_ROOT=.../third_party/seeed-xiao-nrf54lm20a` (after `--`) |
| `ZEPHYR_EXTRA_MODULES not a valid module` | Don't use it — use BOARD_ROOT instead |
| `Unable to find 'x86_64-zephyr-elf' in .../gnu` | Toolchain must live at `gnu/arm-zephyr-eabi/` inside the SDK |
| MCUboot/sysbuild configure fail | Use `--no-sysbuild` (documented in README — sysbuild unsupported on LM20A) |

### Required later
- **KiCad** (for the PCB — optional on the server, more important on the user's machine)

## Build Commands

```bash
export PATH=/opt/data/pylibs/bin:$PATH
export ZEPHYR_BASE=/opt/data/ncs/zephyr
export ZEPHYR_TOOLCHAIN_VARIANT=zephyr

# From the project directory:
cd /opt/data/projects/tanen
west build -b xiao_nrf54lm20a/nrf54lm20a/cpuapp .
```

## Notes

- `build.ps1` / `flash_*.ps1` scripts are **Windows**-oriented — on Linux use west directly
- `prj_credentials.conf.example` → copy to `prj_credentials.conf` with your TTN keys
- sysbuild (MCUboot/OTA) is unverified on LM20A/NCS v3.4.0 — use `--no-sysbuild`

*Last updated: 2026-08-03 by Zena*

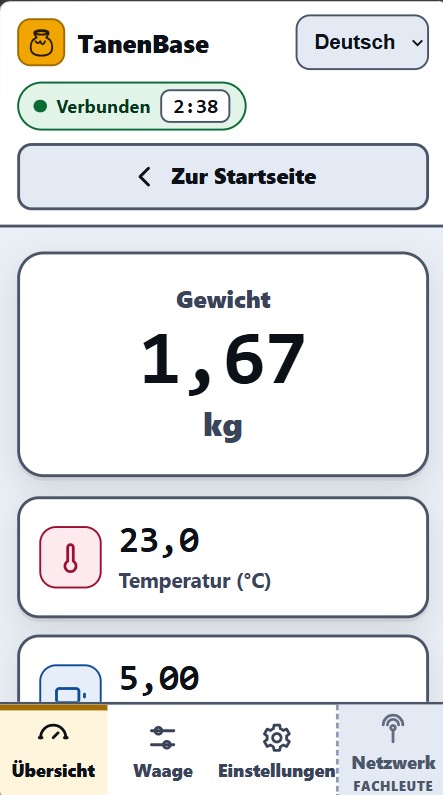
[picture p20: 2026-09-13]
media/screen_shots/setup_page.jpg

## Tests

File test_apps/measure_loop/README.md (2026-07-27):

# test_app: measure_loop

Standalone MEASUREMENT loop for PPK2 power profiling of TanenBase.

Same measurement sequence as `fsm_measure_and_decide` but stripped of LoRa,
BLE, anomaly, and System OFF. Runs forever, every `CONFIG_TANENBASE_TEST_INTERVAL_S`
seconds (default **5 s**). Works with USB unplugged — the loop never blocks on
serial.

## What the cycle does

Same as `fsm_measure_and_decide`, just without LoRa/anomaly:

```
boot           # GRTC wake → main() runs
measure_init   # NAU7802 PUA on, DS18B20 init, ADC init
measure_run    # weight + temp + battery, log values
weight_sleep   # NAU7802 PUD=0 (~1 µA)
power_off(5)   # System OFF, GRTC wake in 5 s → cold reboot
```

PPK2 trace: wake spike → ADC plateau → sleep drop → ~5 s System OFF floor
(~3 µA target) → next wake. Matches production trace 1:1.

## Build

From the repository root:

```powershell
.\build_test.ps1            # incremental
.\build_test.ps1 --pristine # clean rebuild
```

Build dir: `build_test/` (separate from main `build/`).

Or manually:

```powershell
west build -b xiao_nrf54lm20a/nrf54lm20a/cpuapp `
    -s test_apps/measure_loop -d build_test -- `
    -DBOARD_ROOT="$PWD/third_party/seeed-xiao-nrf54lm20a"
```

## Flash

```powershell
west flash -d build_test
```

To change interval without editing source:

```powershell
.\build_test.ps1 --pristine -- -DCONFIG_TANENBASE_TEST_INTERVAL_S=10
```

## Serial log

Console is **uart20** (TX P1.11 / RX P1.10) -> on-board CMSIS-DAP VCOM -> COM
port @115200. Do *not* add `-S cdc-acm-console`: on this board it repoints the
console at the nRF's own USBHS CDC, which never enumerates, and the log goes
silent.

```
[00:00:05.123] <inf> test_meas: === TanenBase test_app: measure_loop ===
[00:00:05.124] <inf> test_meas: Interval: 5 s
[00:00:05.250] <inf> config: Config loaded (...)
[00:00:05.255] <inf> test_meas: >>> Cycle 1
[00:00:06.480] <inf> measure: Weight=0 g, Temp=23.45 C, Battery=3712 mV
[00:00:11.500] <inf> test_meas: >>> Cycle 2
...
```

## PPK2 setup

1. Disconnect USB from XIAO.
2. PPK2 in **Source meter** mode, **3.3 V** (or 3.7 V to emulate Li-ion).
3. Wire `VOUT` → battery pad `+`, `GND` → board GND. **Do not** also power via USB.
4. Flash test firmware with USB connected, then unplug USB before starting capture.
5. Start logging in nRF Connect → Power Profiler. Expect ~5 s idle floor + brief
   measurement spikes every cycle.

> Tip: leave RTT viewer attached over SWD if you want logs without UART current cost —
> UART backend adds ~200 µA average due to TX activity each cycle.

## Switching back to the main app

Two separate build dirs — switching is just a different `west` invocation. No file
edits needed.

```powershell
# Main app
.\build.ps1                    # builds into build/
west flash -d build

# Test app
.\build_test.ps1               # builds into build_test/
west flash -d build_test
```

If you only have one build dir (`build/`) and want to flip:

```powershell
# To main
west build -b xiao_nrf54lm20a/nrf54lm20a/cpuapp --pristine `
    -- -DBOARD_ROOT="$PWD/third_party/seeed-xiao-nrf54lm20a" `
       -DOVERLAY_CONFIG="prj_credentials.conf;debug.conf"
west flash

# To test app
west build -b xiao_nrf54lm20a/nrf54lm20a/cpuapp --pristine `
    -s test_apps/measure_loop `
    -- -DBOARD_ROOT="$PWD/third_party/seeed-xiao-nrf54lm20a"
west flash
```

## Files

- `src/main.c` — 5 s loop
- `CMakeLists.txt` — pulls `config.c`, `weight.c`, `temp.c`, `battery.c`, `measure.c` from `../../src/`
- `prj.conf` — sensors + UART, no LoRa/BLE/PM
- `Kconfig` — stub LoRa creds + `TANENBASE_TEST_INTERVAL_S`
- `boards/xiao_nrf54lm20a_nrf54lm20a_cpuapp.overlay` — copy of the app overlay in `boards/` (same hardware)

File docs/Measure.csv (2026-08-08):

Timestamp(ms) | Current(uA)
125240 | 5.435
125250 | 3.369
125260 | 5.443
125270 | 3.888
125280 | 579.833
125290 | 1758.244
125300 | 3274.469
125310 | 2171.893
125320 | 1817.664
125330 | 2111.797
125340 | 2781.576
125350 | 2451.187
125360 | 2818.575
125370 | 4005.303
125380 | 4784.186
125390 | 4971.717
125400 | 4766.869
125410 | 5365.133
125420 | 6618.829
125430 | 7550.630
125440 | 8139.346
125450 | 8725.021
125460 | 9072.035
125470 | 9322.018
125480 | 9268.327
125490 | 9760.321
125500 | 9749.469
125510 | 9819.132
125520 | 9736.739
125530 | 9736.573
125540 | 9744.682
125550 | 9708.079
125560 | 10066.593
125570 | 9731.041
125580 | 10017.922
125590 | 10704.554
125600 | 9554.171
125610 | 9814.609
125620 | 10178.046
125630 | 9938.091
125640 | 9814.764
125650 | 9922.912
125660 | 9888.358
125670 | 10073.733
125680 | 9814.179
125690 | 9761.853
125700 | 9859.868
125710 | 9763.615
125720 | 9919.194
125730 | 9901.138
125740 | 9944.688
125750 | 10061.102
125760 | 10026.085
125770 | 10193.931
125780 | 10017.062
125790 | 9612.917
125800 | 9671.897
125810 | 9648.522
125820 | 9560.145
125830 | 9854.855
125840 | 10038.616
125850 | 9878.153
125860 | 9815.019
125870 | 10008.137
125880 | 9790.034
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

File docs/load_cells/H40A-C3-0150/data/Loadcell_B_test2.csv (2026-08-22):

time | Temperature (°C) | Weight (kg)
2026-08-16T00:01:46Z | 25 | 22.2
2026-08-16T00:07:00Z | 25 | 22.2
2026-08-16T00:12:13Z | 25 | 22.22
2026-08-16T00:17:27Z | 24.5 | 22.21
2026-08-16T00:22:41Z | 24.5 | 22.22
2026-08-16T00:27:55Z | 24.5 | 22.2
2026-08-16T00:33:09Z | 24.5 | 22.2
2026-08-16T00:38:23Z | 24.5 | 22.22
2026-08-16T00:43:37Z | 24 | 22.22
2026-08-16T00:48:51Z | 24 | 22.21
2026-08-16T00:54:05Z | 24 | 22.21
2026-08-16T00:59:19Z | 24 | 22.21
2026-08-16T01:04:33Z | 24 | 22.2
2026-08-16T01:09:46Z | 24 | 22.21
2026-08-16T01:15:00Z | 24 | 22.21
2026-08-16T01:20:14Z | 24 | 22.19
2026-08-16T01:25:28Z | 24 | 22.2
2026-08-16T01:30:42Z | 24 | 22.2
2026-08-16T01:35:56Z | 24 | 22.19
2026-08-16T01:41:10Z | 23.5 | 22.2
2026-08-16T01:46:24Z | 23.5 | 22.2
2026-08-16T01:51:38Z | 23.5 | 22.2
2026-08-16T01:56:52Z | 24 | 22.2
2026-08-16T02:02:05Z | 23.5 | 22.2
2026-08-16T02:07:19Z | 23.5 | 22.2
2026-08-16T02:12:33Z | 23.5 | 22.22
2026-08-16T02:17:47Z | 23.5 | 22.19
2026-08-16T02:23:01Z | 23.5 | 22.21
2026-08-16T02:28:15Z | 23.5 | 22.21
2026-08-16T02:33:29Z | 23.5 | 22.21
2026-08-16T02:38:43Z | 23.5 | 22.21
2026-08-16T02:43:57Z | 23.5 | 22.2
2026-08-16T02:49:11Z | 23.5 | 22.22
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

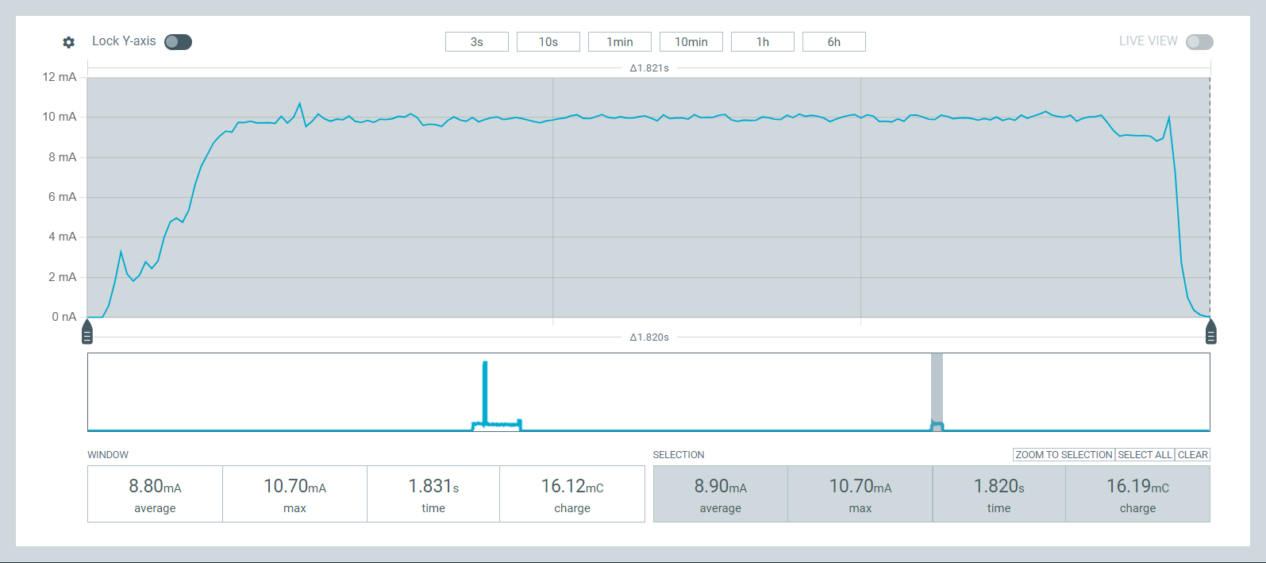
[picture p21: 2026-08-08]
docs/Measure.png

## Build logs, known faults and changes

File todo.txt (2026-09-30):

1-change  lorawan sucess  notification in german setup page to (LoRaWAN-Funktest: Erfolgreich)
2- add to BLE setup TanenBase Firmware   Ver.No user can see it in network tab 
3- relase 0.1.0
4- add implementation of the Relay LoRaWAN® Specification TS011-1.0.1

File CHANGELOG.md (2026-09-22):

# Changelog

Notable changes to TanenBase. Dates are the date the work landed.

The format loosely follows [Keep a Changelog](https://keepachangelog.com/).
Detailed per-sprint history lives in [`docs/PLAN.md`](docs/PLAN.md).

## [Unreleased]

### Changed
- **Power budget: TX with Extended Mode measured at 139 mC** (2026-09-13, PPK2:
  11.13 s, 12.49 mA avg, 77.78 mA peak) — the BLE scan adds 76 mC to the 63 mC
  uplink. Lifetimes recomputed with BLE sensors: 4.6 → **3.3 y** at 15 min / 2 h,
  10 → 7 y at 60 min / 4 h; nodes without them are unchanged. POWER_BUDGET,
  README, ARCHITECTURE, TRD, user manual and landing page updated
- **Wording** (2026-09-13): the German setup page and manual say *Sensor(en)*
  instead of *Fühler* for the Bluetooth sensors; the landing page says *keine
  Cloud* instead of *keine Zwangs-Wolke* (English and Arabic aligned)
- **Cell identified and the voltage deviation re-assessed against the chemistry
  handbook** (2026-09-10). The cells are **BEVIGOR AAA Li/FeS₂**. Energizer's
  LiFeS₂ handbook corrects three things: the old "OCV is highest when cold" note
  was backwards (the low-drain plateau *rises* with temperature — a hot hive is
  the worst case); at µA drain Li/FeS₂ holds ~1.79 V/cell "nearly independent of
  depth of discharge", so the pack is above the nPM1300's 4.45 V recommended
  maximum for **essentially its whole life**, not only while fresh; and the
  1.79–1.83 V fresh spread puts a worst-case pack at **5.49 V against the 5.5 V
  absolute maximum**. Mitigations added (reject cells > ~1.80 V at assembly,
  pre-drain, keep the enclosure out of the sun); invented AAA pulse ratings
  replaced by the handbook's AA figures
- **The built manual PDF is no longer versioned.** `docs/BENUTZERHANDBUCH.pdf`
  (2.4 MB, rewritten on every text change) is out of the repo and gitignored;
  `scripts/build_manual_pdf.py` now builds HTML only and takes `--pdf` when a
  PDF is actually wanted. The HTML manual stays versioned (2026-09-10)
- **Battery pack: single ER14505 AA Li-SOCl₂ → 3× AAA 1.5 V Li/FeS₂ in series**
  (1200 mAh, 4.5 V nominal, **5.2 V measured fresh**). Life at 15 min / 2 h drops
  9.3 y → **4.6 y** (~10 y at 60 min / 4 h). Gains: no passivation and no
  depassivation step, −40 °C rating (closes the old cold-temperature question),
  and ~10× pulse margin instead of the ER14505's marginal 91 mA row. Cost: the
  pack runs **above the nPM1300's 4.45 V recommended VBAT maximum** until it
  falls below ~1.48 V/cell, with 0.3 V to the 5.5 V absolute maximum — an
  accepted, documented deviation (`docs/POWER_BUDGET.md` §5.2), not a fix.
  Firmware is unchanged; charge/current figures are still 3.6 V PPK2 captures and
  have not been re-measured at 4.5 V. Docs updated across README, POWER_BUDGET
  (§5/§5.2/§6/§7/§8/§9/§10), ARCHITECTURE, TRD deviations, CONTRIBUTING, the user
  manual and the site (2026-09-10)

### Fixed
- **QR scanner could not read the sensor labels** (2026-09-13). The printed code
  is ~5 mm; the camera opened at default resolution and scanned the whole frame,
  and a failing `BarcodeDetector` was swallowed so the scan looped silently. Now:
  1920×1080 with continuous focus and 2× zoom where supported, an aim square
  whose centre is scanned enlarged (alternating with the full frame), fallback to
  jsQR when `BarcodeDetector` errors, a "Foto aufnehmen" path through the phone's
  camera app with a tiled search, and an info line (reader, resolution, zoom).
  Verified on a phone. Labels should still print the code at ≥ 12–15 mm with a
  white margin
- **SETUP with a dead or absent load cell: web app dropped after ~5 s, node
  watchdog-reset** (2026-09-13). BLE live readings (and tare/calibrate) ran
  `measure_run()` on the cooperative system workqueue; gpio-I2C busy-spins, and
  with no NAU7802 every SCL edge spins out the 100 ms clock-stretch timeout
  (~3.5 s per read, re-queued every 2 s). That starved the BT RX thread and
  `main` → GATT stalled, then the 60 s watchdog reset the node, whose reset wake
  skips SETUP. BLE sensor I/O now runs on a dedicated preemptible work queue,
  a live read is skipped while the last one is pending, and the queue is drained
  before SETUP returns. Pre-dates Extended Mode; found testing it on a bare board

### Added
- **Load-cell profiles — the firmware is no longer tied to the H40A**
  (2026-09-20). Which cell is fitted is now a runtime setting, picked on the
  setup page (*Waage → Wägezelle*) and stored in ZMS id 21: generic (no
  correction), Bosche H40A-C3-0150 (the measured 17.734 g/K · 25 min), four
  named cells that are not characterised yet (Steinberg SBS-PF-150, Zemic
  L6E/L6E3, TAL220/TAL220B, Flintec PC/SB — gain 0, so they behave like generic
  while still recording what is fitted, and a later firmware fills the constants
  in without the beekeeper touching anything), or own measured values entered as
  g/K and minutes. The temperature
  correction reads its two constants from that profile instead of Kconfig, so
  one image serves every build of the frame; non-custom profiles resolve from
  the table on every read, never from the stored copy; `CONFIG_TANENBASE_TEMPCOMP` still
  decides whether the correction is compiled at all and
  `CONFIG_TANENBASE_LC_DEFAULT_PROFILE` what an unprovisioned unit runs.
  New GATT characteristic `0x0010` (10 B, reads back the *effective* constants).
  Changing the profile does not invalidate the tare — the correction is zero at
  `T_ref` for any gain. **The SBS-PF-150 ships with gain 0 (uncorrected):** it
  has not been through the thermal sweep, and `k_c` belongs to the cell *plus
  its mount*, so a borrowed number would add error rather than remove it. New
  [`docs/load_cells/README.md`](docs/load_cells/README.md) documents the profile
  table, how to characterise a cell, and how to do it **from a production week**
  (gain 0, dead weight, 15–30 min uplinks, TTN export → the fit script) instead
  of a bench sweep
- **Extended Mode showcased on the landing page and in the README** (2026-09-13):
  own section with the sensor photo and the live setup-page screenshot
  (`media/BLE_Thermometer_Hygrometer_sensor.jpeg`,
  `media/screen_shots/BLE_Thermometer_Hygrometer_screen.jpeg`; 460 px copies in
  `site/media/`), nav link and spec-table row in DE/EN/AR
- **Extended Mode — up to 3 SwitchBot Outdoor Meter BLE sensors** (2026-09-13).
  At most 2 in-hive and 1 outside, set up in a new *Erweitert* tab of the web
  page (MAC typed or read from a QR label, role, per-sensor and master switch),
  stored in ZMS id 20; live readings show in the tab and on the overview.
  Scanned only on transmitting wakes and before the LoRa join (≤ 8 s, ends as
  soon as every enabled sensor has been heard); measure-only wakes never start
  BT. Each sensor heard appends a 5-byte block (slot/role, temperature,
  humidity, battery %) → 8/13/18/23-byte frames; a sensor not heard costs no
  airtime, only flags bit 3. `tanen-decoder.js` counts blocks from the length:
  the outside sensor becomes `t`/`TempOut` (+ `h`/`FeuchteOut`) and the DS18B20
  moves to `t_0`; in-hive sensors map to `t_i`/`h_i`/`TempIn`/`FeuchteIn` and
  `t_1`/`TempIn2`/`FeuchteIn2`. 8-byte frames decode exactly as before. New GATT
  characteristics `0x000E` ExtConfig and `0x000F` ExtLive; jsQR 1.4.0 vendored as
  `web/jsqr.js`, loaded only where the browser lacks `BarcodeDetector`.
  Verified on hardware (2026-09-13): three sensors live in SETUP, blocks in the
  uplink, TX wake measured at 139 mC
- **`ttndecoder/tanen-decoder.js`** — one uplink formatter for both supported
  platforms. Parses the 8-byte frame once and emits BEEP keys
  (`weight_kg`/`t`/`bv`) and beelogger keys (`Gewicht`/`TempOut`/`VBatt`) in the
  same `decoded_payload`; each server keeps what it knows. Invalid sensors stay
  `null` on both sides. The per-platform formatters (`beepdecoder.js`,
  `custumdecoder.js`, `tanen-beelogger-decoder.js`) are kept for reference
  (2026-09-09)
- beelogger documented as a supported platform alongside BEEP: README TTN
  section with the key-mapping table and the community-server webhook URL
  (`community.beelogger.de/<user>/{/devID}/beelogger_log.php?Passwort=…&LORA=1`
  — one webhook for the whole application, TTN device IDs named `beeloggerN`),
  `docs/ARCHITECTURE.md` "Server-Side Decoding", user manual chapter 6 rewritten
  from "BEEP-Plattform" to "Auswerteplattform" with a beelogger section, and a
  platform bullet on the site (de/en/ar). Both platforms confirmed receiving
  from the same uplink (2026-09-09)
- Open-source release: Apache-2.0 `LICENSE` + `NOTICE`, `README.md`,
  `CONTRIBUTING.md`, this changelog (2026-07-27)
- `prj_credentials.conf.example` so a fresh clone builds without secrets
- `scripts/ncs-env.ps1` — SDK/toolchain auto-discovery, overridable via
  `$env:NCS_ROOT` / `NCS_VERSION` / `NCS_TOOLCHAIN`
- `Tanen_Base_pcb/README.md` documenting XIAO footprint compatibility and
  fabrication notes
- **Second TanenButton on D19 (P0.00)** — a XIAO bottom pad, wired in parallel
  with the on-board P0.09 key. `button_arm_sense()` arms both as System OFF wake
  sources and `power_get_wake_reason()` ORs the two latches, so either press
  wakes into SETUP; they are read separately only so the log says which one
  fired. Carrier v0.1 does not route D19 — flying wire until v0.2 (2026-08-29)
- **`web/encoder.html`** — standalone LoRaWAN downlink builder for FPort 10–13
  (TxInterval, MsInterval, WeightThresh, TempThresh). Emits fPort + hex +
  base64 for the TTN console and a ready `down/push` body for the TTN API. No
  Bluetooth, so it works without a node in range
- Mandatory Wio-SX1262 rework documented in `Tanen_Base_pcb/README.md`: the
  kit's **K1 button + 10 kΩ pull-up sit on D0**, the DS18B20 1-Wire net, and
  with them fitted 1-Wire does not read at all. One trace cut lifts both off D0

### Fixed
- **nRF54LM20A anomaly [37]** — System OFF current above spec when entered soon
  after a pin reset or power cycle. Nordic's workaround (write 1 to the
  undocumented POWER register `0x5005340C`, ≥ 40 CPU cycles before System OFF)
  is applied in `power_off()`; the GRTC prepare that follows covers the delay
- **BLE "Send radio test" (ConfigCmd 0x04) sent a 1-byte `{0xFF}` uplink.** Both
  TTN decoders bail on `bytes.length < 8`, so the frame decoded to nothing and
  BEEP fell back to the raw byte — the phantom `255` seen on the platform. The
  test now sends the same 8-byte frame as a real uplink via `transmit_run()`
  (flags = 0, unconfirmed). Sensors are read *before* `lora_init()`/join, since
  a 2-3 s `measure_run()` after the join would land inside a JoinAccept/RX
  window; a total sensor failure is no longer fatal to the test — it sends the
  all-sentinel frame, which still decodes cleanly (2026-09-01)

### Changed
- **D5 = P1.07 is `LORA_RF_SW1`, not a spare GPIO.** The Wio-SX1262 brings its
  antenna-switch control out to that header pin. Firmware never drives it (the
  radio is `dio2-tx-enable`, so the SX1262 switches the path itself), but a
  pull-up or button there parks the switch and bills the System OFF budget.
  Corrected in the overlay comment, ARCHITECTURE, TRD, and the carrier README,
  all of which previously called D5 unused
- **Web config app rebuilt** — the `index2.html` redesign is now `index.html`
  (three-language DE/EN/AR, guided setup wizard, `device.svg` / `logo.svg`
  assets); the old `index2.html` is gone and the command encoder moved to its
  own page
- `docs/POWER_BUDGET.md` gains a third thing to check before blaming firmware
  for a sleep-current regression: **the carrier board**. A unit read 54 µA on
  2026-08-29 and was chased through the firmware for hours — wake-port choice,
  errata workarounds, A/B builds — before a carrier swap dropped it to 8 µA. The
  XIAO alone measured 3.7 µA throughout, which was the tell
- All build and flash scripts are now repo-relative — no absolute paths
- Vendored Seeed platform trimmed from 33 MB to the single nRF54LM20A board
  definition, under `third_party/seeed-xiao-nrf54lm20a/`
- Application devicetree overlay moved to `boards/`
- Documentation moved to `docs/` and re-pointed from the nRF54L15 to the
  nRF54LM20A; TRD gained an explicit "deviations from this TRD" section

## [0.9.0] — 2026-07-25 — nRF54LM20A port

### Changed
- **Target module: XIAO nRF54L15 → XIAO nRF54LM20A.** The carrier PCB is
  unchanged; both modules share the XIAO footprint and pinout
- nRF Connect SDK v3.2.4 → **v3.4.0** (Zephyr 4.2 → 4.4)
- GPIO remap — header *roles* preserved 1:1, underlying pins all changed; header
  SPI is now `spi23` (`spi00` is the on-board NOR)
- Battery sensing moved from an ADC divider + `vbat_pwr` gate to the on-board
  **nPM1300** factory-trimmed VBAT ADC — no divider, no calibration factor
- Console moved to `uart20` → CMSIS-DAP VCOM @115200 in **all** builds;
  `-S cdc-acm-console` removed (the nRF's USBHS CDC never enumerates on this board)
- DS18B20 resolution 10-bit → 9-bit (94 ms vs 187 ms conversion)
- `CONFIG_LORAMAC_REGION_*` → `CONFIG_LORAWAN_REGION_*` (Zephyr 4.4 rename)

### Fixed
- **Sleep current 19.4 µA → ~4 µA:** on-board py25q64 NOR now enters deep
  power-down before System OFF, and the nPM1300 auto-ADC (`IBAT_EN` +
  `TASK_AUTO`) is cleared — the PMIC keeps converting through the SoC's System OFF
- `pmic_i2c` pins corrected to SDA P1.18 / SCL P1.17 (board DTS declares
  P1.15/P1.16)
- `pmic_leds` disabled — the board DTS armed `led0-mode="error"`, which this unit
  would have sat in permanently
- Q_measure 16 → 12 mC, Q_tx 200 → 63 mC

### Security
- `charging-enable` **deleted** from `&pmic_charger`. This design runs a primary
  Li-SOCl₂ cell; with charging armed, applying VBUS would push charge current
  into a non-rechargeable lithium cell. `thermistor-ohms = <0>` since no NTC is
  fitted

## [0.8.0] — 2026-07-07 — 999 kg payload

### Changed
- Uplink payload 7 → **8 bytes**: weight widened to uint24 grams (0–999000),
  clamp raised from 65.535 kg. Temperature, battery, and flags shifted
- `last_tx_weight` and the anomaly baseline widened to match — they were silently
  capping deltas above 65 kg
- LiveSensors BLE notify widened 6 → 8 bytes
- Both TTN decoders now emit `null` for invalid sensors instead of a sentinel number

### Fixed
- Failed-sensor sentinel moved to `0xFFFFFF`, clear of the raised clamp — a
  maxed-out real reading and a dead sensor were previously indistinguishable
- **BEEP ingestion**: not a payload bug. BEEP routes on
  `payload_fields.hardware_serial` (TTN Stack **V2**) when given no explicit key;
  this application uses V3 webhooks, which carry the identifier at
  `end_device_ids.dev_eui`. Fixed externally by adding `?key=<DevEUI>` to the
  webhook URL

### Reverted
- `BT_GATT_PERM_WRITE_ENCRYPT` on the credential characteristics. Web Bluetooth
  has no `pair()` API; the OS-triggered SMP pairing hung mid-write until
  supervision timeout, and re-advertising then failed with `-ENOMEM`

## [0.7.0] — 2026-07-06 — field robustness

### Added
- `task_wdt` 60 s software channel backed by the `wdt31` hardware fallback, armed
  in `main()` and fed at every FSM boundary; long waits sliced ≤30 s
- `CONFIG_RESET_ON_FATAL_ERROR` + `CONFIG_HW_STACK_PROTECTION`; reset cause
  (watchdog / lockup / software) decoded and logged on boot
- `tx_pending` ZMS flag — a failed uplink retries on the *next* wake instead of
  waiting a full `tx_interval` in silence
- I2C bus recovery (`i2c_recover_bus()` + retry) on every NAU7802 transfer
- `measurement_data_t.valid` bitmask — a failed sensor is never transmitted as a
  real `0`
- `pm_static.yml` pinning `zms_storage`, and `sysbuild.conf` for OTA readiness

### Fixed
- DevNonce persistence now hard-fails the join rather than burning nonce 0
  repeatedly and draining the battery in a TTN-rejected retry storm
- `active_conn` mutex-guarded and `pending_cmd` made an atomic CAS gate — both
  were racy across the BT RX, system workqueue, and main threads
- `T_TX ≥ T_MEAS` cross-validated on both the downlink and BLE write paths

## [0.6.0] — 2026-06 — active power optimization

### Changed
- Measurement cycle 7.4 s / 133 mC → 420 ms / 6.76 mC (94% time, 95% charge)
- LoRaWAN DR3/SF9 instead of DR0/SF12 — roughly 8× shorter airtime
- NAU7802 PUR and CR-bit polling replace blind sleeps
- 5 s boot delay skipped on timer and button wakes

## [0.5.0] — 2026-06 — first complete node

### Added
- 4-state FSM, System OFF with GRTC timed wake (8 µA on the nRF54L15)
- NAU7802 weight, DS18B20 temperature, battery, SX1262 LoRaWAN OTAA to TTN
- BLE GATT configuration service (13 characteristics) + Web Bluetooth page
- Anomaly detection with delta-based transmission

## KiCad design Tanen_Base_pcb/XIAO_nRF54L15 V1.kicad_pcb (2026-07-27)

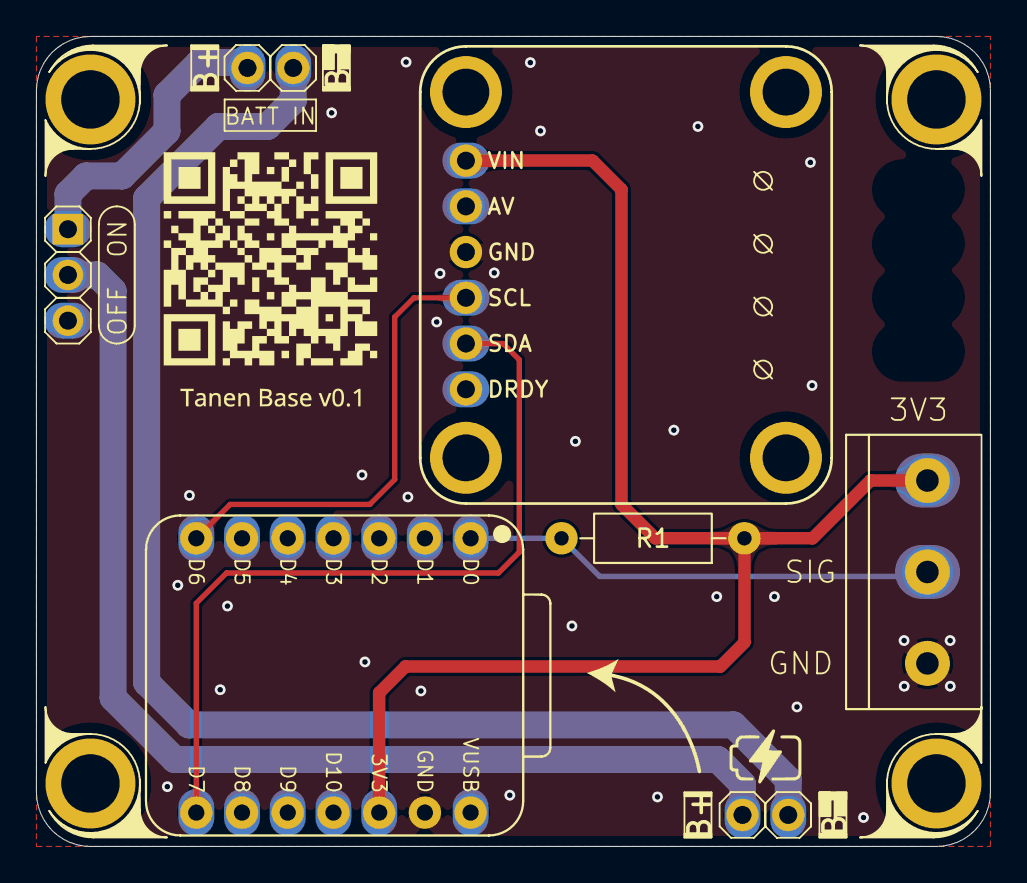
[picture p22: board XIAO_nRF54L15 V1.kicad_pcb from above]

Board: 2 copper layers, 53.0 x 45.0 mm, 7 parts (0 on the bottom side), 8 nets.

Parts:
J1: Screw_Terminal_01x03; TerminalBlock-3_P5.08mm
J2: BATT IN; PinHeader_1x02_P2.54mm_Vertical
J3: SW; PinHeader_1x03_P2.54mm_Vertical
J4: BATT O; PinHeader_1x02_P2.54mm_Vertical
R1: 4K7; R_Axial_DIN0207_L6.3mm_D2.5mm_P10.16mm_Horizontal
U1: XIAO-nRF54l15
U2: NAU7802_Adafruit

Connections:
+3.3V: J1.1, R1.1, U1.12 (3V3), U2.1 (VIN)
/D0: J1.2, R1.2, U1.1 (D0)
/D6: U1.7 (D6), U2.4 (SCL)
/D7: U1.8 (D7), U2.5 (SDA)
GND: J1.3, U1.13 (GND), U2.3 (GND)
unnamed: J2.1, J3.1
unnamed: J2.2, J4.2
unnamed: J3.2, J4.1

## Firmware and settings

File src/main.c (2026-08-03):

#include <zephyr/kernel.h>
#include <zephyr/logging/log.h>
#include "core/fsm.h"
#include "core/power.h"
#include "core/watchdog.h"

LOG_MODULE_REGISTER(main, LOG_LEVEL_INF);

int main(void)
{
    /* Watchdog FIRST — everything after this is supervised (TRD 13.1) */
    int ret = watchdog_init();
    if (ret < 0) {
        LOG_ERR("Watchdog init failed: %d — continuing UNSUPERVISED", ret);
    }

    /* Flash safety window — only on hard reset so System OFF can't brick board.
     * Timer/button wakes skip this to save 5s per cycle. */
    wake_reason_t reason = power_get_wake_reason();
    if (reason == WAKE_REASON_RESET) {
        k_sleep(K_SECONDS(5));
    }
    LOG_INF("TanenBase v0.3.0 initialized");
    /* Zena (2026-08-03): simple demo edit — visible from VS Code via git pull */

    ret = fsm_init();
    if (ret < 0) {
        LOG_ERR("FSM init failed: %d", ret);
        /* Field device: a dead-on-init unit must not park in main's return
         * path — reboot via watchdog starvation is pointless; sleep-retry
         * instead. GRTC wake re-runs full init from ROM. */
        (void)power_off(CONFIG_TANENBASE_DEFAULT_MS_INTERVAL);
        return ret;
    }

    while (1) {
        watchdog_feed();
        fsm_run();
    }

    return 0;
}

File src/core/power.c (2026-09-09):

#include <zephyr/kernel.h>
#include <zephyr/logging/log.h>
#include <zephyr/sys/poweroff.h>
#include <zephyr/drivers/timer/nrf_grtc_timer.h>
#include <zephyr/drivers/hwinfo.h>
#include <zephyr/logging/log_ctrl.h>
#include <zephyr/pm/device.h>
#include <zephyr/drivers/mfd/npm13xx.h>
#include <hal/nrf_gpio.h>

#include "power.h"

LOG_MODULE_REGISTER(power, LOG_LEVEL_INF);

/* TanenButton on P0.09 (board DTS: button0 / sw0) */
#define BUTTON_PIN NRF_GPIO_PIN_MAP(0, 9)

/* External TanenButton on D2 = P1.30, SHARED with the SX1262 NRESET net
 * (reset-gpios on the lora0 node). Same behaviour as the on-board one: either
 * press wakes into SETUP, so the two latches are simply OR-ed.
 *
 * Moved here from D19 = P0.00 on 2026-09-07: D2 is on a 7-pin header and the
 * carrier already routes it, where D19 is a XIAO bottom pad that needed a
 * flying wire. Wiring is a bare momentary switch to GND — no external pull-up,
 * no cap. Datasheet 'Port capabilities': P0, P1 and P3 are all wakeup sources
 * with SENSE/DETECT; only P2 is not.
 *
 * Sharing NRESET is safe because SETUP is a once-a-year calibration action and
 * the device is asleep 99.8% of the time (185 s awake/day at MS=900 s /
 * TX=14400 s):
 *  - Asleep: input + pull-up + SENSE_LOW. The pull-up (12/14/16 kOhm) holds
 *    NRESET high — exactly what the old 'drive RST HIGH' did — so the radio
 *    stays in its warm-start sleep.
 *  - A press pulls NRESET low: the SoC wakes AND the SX1262 resets. The radio
 *    reset is free: every wake is a full SoC reset, and sx126x_variant_init()
 *    configures reset-gpios GPIO_OUTPUT_ACTIVE (active LOW), so it drives
 *    NRESET low at device init anyway and holds the radio in reset until the
 *    app runs the LoRa init.
 *  - Awake: the pin belongs to the sx126x driver as an output, so a press is
 *    NOT latched and is simply lost (~0.2% of presses). Shorting a
 *    standard-drive pad to GND is harmless (I_OH,SD 1/3/4 mA vs a 15 mA
 *    all-GPIO budget). The SETUP LED is the user's feedback: no LED, press
 *    again.
 *  - A switch that fails CLOSED holds NRESET low: wake loop draining the cell
 *    plus a radio stuck in reset. Visible server-side within one heartbeat.
 *
 * History: was D11 = P3.00, moved to D19 = P0.00 on 2026-08-29 while chasing a
 * 54 uA System OFF reading blamed on P3 being a peripheral-domain port. THAT
 * WAS WRONG — the 54 uA was a carrier-board leak and a carrier swap fixed it.
 * No port has ever been shown to cost anything; do not cite a power argument
 * for the port choice. Avoid D22/D23 (P0.03/P0.04 carry GRTC PWM/CLKOUT32K). */
#define EXT_BUTTON_PIN NRF_GPIO_PIN_MAP(1, 30)

/* On-board py25q64ha NOR on spi00 — pins per the board dtsi (spi00 pinctrl +
 * cs/hold/wp-gpios). spi00 and the flash node are both disabled, so the
 * jedec,spi-nor driver never runs and never issues DPD: left alone the part
 * sits in standby (~10 uA class) with CS#/HOLD#/WP# floating. Seeed's own
 * low-power guide treats DPD + these exact pin states as mandatory to reach
 * the 3.74 uA System OFF reference for this board. */
#define FLASH_HOLD_PIN NRF_GPIO_PIN_MAP(2, 0)
#define FLASH_SCK_PIN  NRF_GPIO_PIN_MAP(2, 1)
#define FLASH_MOSI_PIN NRF_GPIO_PIN_MAP(2, 2)
#define FLASH_WP_PIN   NRF_GPIO_PIN_MAP(2, 3)
#define FLASH_MISO_PIN NRF_GPIO_PIN_MAP(2, 4)
#define FLASH_CS_PIN   NRF_GPIO_PIN_MAP(2, 5)

#define FLASH_CMD_DPD  0xB9

/* nRF54LM20A anomaly [37] — POWER: "Current consumption might increase after
 * pin reset or power cycle", symptom being a System OFF current higher than
 * spec when System OFF is entered too soon after a pin reset or power cycle.
 * Present in Engineering B and Revision 1. Nordic's workaround is to write 1 to
 * this undocumented POWER register and let >= 40 CPU cycles run before entering
 * System OFF. */
#define ANOMALY_37_REG 0x5005340CUL

/* nPM1300 register map (base, offset) — mirrors the private defines in
 * zephyr/drivers/sensor/nordic/npm13xx_charger/npm13xx_charger.c, which the
 * public mfd API deliberately does not export. */
#define NPM_ADC_BASE          0x05U
#define NPM_ADC_TASK_AUTO     0x0CU  /* periodic NTC/die-temp conversions */
#define NPM_ADC_IBAT_EN       0x24U  /* continuous battery-current sense */

/* Cache: System OFF clears RAM so reason_valid starts false on every boot */
static wake_reason_t cached_reason;
static bool reason_valid;

wake_reason_t power_get_wake_reason(void)
{
    if (reason_valid) {
        return cached_reason;
    }

    uint32_t cause = 0;
    (void)hwinfo_get_reset_cause(&cause);
    hwinfo_clear_reset_cause();

    /* Field diagnostics — a supervised recovery must be visible in logs */
    if (cause & RESET_WATCHDOG) {
        LOG_WRN("*** Recovered from WATCHDOG reset ***");
    }
    if (cause & RESET_CPU_LOCKUP) {
        LOG_WRN("*** Recovered from CPU LOCKUP ***");
    }
    if (cause & RESET_SOFTWARE) {
        LOG_WRN("*** Recovered from fatal-error reboot ***");
    }

    /* Latch can be stale (spurious set when SENSE is re-armed before pullup
     * settles) — always clear so it reflects only this wake. Both buttons mean
     * the same thing, so the two latches are OR-ed; they are read separately
     * only so a field log says which one was pressed. */
    bool latch = nrf_gpio_pin_latch_get(BUTTON_PIN);
    bool ext_latch = nrf_gpio_pin_latch_get(EXT_BUTTON_PIN);
    nrf_gpio_pin_latch_clear(BUTTON_PIN);
    nrf_gpio_pin_latch_clear(EXT_BUTTON_PIN);

    /* GRTC (RESET_CLOCK) = timer wake — authoritative over latch. */
    if (cause & RESET_CLOCK) {
        LOG_INF("Wake: timer (GRTC)");
        cached_reason = WAKE_REASON_TIMER;
    } else if (latch || ext_latch || (cause & RESET_LOW_POWER_WAKE)) {
        LOG_INF("Wake: button%s%s", latch ? " [P0.09]" : "",
                ext_latch ? " [D2]" : "");
        cached_reason = WAKE_REASON_BUTTON;
    } else {
        LOG_INF("Wake: reset (cause=0x%08x)", cause);
        cached_reason = WAKE_REASON_RESET;
    }

    reason_valid = true;
    return cached_reason;
}

/* Suspend SPI bus that drives SX1262 */
static void peripherals_suspend(void)
{
    const struct device *spi = DEVICE_DT_GET_OR_NULL(DT_NODELABEL(spi23));
    if (spi != NULL) {
        pm_device_action_run(spi, PM_DEVICE_ACTION_SUSPEND);
    }
}
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

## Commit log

2026-07-27 Initial open-source release
    TanenBase: LoRaWAN beehive monitor on XIAO nRF54LM20A + Wio-SX1262.
    Weight (NAU7802), temperature (DS18B20), battery (nPM1300); ~4 uA sleep,
    BLE/Web-Bluetooth provisioning, delta-based uplink to TTN.
    Release prep in this commit:
    - Apache-2.0 LICENSE + NOTICE, README, CONTRIBUTING, CHANGELOG
    - docs/ reorganized and re-pointed from nRF54L15 to nRF54LM20A; TRD gained
    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
    [XIAO_nRF54L15 V1-B_Cu.gbr, XIAO_nRF54L15 V1-B_Mask.gbr, XIAO_nRF54L15 V1-B_Silkscreen.gbr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]
2026-08-08 fix(weight): widen flush CR timeout to sinc settle time
    First CR after CS / offset-cal lands ~300-350 ms out (sigma-delta sinc
    filter refill), not 100 ms. Old 50+200 ms budget missed it on every cold
    init; loop breaks on timeout, so the startup transient was never actually
    flushed. Warm path failed at flush[1] not flush[0] because a stale latched
    CR consumed the first iteration -> settle budget must apply to every
    iteration.
    CONV_SETTLE_MS = 5x100 ms in both paths. Ceiling, not delay: settled
    samples still return in ~100 ms.
    Costs ~0.5 s awake per wake since the flush now genuinely runs. Reading
    quality unchanged (weight_read's cluster filter already absorbed the
    transient) - cut flush cou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
    [weight.c]
2026-08-08 build: allow compiling out BLE and LoRa independently
    ble_svc.c behind target_sources_ifdef(CONFIG_TANENBASE_BLE_CONFIG) - fsm.c
    already guards every call site. lora.c body behind CONFIG_LORAWAN with
    -ENOTSUP stubs rather than dropping the TU, so the FSM's tx_pending retry
    path stays exercised.
    Lets a build isolate radio-vs-sensor faults without touching call sites.
2026-08-08 docs(Error): NAU7802 flush CR timeout — timing issue + fix (PR #1)
2026-08-08 Power Profiler Using PPK2
    [LoRa uplink.csv, Measure.csv]
2026-08-15 feat(weight): temperature-compensate the load cell
    350 g p2p on a constant 22 kg load over a 17.5 K daily cycle, uncompensated.
    Two-parameter correction (gain + one-pole lag filter on the probe temp) cuts
    residual sigma 102.2 -> 15.7 g. Fixed-point Q16, no float.
    - tempcomp.c: filter + correction, ported from the characterisation report.
    Bit-exact replay of the dataset reproduces the report's numbers.
    - t_eff persisted in ZMS (id 18): System OFF wipes RAM, and a filter that
    re-seeds every cycle has no memory to lag with. Saved once per cycle in
    fsm.c, not per measure_run, so the 2 s BLE live view can't hammer ZMS.
    - dt: ms_interval for a wake's first sample (no wall clock across Syste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
    [Loadcell_B.csv, Loadcell_B_compensated.csv]
2026-08-15 docs: field photos, test clip, compensation chart in README
    tanen.jpg dropped -> platform.jpeg is the new hero. Adds the platform side
    view, both load-cell mount shots, the before/after compensation chart, and a
    link to the bench-test clip (GitHub won't play repo-hosted mp4 inline).
    Credits Claude Code for the drift analysis and correction formula.
2026-08-15 docs(loadcell): field validation protocol, gates the merge
    Correction is bench-verified only. Records what the field test has to look
    like before this ships.
    Key trap: the uplink carries corrected weight only, and T_eff is driven by
    every 5 min measurement while uplinks fire 4-hourly — raw is unrecoverable
    from the received series. Set ms_interval == tx_interval for the window and
    the filter can be re-run offline instead. Needs a dead weight, not a colony:
    on a live hive real mass change and drift are not separable.
    Pass: weight-vs-temp slope inside +/-3 g/K (raw is -17.7).
2026-08-22 docs(loadcell): field validation passed — +1.10 g/K, sigma 11.6 g
    144 h outdoors, 22.2 kg dead weight, correction live. Every measurement
    transmitted, so T_eff is reproducible offline and the uncompensated series is
    recoverable by inverting the correction — both curves are the same samples.
    Dry window (64.9 h, 19.5-34.0 C):
    slope -16.64 -> +1.10 g/K (gate was +/-3)
    sigma 63.1 -> 11.6 g (5.5x, beats the 15.7 g bench prediction)
    r2 vs T_eff 0.971 -> 0.126
    Days 4-6 are rain, not drift. The 08-21 event put +220 g on in 2 h while
    T_eff moved 0.38 K — thermally that needs -582 g/K against a -17.7 model.
    506 g of water still retained at the end. Fitting drying + thermal acr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
    [Loadcell_B_test2.csv]
2026-09-01 fix(ble): radio test sent 1-byte uplink, decoded as phantom 255
    ConfigCmd 0x04 sent {0xFF}. Both TTN decoders bail on bytes.length < 8,
    so BEEP fell back to the raw byte and showed 255.
    Now sends the real 8-byte frame via transmit_run() (flags=0, unconfirmed).
    Measure before init/join: measure_run() takes 2-3 s and would otherwise
    land inside a JoinAccept/RX window. Total sensor failure no longer aborts
    the test — valid=0 emits the all-sentinel frame, still decodable.
    Docs: CmdStatus result-code table in PLAN.md, incl. tare code 4 (partial
    tare — offset committed, T_ref not).
    [ble_svc.c]
2026-09-01 feat(power): second TanenButton on D19, anomaly [37] workaround
    External button on D19 = P0.00 (XIAO bottom pad). button_arm_sense()
    arms both it and the on-board P0.09; the two latches are OR-ed, read
    separately only so the log says which fired. Carrier v0.1 does not route
    D19 — flying wire until v0.2.
    Anomaly [37]: System OFF current above spec when entered soon after a pin
    reset or power cycle. Write 1 to POWER 0x5005340C before poweroff; the
    GRTC prepare that follows covers the >= 40 cycle wait.
    Docs corrections, all previously wrong:
    - D5 = P1.07 is LORA_RF_SW1, not a spare GPIO. Never pull or sense it.
    - Wio-SX1262 ships K1 + 10K pull-up on D0, the 1-Wire net. With them
    fitted th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
    [power.c]
2026-09-01 feat(web): rebuild config app, split downlink encoder into its own page
    index2.html redesign promoted to index.html (DE/EN/AR, guided setup
    wizard, device.svg + logo.svg); index2.html deleted.
    Command encoder moved out to encoder.html — FPort 10-13, emits fPort +
    hex + base64 for the TTN console and a down/push body for the API. No
    Bluetooth, so it works with no node in range.
    web/ is no longer one file: README, BUILD_ENV and ARCHITECTURE said
    "single file" and README linked the encoder at the now-deleted
    index2.html. Fixed. CHANGELOG updated for everything since the last push.
2026-09-09 feat(power): move external TanenButton D19 -> D2, shares SX1262 NRESET
    D2 is on a 7-pin header the carrier already routes; D19 = P0.00 is a bottom
    pad needing a flying wire. Bare switch to GND, no external parts: the internal
    pull-up holds NRESET high in System OFF, replacing the old drive-HIGH, so the
    radio keeps sleeping.
    A press resets the SX1262 too. Free: every wake is a full SoC reset, and
    sx126x_variant_init() configures reset-gpios GPIO_OUTPUT_ACTIVE (active low),
    so it drives NRESET low at device init anyway. Awake — 0.2% of the time, 185 s
    per day at MS=900/TX=14400 — the pin is a driver output and the press is not
    latched; the SETUP LED tells the user to press again.
    Datashe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
    [power.c]
2026-09-09 feat(ttn): one decoder for BEEP + beelogger, docs for both
    tanen-decoder.js parses the 8-byte frame once and emits both key sets in
    one decoded_payload — weight_kg/t/bv for BEEP, Gewicht/TempOut/VBatt for
    beelogger. Each server keeps what it knows. Invalid sensors -> null on
    both sides. Replaces juggling a formatter per platform; custumdecoder.js
    (byte-identical to beepdecoder.js) dropped, the two single-platform ones
    kept for reference.
    Both ingestion paths confirmed live:
    - BEEP: webhook needs ?key=<DevEUI>
    - beelogger: community.beelogger.de/<user>/{/devID}/beelogger_log.php
    ?Passwort=<pw>&LORA=1 — {/devID} filled by TTN, devices named
    beelogger1..N, shared password, so one webho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
2026-09-09 feat(site): landing page, names BEEP and beelogger
    tanen.eu landing page (de/en/ar) enters the repo; LoRaWAN card gains a
    bullet for the ready-made link to both platforms via TTN.
2026-09-09 feat(site): own section for BEEP and beelogger
    Ein Aufzaehlungspunkt reichte nicht — die Anbindung ist ein Kaufgrund.
    Neuer Abschnitt "Wo Ihre Daten landen" hinter den Merkmalen: je eine
    Karte pro Plattform mit Nutzen, zwei Stichpunkten und Knopf auf
    beep.nl bzw. beelogger.de, dazu der Hinweis, dass derselbe Funkspruch
    beide Formate liefert. Navigation (Kopf + Fuss) um "Plattformen"
    ergaenzt, #why von band-white auf band gedreht, damit die Baender
    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
2026-09-10 docs(power): pack is 3x AAA Li/FeS2, 4.6 y, over the VBAT window
    Deployed units run three AAA 1.5 V lithium-metal cells in series
    (1200 mAh, 4.5 V nom, 5.2 V measured fresh), not the ER14505 AA
    Li-SOCl2 the docs still described.
    Life at 15 min / 2 h: 9.3 y -> 4.6 y (1080 mAh usable / 0.638 mAh per
    day); ~10 y at 60 min / 4 h. Per-schedule table in POWER_BUDGET §5.
    Numbers are conservative — they reuse the 3.6 V PPK2 charges with no
    buck scaling; ~20 % better if §7 scaling holds, unverified.
    Gains: no passivation (drops the depassivation step and first-TX sag),
    -40 °C rating (closes the cold-temp open question), ~10x pulse margin
    where the ER14505 was the marginal 91 mA row.
    Cost, rec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
2026-09-10 docs(power): BEVIGOR cells, handbook data corrects the VBAT deviation
    Cells are BEVIGOR AAA Li/FeS2. Pulled Energizer's LiFeS2 handbook
    (LA522) in as the chemistry reference; it corrects three things I had
    wrong yesterday:
    - "OCV is highest when cold" was backwards. The low-drain plateau is
    1.79 V/cell @ 21 C and RISES with temperature. Worst case is a hot
    hive, not a winter one.
    - At uA drain the chemistry holds that plateau "nearly independent of
    depth of discharge", so the pack sits above the nPM1300's 4.45 V
    recommended VBAT max for essentially its whole life — not just while
    fresh, as §5.2 claimed.
    - Fresh OCV spec spread is 1.79-1.83 V, so a worst-case pack is 5.49 V
    ag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
2026-09-13 feat(firmware): Extended Mode, up to 3 SwitchBot BLE T/H sensors
    - ext_sensors: active scan, SwitchBot mfr/svc data parse, early exit
    - scan only on TX wakes, before lora_init, 8 s cap
    - uplink +5 B per sensor heard (8-23 B), flags bit3 = sensor missing
    - ZMS id 20 slot config, GATT 0x000E ExtConfig / 0x000F ExtLive
    - validate: max 2 in-hive, max 1 outside, unique MACs
    - scan window == interval (SDC scheduling priority)
    - fix: BLE sensor I/O on preemptible sensor_wq, not coop sysWQ;
    gpio-I2C spin w/o load cell starved BT + main -> watchdog reset
    [ble_svc.c, fsm.c]
2026-09-13 feat(ttn): decode Extended Mode blocks for BEEP + beelogger
    - block count from frame length, (len - 8) / 5
    - outside sensor -> t/TempOut, 1-Wire -> t_0
    - in-hive -> t_i/h_i, TempIn/FeuchteIn, TempIn2/FeuchteIn2
    - SwitchBot BLE format + original beelogger formatter as references
2026-09-13 feat(web): Extended tab, QR scan, live BLE sensors
    - Erweitert tab: master switch, 3 slots, MAC or QR, role limits
    - BLE sensors on overview; tab hidden on old firmware
    - jsQR 1.4.0 vendored (NOTICE), lazy-loaded w/o BarcodeDetector
    - German: Sensor instead of Fühler; home-page link
2026-09-13 docs: Extended Mode, TX + BLE scan 139 mC power budget
    - POWER_BUDGET: 139 mC / 11.13 s (PPK2 csv), life 4.6 -> 3.3 y at 15 min / 2 h
    - ARCHITECTURE, TRD, manual 3.7, CHANGELOG
    - README showcase: sensor photo + live setup screenshot
    [LoRa uplink_extend_mode.csv]
2026-09-13 feat(site): Extended Mode section, Cloud wording
    - #ble section: sensor photo + live screenshot, nav link, spec rows, DE/EN/AR
    - "keine Cloud" instead of "keine Zwangs-Wolke"
    - hero bee photo + phone screenshot media
2026-09-13 fix(web): QR scan reads small sensor labels
    - 1920x1080, continuous focus, 2x zoom where supported
    - scan enlarged centre (aim square) + full frame alternately
    - BarcodeDetector error -> jsQR fallback, no silent loop
    - photo fallback via camera app, tiled search
    - info line: reader, resolution, zoom
2026-09-22 feat(load-cell): runtime-selectable cell profile
    Firmware no longer tied to the H40A. Which cell is fitted is a ZMS
    setting (id 21) picked on the setup page: generic (no correction),
    H40A-C3-0150 (measured 17.734 g/K, 25 min), four named-but-unmeasured
    cells (SBS-PF-150, Zemic L6E, TAL220, Flintec PC/SB — gain 0, so they
    behave like generic but the unit records what is fitted), or own
    measured values.
    tempcomp reads gain/tau from the profile instead of Kconfig, so one
    image serves every frame. New GATT char 0x0010 (10 B); a read returns
    the EFFECTIVE constants, so the web page needs no copy of the table.
    Non-custom profiles resolve from the table on every read, so a later
    firmware can fil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
    [ble_svc.c]
2026-09-22 fix(flash): commit the final RRAM line, then verify
    openocd load_image leaves the final PARTIAL 16-byte RRAM line in the
    controller write buffer, so the last 4/8/12 bytes of every image were
    never programmed. Silent, and it does not look like a flashing fault.
    Cost a day: boot loops, HardFault at z_arm_exc_spurious, and a BUS
    FAULT at BFAR 0x9 inside net_buf_alloc_len during bt_enable — so
    "button never reaches SETUP" in production, since the reboot after the
    crash is a RESET wake and fsm_run() skips SETUP on reset. .last_section
    sits at the image end with net_buf_pool_area against it, so the dropped
    tail truncated a pool's RAM pointer to 0xFFFFFFFF; 0xFFFFFFFF + 0xA
    wraps to 0x00000009,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
2026-09-22 docs(fsm): correct the wake-reason docstring
    Header claimed "Button/Reset -> SETUP"; fsm_run() enters SETUP only on
    WAKE_REASON_BUTTON. Reset goes straight to MEASUREMENT on purpose, so a
    boot loop cannot sit in a 180 s advertise window — which also means a
    just-flashed unit does NOT come up in SETUP.
2026-09-29 site: replace platform photo with Bühl apiary use case and live dashboard
    Removes the platform caption from 'Aus der Praxis' and adds a Bühl
    section: hive photo, Burg Windeck gateway, 3.6 km link map, hourly
    transmission, and an embedded beelogger dashboard (de/en/ar).
    Claude-Session: https://claude.ai/code/session_01XjP938as1aGYTqsa85y2hM
2026-09-29 site: replace blocked beelogger iframe with a link card
    beelogger refuses to be framed on other sites, so the embed showed
    'Dieser Inhalt ist blockiert'. Link to the dashboard instead.
    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
2026-09-29 site: new Tanen BLE sensor photo
    Replace the hand-held BLE sensor photo with the clean label shot, cropped to
    the 460x996 slot beside the setup-page screenshot. Alt texts (DE/EN/AR and
    README) no longer mention a hand.
2026-09-30 site: live setup-page demo in the hero phone
    Replace the setup-page screenshot in the hero phone with phone-demo.html,
    a static replica of the setup page's Overview tab: same stylesheet as
    setup/, connection pill with the 3:00 countdown (yellow at 1:00, red at
    0:30), back-to-home button, weight/temperature/battery and one Bluetooth
    sensor inside the hive. Sample values drift slightly; the demo follows the
    home page's language (DE/EN/AR, RTL). Drawn at 420x910 and scaled to the
    phone frame.
2026-09-30 site: faster demo values, demo in BLE section, footer credit
    - phone-demo.html: sample values update every 1.2 s instead of 4 s
    - Bluetooth section: replace ble-sensors-screen.jpg with the same live
    setup-page demo; the scaler now fits every .phone-demo box (contain,
    centred) and language changes reach all demos
    - Footer: "© 2026 TanenBase by Hussein Daj", name links to LinkedIn
    (DE von / EN by / AR من إعداد)
2026-09-30 fix(lora): keep ADR working across System OFF
    - build lora.c with REGION_EU868/SOFT_SE: app saw 728 B NVM vs lib 1120 B,
    save dropped CFList ch3-7 -> every LinkADRReq NACKed, DR stuck
    - persist pending MAC answers (LinkADRAns etc.) across sleep
    - lora_init idempotent: 2nd call per boot looped dl callbacks -> WDT reset
    - post-join DR = join DR; step down from current DR; rejoin after 8 no-ACKs
    - probe every 4 uplinks; no-ACK probe not a TX failure
    - SF12 fair use: skip odd routine uplinks, join backoff 1/2/4/8 h
    [ble_svc.c, fsm.c]
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2026-10-02 feat(load-cell): SBS-PF-150 characterised, profile 2 = 10681 mg/K
    Fit from a 114 h production week on 10 kg water, profile 0:
    k -10.68 g/K, sigma 45 -> 21 g, hold-out k stable to 2 %.
    Report, script, figures in docs/load_cells/SBS-PF-150/.
    Setup page: measured-cell hint for profile 2. Field validation pending.
2026-10-11 feat(lora): ABP activation, set in setup page Network tab
    For field sites where downlinks fail: no join, sends from first wake.
    - OTAA|ABP switch, DevAddr/NwkSKey/AppSKey, ADR or fixed SF7-12
    (fixed = unconfirmed only, no downlink needed)
    - GATT 0x11-0x14, ZMS 23-27
    - FCntUp kept per DevAddr outside session blob
    - stale session (mode/creds changed) discarded on restore
    - ABP never rejoins; band defaults match TTN ABP assumptions
    - scripts/deploy_web.ps1: FTPS upload of web/ with backup + verify
    - docs: LORAWAN.md §13 (TTN setup), ARCHITECTURE, CHANGELOG
2026-10-11 feat(site): consent-gated analytics, legal pages, field use cases
    - GA loads only after consent (banner on landing page; setup page
    honours the same choice)
    - Impressum + Datenschutz pages, robots.txt, sitemap.xml
    - Praxis section: Bühl and Wintersdorf installs, tech specs, press
    - phone-demo.html; media for both sites
    - scripts/deploy_site.ps1: FTPS upload of site/ with backup + verify
2026-10-14 fix(main): print the firmware version from Kconfig
    The 1.0.0 boot log still said "TanenBase v0.3.0". That is the first line
    of every field log, so a stale literal there sends diagnostics after the
    wrong release.
    CONFIG_TANENBASE_VERSION is now the only copy of the version; main.c
    prints it and src/ holds no version literal. Bump it in the release
    commit together with the CHANGELOG heading and the tag.
2026-10-14 test: host unit tests for tempcomp and the FSM
    tests/host builds src/features/measurement/tempcomp.c and src/core/fsm.c
    with the host compiler against a hand-written sliver of the Zephyr API
    (stubs/), under -Werror and ASan/UBSan. No SDK, under a second, and a
    separate build from the firmware; CI runs it as its own job.
    tempcomp: alpha_q16() edge cases (dt = 0, tau = 0, both, uint32 extremes,
    bounded and monotonic), convergence to a constant input, no overshoot
    when dt dwarfs tau, an exact int32 correction across the DS18B20's whole
    range at the largest storable gain, gain 0 as an exact no-op, re-seed on
    non-timer wakes, and tare anchoring on t_eff. Three golden files from
    tests/host/gen_go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
2026-10-14 refactor(ble_config): split ble_svc.c into lifecycle, GATT and commands
    ble_svc.c was 1,101 lines, 3x the next largest file, and every BLE
    change touched all of it. Pure move, no behaviour change:
    ble_svc.c connection lifecycle, advertising, live notifies,
    ble_config_run() (365)
    ble_svc_gatt.c GATT table + config characteristic handlers (525)
    ble_svc_cmd.c ConfigCmd parser, tare/calibrate, LoRa test (238)
    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
2026-10-14 docs(tempcomp): correct the alpha_q16 approximation-error comment
    The comment said the RC form is "within a couple of percent up to
    dt = tau". It is always low: 2 % at 60 s, 8 % at the default 300 s and
    21 % at dt = tau (tau = 1500 s). State what that costs instead: the
    filter behaves as the exact one with tau_eff = dt / ln(1 + dt/tau),
    27.4 min instead of 25 at 300 s, inside the broad tau optimum; on the
    H40A run t_eff stays within 0.16 K of the exact filter and sigma is
    15.67 g against the 15.7 g fitted with exp(). Comment only.
2026-10-17 feat(brand): tagline "Ihr Bienenvolk gibt Ihnen Entwarnung."
    Hero headline in DE/EN/AR: "Ihr Bienenvolk gibt Ihnen Entwarnung." /
    "Peace of mind for your hive." / "خلية النحل تطمئنك عنها." (Hussein's
    own line). og:title carries it; new German share card
    site/media/share-card.png (1200x630) replaces the Wintersdorf photo as
    og:image. media/brand/share-card.html now renders both cards (?lang=de
    for tanen.eu, ?lang=en for the GitHub social preview). Page title and
    meta description unchanged, they hold the search terms.
2026-10-17 feat(brand): printable device label with TTN QR code and brand sticker
    web/label.html prints 29x90 mm labels (Brother QL-500, DK-11201). Device
    label: LoRaWAN TR005 QR (LW:D0:JoinEUI:DevEUI:profile) for the TTN
    console's QR scan, DevEUI and JoinEUI as text, never the AppKey. Brand
    sticker: mark, wordmark, tagline in DE/EN/AR. Black only for thermal
    print; black lock-up/wordmark variants from outline_wordmark.py.
    qrcode-generator 1.4.4 (MIT) vendored as web/qrcode.js for offline use.
    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
2026-10-18 style(web): shorter setup texts, compact home button
    Beekeepers found the setup app too wordy. 25 always-visible hints, notes
    and step texts cut to one short line in DE/EN/AR (load-cell notes, network
    hints, "Üblich: 5 Minuten." instead of three sentences). Error messages,
    headings and buttons unchanged.
    Home link ("Startseite"/"Home"/"الرئيسية") and the encoder's back link
    ("Zurück") are now sized to their text instead of a full-width bar on
    phones.
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
